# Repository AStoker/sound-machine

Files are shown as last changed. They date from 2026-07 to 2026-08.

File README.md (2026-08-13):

# Sound Machine

ESPHome firmware for a bedside smart sound machine built on a ReSpeaker Flex
(XVF3800 + XIAO ESP32-S3): white/pink/brown noise, voice assistant, an LED-matrix
clock, an SK6812 sunrise crescent, and battery/UPS monitoring.

## Prototype 1, finished

The machine as built and in service: a printed two-tone shell behind a single
acoustic-cloth face, with the knob capping the top.

| | |
|---|---|
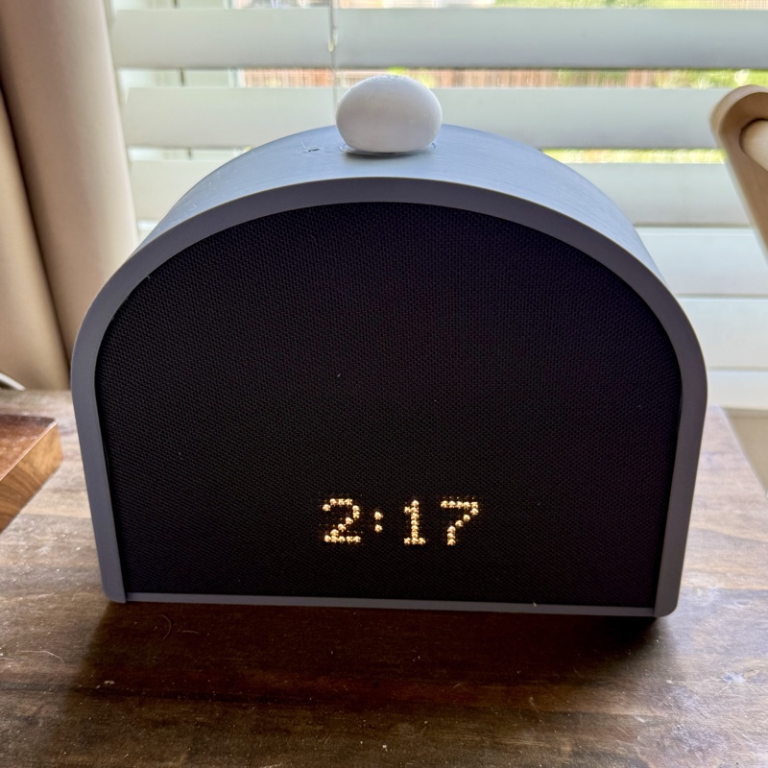
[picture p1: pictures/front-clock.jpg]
Front of the finished sound machine, showing the time on the LED matrix through the cloth face
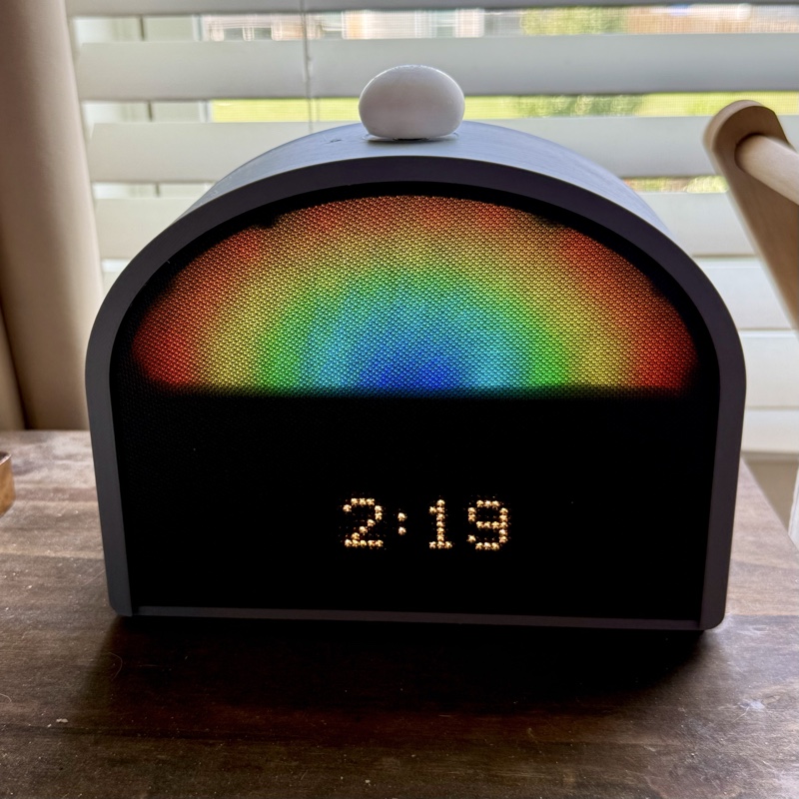
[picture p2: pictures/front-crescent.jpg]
Front view with the SK6812 crescent lit in a rainbow above the clock
|  |  |
| **Resting.** The IS31FL3731 matrix reads through the cloth and nothing else does — the crescent above it is dark and invisible. Brightness tracks room light via the BH1750, so this is the daytime level. | **Crescent lit.** The 48-px SK6812 arc diffused by the same cloth, here cycling hue. It sits in the upper dome; the clock keeps its own space below. Capped at `led_max_pct: 25 %` — see the brownout note in `CLAUDE.md`. |

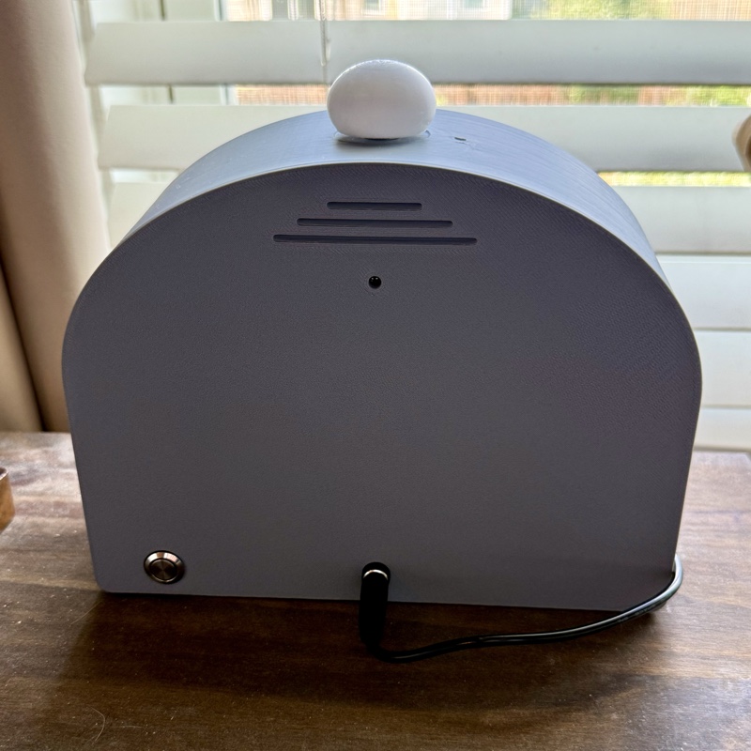
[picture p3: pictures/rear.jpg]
Rear of the enclosure showing the vent stack, the BH1750 light pipe, the power switch and the DC barrel jack


**Rear.** The body is a plain extrusion, so the back is one flat face: the single
wide vent stack up top, the BH1750's light pipe centred below it (the small hole
— that sensor is what auto-dims everything you see in the other two photos), the
power switch, and the centred barrel jack feeding the 3S UPS. The pebble on the
crown is the knob — turn for volume, tap/hold for sound; the ToF's pinhole is the
speck just to its right in the first photo.

## Layout

| Path | What |
|---|---|
| `soundmachine.yaml` | Device core + the package manifest (the build entry point) |
| [`packages/README.md`](packages/README.md) | **The architecture map** — start here to change firmware behavior |
| `packages/settings.yaml` | Every tunable in the build, in one documented file |
| `packages/hw/` | One file per physical part (matrix, crescent, knob, UPS, sensors…) |
| `packages/api/` | The abstraction layer — `display`, `sound`, `light`, `indicator` |
| `packages/behavior/` | Operational logic: presets, gestures, announcements, voice |
| `components/` | Custom ESPHome components, named for their job rather than their chips: `clock_display`, `noise_generator`, `ambience_player`, `background_sound`, `speaker_amp`, `rotary_knob`, `shared_helpers` |
| `sounds/` | On-device audio baked into flash |
| `soundmachine.min.yaml` | Reference minimal device YAML for Home Assistant |
| `secrets.example.yaml` | The secret keys you must provide locally |
| `3d-print/` | The enclosure: parametric geometry, generators, validation, printable solids |
| `pictures/` | Photos of the assembled v1 machine (shown above) |
| [`FUTURE-DEVELOPMENT.md`](FUTURE-DEVELOPMENT.md) | Every open item, one numbered entry each |
| [`RETROSPECTIVE.md`](RETROSPECTIVE.md) | What building v1 taught |

## Running it from Home Assistant (pull latest from GitHub)

The full config lives here on GitHub. Home Assistant keeps only a tiny device
YAML that pulls this repo as an ESPHome **remote package**, so every build
compiles the latest `main`.

1. Copy [`soundmachine.min.yaml`](soundmachine.min.yaml) into your HA ESPHome
   config folder (rename it if you like — the filename becomes the device).
2. Add the keys from [`secrets.example.yaml`](secrets.example.yaml) to that
   folder's `secrets.yaml` with real values.
3. Compile/install from the ESPHome dashboard.

That's it — the device config, the custom `components/`, and the packaged
sub-configs are all fetched from this repo at build time.

### How it works

- Credentials are **substitutions**, not `!secret` — remote packages can't
  contain secret lookups. The minimal device YAML injects them from the local
  `secrets.yaml`, overriding the placeholders in `soundmachine.yaml`.
- The custom components are pulled via a **git** `external_components` source
  (`github://astoker/sound-machine`) so they resolve identically locally and on
  HA. For local component development, push first then build (or temporarily
  switch that source back to `type: local, path: components`).

## Building locally

```sh
# create a secrets.yaml next to soundmachine.yaml with the 5 keys, then:
esphome config soundmachine.yaml     # validate
esphome run soundmachine.yaml        # build + upload
```

## On-device media (the `la_la_sad_source` substitution)

ESPHome resolves a local `file:` path against the config directory of whichever
machine runs the build. When HA pulls this repo as a remote package, that
directory is HA's — not this repo — so a bare `sounds/…` path wouldn't be found
there even though the file lives in the repo. So the media source is a
substitution, `la_la_sad_source`, defaulting to a raw GitHub **URL** that
ESPHome downloads at build time (works everywhere; verified). For local/offline
dev with the repo checked out, override it with the repo-relative path:

```yaml
# in a local dev entry YAML (or temporarily in soundmachine.yaml substitutions)
substitutions:
  la_la_sad_source: sounds/La-la-sad.mp3
```

Any additional flashed audio should follow the same pattern: add a
`<name>_source` substitution (URL default) rather than a bare path. Note the
ordering that implies: the URL only resolves once the file is on `main`, so a
new track is **pushed first, built second** — or built locally with the path
override above.

**Size.** Flashed media is compiled into the app image and shares the 3.75 MB
app partition with the firmware. With both current tracks (`La-la-sad`,
`Crickets`) that image is 3.0 MB, leaving ~760 KB. `esphome compile` prints the
remaining space; check it after adding one.

## Status

**Prototype 1 is built and in service** — printed, wired, assembled, running
(photos at the top). Ongoing work is firmware. See
[`SOUNDMACHINE.md`](SOUNDMACHINE.md) for what the machine does,
[`FUTURE-DEVELOPMENT.md`](FUTURE-DEVELOPMENT.md) for what is still open, and
[`RETROSPECTIVE.md`](RETROSPECTIVE.md) for how it got here.

The full v1 development history is preserved on the **v1 release branch**; `main`
carries the conclusions.

## Notes

- The UPS monitor is **confirmed** as an INA219 at `0x41`. Its shunt value
  (`ups_shunt_ohms`, `0.01 Ω`) is still taken from documentation rather than
  measured — voltage and state-of-charge don't depend on it, absolute current and
  power do.

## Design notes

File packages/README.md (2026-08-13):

# The package layout

The firmware is split into three layers. The split exists so that a change has
exactly one plausible home: a new sensor is a `hw/` file, a new way to reach an
existing subsystem is a verb in `api/`, and a new *rule* about when things happen
is a `behavior/` file.

```
soundmachine.yaml        device core: platform, WiFi/API/OTA, the I2C bus, the manifest
packages/settings.yaml   every tunable in the build, grouped and documented

packages/hw/             THE PARTS.      One file per physical device.
packages/api/            THE ABSTRACTION. One file per subsystem.
packages/behavior/       THE LOGIC.      What the device actually does.
```

## The three layers

### `hw/` — one file per part

Owns a device's component config and the only register/pin-level talk to it.
Also owns *hardware interpretation*: lux to a brightness level, metres to "a hand
is near", volts to a state of charge. Interpretation belongs here because it is
about the physics, not about this device's choices.

A `hw/` file contains no policy. It never decides that a low battery deserves a
warning or that a knob turn means volume.

### `api/` — one file per subsystem

The abstraction layer. Everything else reaches a subsystem **through these
scripts**, never through its hardware. Each api file is the single writer of the
hardware behind it, which is what makes the invariants enforceable:

| api file | is the only writer of | key verbs |
|---|---|---|
| `api/display.yaml` | the display driver | `display_show_code`, `display_show_status`, `display_set_alert`, `display_show_message` |
| `api/sound.yaml` | the audio chain | `noise_play`, `noise_stop`, `ambience_play(name)`, `ambience_stop`, `media_stop`, `volume_apply`, `sound_duck`/`sound_unduck` |
| `api/light.yaml` | the crescent strip | `crescent_off`, `crescent_static`, `crescent_effect` |
| `api/indicator.yaml` | the knob NeoPixel | `indicator_set_hue`, `indicator_flash`, `indicator_glow_set` |

An api file may also own the *mechanism* that its hardware needs and callers
should not have to think about: the display's channel priority and heartbeat, the
indicator's fade and I2C write-throttling, the audio stack's boot gate.

### `behavior/` — the operational logic

Presets, gestures, announcements, boot restores, and the Home Assistant control
surface (selects, switches, numbers, buttons, text). Behavior decides; api does.

## The two rules

**1. Writes go through the api. Reads do not.**

A behavior package must not start the noise generator, build a `LightCall`, or
write an I2C register — it calls a verb. But reading state is free and expected:
`external_media_player->volume`, `id(battery_low).state`, `id(hand_near)`,
`media_player.is_announcing`. Routing reads through scripts would buy nothing —
ESPHome scripts cannot return a value — and would cost a lot of clarity.

**2. Hardware raises events; behavior implements them.**

A `hw/` file with an input on it calls one script per event, named after the
event. The handler is defined in the matching `behavior/` file. That way hardware
declares a contract without knowing who fulfils it, and remapping a control never
touches anything that talks to a bus.

| event script | raised by | implemented in |
|---|---|---|
| `on_knob_turn(clicks)` / `on_knob_tap` / `on_knob_hold` | `hw/knob.yaml` | `behavior/sound.yaml` |
| `on_touch_tap` / `on_touch_hold` | `hw/touch.yaml` | `behavior/light.yaml` |
| `on_hand_near_changed` | `hw/proximity.yaml` | `behavior/sound.yaml` |
| `on_external_power_changed` / `on_battery_low_changed` | `hw/power.yaml` | `behavior/power.yaml` |
| `on_audio_ready` | `api/sound.yaml` | `behavior/sound.yaml` |

These are hard dependencies: ESPHome resolves script ids at validate time, so
dropping a `behavior/` file whose events are still raised fails the build. That
is deliberate — it is the compiler telling you a contract is unmet.

**One event per fact, not one event per subsystem.** `hw/power.yaml` raises a
separate event for each of its two sensors. It used to share one, and the handler
then had to reconstruct *what* had changed from sensor state — which cost a
`has_state()` guard, an extra global, and a paragraph of explanation. A
binary_sensor's `on_state` is already edge-triggered, so one event per sensor
makes "this changed" the event itself.

## Things worth knowing before you edit

**All ids are global after the merge.** ESPHome merges every package into one
config, so a cross-package `id()` reference works — but each id must be defined
exactly *once*. Every file's header lists what it DEFINES and what it CONSUMES;
read those two lines before adding anything.

**Top-level list keys concatenate.** `sensor:`, `script:`, `globals:`,
`interval:`, `esphome.on_boot:` and friends accumulate across packages. That is
how several files can each add their own boot step or their own tick.

**Substitutions are global too, and local wins.** `settings.yaml` is a package
like any other, so the tiny device YAML on Home Assistant can override any value
in it. ESPHome merges packages *before* it expands `${...}`, which is why a
setting defined in one file is usable in all of them.

**The display is split into policy and driver, and not for pluggability.**
`api/display.yaml` decides *what* to show — priority between competing overlays,
expiry, which default view sits underneath them, clock formatting — and
`components/clock_display` draws it. There is one display and no plan for another;
the split earns its keep because those are two unrelated problems. The contract
between them is a struct, `clock_display::Frame`, so it is checked rather than
described: `api/display.yaml` builds one as a local and calls
`id(matrix)->paint(frame)`.

**The driver must self-throttle.** `api/display.yaml` ticks several times a
second and calls `paint()` every time. The driver compares the frame with what it
last drew and returns before touching I2C when nothing changed. ~300 bytes on this
100 kHz bus is ~30 ms of bus time, on a bus that had to be slowed down for the
XVF3800 in the first place.

**Register-level code is a component, not a lambda.** Anything that talks to a
chip in raw registers lives in `components/` as C++ (`clock_display`, `speaker_amp`,
`rotary_knob`, `noise_generator`, `ambience_player`), and the matching `hw/` file is just its
configuration. A YAML lambda is fine for interpreting a reading; it is the wrong
home for fonts, framebuffers and decoders.

**Chips with no NVM repair themselves.** The matrix, the knob's NeoPixel and the
amp all lose their configuration to a glitch on the shared 5V rail, and in every
case the symptom is silent (a dark display, a dead pixel, an amp with its AGC
back on). Each one re-asserts: `clock_display` probes an enable register on a
tick, `api/indicator.yaml` re-sends the pin config whenever the pixel settles at
black, `hw/audio_chain.yaml` re-writes the amp's four registers on a tick. If you
add an I2C part that has to be configured, give it one of these.

**State lives in `globals:`, not in lambda `static`s.** Every file's header lists
what it DEFINES, and that list is how anyone finds the device's state. A `static`
inside a lambda works but appears in no such list, so it is state a reader cannot
know exists. Where the state belongs to a driver rather than to a package, it is a
member variable in the component instead.

**So does derived state that is cached on an edge.** The low-battery alert is a
global maintained by two `on_state` handlers, and an edge that never arrives (or
a state that is already true at boot and then never changes) would leave it
disagreeing with its sensors indefinitely. `behavior/power.yaml` re-derives it on
a slow tick as well, so the events buy latency and the tick buys correctness. Any
future default view computed from a sensor wants the same treatment.

**The crescent's pixel count is not a setting.** It is derived from the enclosure
geometry and lives in `hw/crescent.yaml`. `3d-print/check_docs.py` fails the
build if it drifts from `3d-print/enclosure_geom.py`. See the note in
`../CLAUDE.md`.

## Where to add a thing

| I want to… | Do this |
|---|---|
| tune a number | `settings.yaml`, in the matching section |
| add a sensor or chip | a new `hw/` file; raise events, don't handle them |
| let something new drive the display | call an `api/display.yaml` verb — never `paint()` |
| add a display overlay (transient) | a row in `api/display.yaml`'s overlay table + a setter |
| add a display default view (what replaces the clock at rest) | a row in `api/display.yaml`'s defaults table + a setter |
| add a light preset | an option at the end of `behavior/light.yaml`'s select + a row in **both** its tables (colour *or* effect name) |
| add a noise colour | an option in `behavior/sound.yaml`'s Sound select, after the last colour |
| add a flashed sound | an `audio_file:` entry and a `name:`/`file:` pair under `ambience_player:` in `hw/audio_chain.yaml`, then that **same name** as an option in the Sound select. No new api verb, no second list. The file must be **mono 48 kHz MP3** — see `sounds/README.md` |
| change what a button does | the event handler in `behavior/` — the `hw/` file stays put |
| share a helper between two lambdas | a free function in `components/shared_helpers` — not an `esphome: includes:`, which breaks remote packages |

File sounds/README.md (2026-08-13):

# The flashed audio

Every sound in this folder is an **ambience**: something that runs until the
machine is told to stop, not a clip that ends. `components/ambience_player` decodes
these files straight into a mixer source and rewinds at end-of-file, so a loop
costs a read pointer going back to zero.

That decode path has **no resampler in it**, which is what makes the loop free
and also why the format below is a hard requirement rather than a preference.

- **Firmware side:** `packages/hw/audio_chain.yaml` declares the files;
  `packages/behavior/sound.yaml` offers them in the Sound select.
- **Why it is not a `media_player`:** `components/ambience_player/ambience_player.h`,
  and `FUTURE-DEVELOPMENT.md` T3–T5.
- **The URLs** these are fetched from at build time are in
  `packages/settings.yaml` §11 — the file is downloaded, not read from this
  folder, when the config is pulled onto Home Assistant as a remote package.

## The format

A file that does not match is refused at its first frame and logged. That is
deliberate: the alternative is what a mismatch used to do, which was play at the
wrong speed and the wrong pitch for a whole pass before anyone noticed.

| Requirement | Why |
| --- | --- |
| **MP3** | The only decoder linked in. Not WAV, not FLAC, not Opus. |
| **Mono** | The mixer source is one channel. Stereo is refused, and on a dual-mono file it was only ever doubling the size for nothing. |
| **48 000 Hz** | The mixer's rate. 44.1 kHz is refused. |
| **Xing/Info header** | Keep the VBR header ffmpeg writes by default. `ambience_player` reads its delay/padding fields to trim the codec's priming samples, and that is what makes the wrap sample-exact. Without it every loop grows ~25 ms of silence. |
| **Peak ≤ −2.4 dBFS** | Headroom for the mixer to add a TTS reply on top without clipping. Watch this across a **resample** especially: 44.1 → 48 kHz turns intersample peaks into real ones, which is how La La spent a while clipping 1064 samples at +1.65 dBFS. |
| **Level within a few dB of the others** | So swapping sounds does not need the volume knob touched. The ambiences sit at roughly −17 to −18 dBFS RMS today. |

The recipe, for a file that is **already a good loop**:

```sh
ffmpeg -i in.mp3 -ac 1 -ar 48000 -af "volume=-XdB" -b:a 128k out.mp3
```

Check the decoded peak before trusting `-X`. If the file is *not* a good loop —
if it opens or closes with a fade — see Crickets below.

## How big can a file be?

Flashed audio is compiled **into the app image**, so it competes with the
firmware for one app partition: `0x3C0000` = 3.75 MB, of which the firmware
itself is ~2.4 MB. Both files below plus everything else currently leaves
~780 KB free. `esphome compile` prints the real number ("Smallest app partition
is … N bytes free") — check it after adding one.

## The files

### La La — 48 s, mono 48 kHz 128 kbps (~770 KB)

A composed piece rather than a true ambience: it opens from silence and closes on
a deliberate ~1 s fade, so its loop point is a fade-out into a fade-in rather
than a seam. **That is the music, and it is left alone** — crossfading it would
overlap two different bars (measured 7.1 onsets/second; this is plucked guitar,
not a pad).

It was 44.1 kHz dual-mono, which cost double the bytes for an identical second
channel (L/R correlation 1.0000) and clipped 1064 samples at +1.65 dBFS once
resampled to 48 kHz. Now mono at the same bitrate — so roughly twice the bits per
channel for the same size — and attenuated 4.25 dB to peak −3.06 dBFS.

### Crickets — 59 s, mono 48 kHz 96 kbps (~710 KB)

**This file is a crossfade loop, and that is not recoverable by re-encoding.**

The source recording opened with a 65 ms fade-in and closed with an 85 ms
fade-out, and those two fades met at the loop point — a ~150 ms hole in the
ambience once a minute, which is the loudest thing a sound meant to be
unnoticeable can do. Its last 2 s are now equal-power crossfaded under its first
2 s (sin/cos, which holds RMS flat for uncorrelated noise where a linear fade
would dip 3 dB). That fills the hole and blends out the ~2 dB low-frequency step
that was also across the seam; measured, the wrap is now a shallower dip than an
ordinary moment in the recording. The 2 s that used to be the fades are gone —
hence 59 s, not 61 s.

It is +13 dB from source, which puts it within a few dB of the noise generator at
the same volume setting, while keeping peaks 2.4 dB below full scale.

> **Do not rebuild it by re-encoding an earlier `Crickets.mp3`, and do not trim
> it** — both silently restore the hole. Rebuild it with
> `./scripts/make-crickets-loop.py`, which goes back to
> `sounds/originals/Crickets-original.wav` and owns the whole chain: crossfade,
> then downmix, resample, +13 dB, encode, in that order. `--verify` reports the
> loop point without writing anything.

## Adding one

1. Put the encoded file here and commit it.
2. Add a `*_source` substitution in `packages/settings.yaml` §11, defaulting to
   its raw GitHub URL (a local `file:` path would not resolve on Home Assistant).
3. Add an `audio_file:` entry and a `name:`/`file:` pair under `ambience_player:` in
   `packages/hw/audio_chain.yaml`.
4. Add that **same name** as an option in the Sound select in
   `packages/behavior/sound.yaml`.

There is no new api verb: `ambience_play` takes the name.

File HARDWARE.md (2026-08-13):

# HARDWARE.md

Physical hardware for the Sound Machine (the "Faux Hatch"): a bedside smart
sound machine inspired by the Hatch Restore form factor — noise, voice
assistant, sunrise light, LED-matrix clock, and environmental sensing.

This file is the single reference for *what the parts are and how they connect*.
For **why the firmware is shaped the way it is**, see [`CLAUDE.md`](CLAUDE.md).
For the **project story and goals**, see [`SOUNDMACHINE.md`](SOUNDMACHINE.md).

> **Ground truth:** the tested configuration in the repo YAML is authoritative,
> not this prose. Where a value below is marked *UNCONFIRMED* it has not been
> verified on the hardware — confirm before trusting it.
>
> **Prototype 1 is assembled**, so most of this is now as-built rather than as-
> designed. Anything still marked UNCONFIRMED is a value nobody has actually
> measured, not merely one nobody has got round to — several survived assembly
> because nothing depends on them yet.

---

## Compute + audio core

| Block | Part | Notes |
|---|---|---|
| MCU | **Seeed XIAO ESP32-S3** (seats into the ReSpeaker Flex) | ESP-IDF framework, octal PSRAM @ 80MHz. `board: esp32-s3-devkitc-1`, `flash_size: 8MB` (16MB only if using the "Plus" variant). A **standard (non-Plus) XIAO ESP32-S3 is a functional drop-in** — only D0, D4/D5, D6–D9 are used, so no rear castellated pads are required. |
| Voice / DSP front end | **ReSpeaker Flex, Linear 4-mic (XVF3800)** | 4-mic beamformer + acoustic echo canceller (AEC). Split architecture: a core board plus a separate **linear-4 array board, 110 mm long with 33 mm mic spacing** (2× M3 mounting holes), joined by a 200 mm 24-pin FPC ribbon. The XIAO seats into the core board via **female headers (removable, not soldered)**. **Core board dimensions are not published** — measure them; the enclosure reserves a bay rather than assuming a size. |
| Codec | **AIC3104** (on the Flex) | I2C `0x18`. ESPHome `audio_dac` platform `aic3104`. |
| Amplifier | **TPA2016D2** stereo Class-D | I2C `0x58`. One 4Ω speaker per channel. See "Amplifier notes" below. |
| Speakers | 2× **Seeed Mono Enclosed Speaker 4Ω 5W** (SS114993346) | **50 × 45 × 22 mm sealed box** — a square-bodied enclosure, not a bare round driver. Bridge-tied outputs (see wiring cautions). The 5W rating is pure headroom — the amp tops out ~2.5W/channel into 4Ω, so the drivers loaf and can't be overdriven. **The 50 mm body width is what sets the enclosure width** — see the drawing set. |

The XVF3800 was **DFU-flashed with the 48 kHz Home Assistant I2S firmware**; the
whole audio pipeline runs at 48 kHz to match.

**Flashing caveat:** the ReSpeaker Flex's internal USB (JST) only exposes the
XVF3800, *not* the ESP32. Flashing the ESP32 therefore requires disassembly to
reach the XIAO's own USB-C. This is an accepted tradeoff.

---

## Light

| Block | Part | Notes |
|---|---|---|
| Crescent strip | **SK6812 GRBW**, 60 LED/m | **48 pixels** in **6 cut segments**. MEASURED strip: ribbon **10.0 mm** wide, cut-line pitch **16.5 mm**, **2.13 mm** thick. Data on **GPIO1 / D0**. ESPHome `esp32_rmt_led_strip` (SK6812, `rgb_order: GRB`, `is_rgbw: true`). |
| LED carrier | printed plate, **part 6** | Holds the six segments at the 12 mm standoff; screws to the back of the front module. See [`3d-print/README.md`](3d-print/README.md). |
| Diffuser | Glowforge-cut opal acrylic, **part 7** | 3 mm, generated as [`3d-print/diffuser.svg`](3d-print/diffuser.svg). **Notched** — see below. |

The crescent is a **flattened half-ELLIPSE, 89 × 62.7 semi-axes** — not a half
circle. The crown was flattened (`CROWN_K = 0.74`) to get the dome printable in
one piece on a 220 bed, so the arch is 0.74 × as tall as a true semicircle.

Row layout, bottom row first, flat side down — used by the Circadian Sunrise
effect:

| row | chord | px | ribbon (n × 16.5) | y above baseline |
|-----|---|----|---|---|
| 0 | 177.8 | 10 | 165.0 | 2.60 |
| 1 | 174.1 | 10 | 165.0 | 13.00 |
| 2 | 165.2 | 9 | 148.5 | 23.40 |
| 3 | 150.0 | 8 | 132.0 | 33.80 |
| 4 | 126.3 | 7 | 115.5 | 44.20 |
| 5 | 87.7 | 4 | 66.0 | 54.60 |

**Row pitch is 10.4, not 16.5.** It is derived, not chosen: the flattened crown
leaves only 62.7 mm of height, so the pitch is whatever gets the most pixels on,
floored at the **ribbon width** — the rows BUTT, edge to edge. That floor used to
carry a 1 mm gap and it cost three pixels: at an 11.0 pitch the crescent holds
45, at 10.4 it holds the whole 48-px reel on the same shell height. Closing the
gap was free. The grid is deliberately not square — rows are much closer together
than the pixels within a row.

**There is no fade band.** The LED field *is* the diffuser ellipse; the old
R96-inside-R117 arrangement with a 21 mm unlit band is gone. Tightest
LED-body-to-diffuser-edge gap is **2.95 mm**.

> ### ⚠️ What sets the pixel count: the ribbon, not the LED
> Every earlier layout measured the **LED body**. The thing that has to fit the
> cavity is the **ribbon**: a cut segment of *n* pixels is `n × 16.5 mm` long,
> not `(n−1) ×`, because the cut lines sit half a pitch outboard of the end LEDs
> and you cannot trim past them without losing the solder pads. On the bottom row
> that is 6.9 mm more than the LED span — an 11-pixel row is a 181.5 mm strip
> going into a 181.0 mm cavity. It never fit.
>
> The ribbon is also 10.0 mm tall against the LED's 5.2, so what must fit is a
> **rectangle**, and its binding corner is the top one.
>
> With the rows butting, `CROWN_K = 0.74` holds exactly **48** — the whole reel.
> It held only 45 while the pitch carried a 1 mm gap, and recovering 48 that way
> would have needed `CROWN_K = 0.80` and a taller shell.
>
> The cap lives in `enclosure_geom.ribbon_cap()` and is folded into
> `_crescent_row_cap()`, so it cannot be silently missed again.

> ### ⚠️ The grid is strongly non-square
> Rows are **10.4 mm** apart — butted, ribbon edge to ribbon edge — against
> **16.5 mm** between pixels along a row. A sweep up the crescent therefore
> covers ground far faster than the same sweep across it. **Any effect with
> vertical structure needs re-checking against this**, the Circadian Sunrise
> especially. Row 5 is 4 px, so there is no single-pixel apex.

`packages/hw/crescent.yaml` carries `num_leds: 48` and, as a single substitution
at the top of the file, `crescent_rows: "10, 10, 9, 8, 7, 4"`.
`enclosure_geom.crescent_rows()` is the source of truth; `gen_drawing.py` prints
the table on every run, and `check_docs.py` fails the build on a mismatch.

> **History / drift:** earlier design notes referenced a **144 LED/m** strip, an
> **XL6009 boost converter** and an **R80 / R96 / R117 circular** crescent. The
> current build is **60 LED/m on a flattened ellipse, powered directly from the
> UPS 5V rail** (~0.73 A at the 25% cap — see the power budget below). The full
> table of what changed from the original design is in
> [`RETROSPECTIVE.md`](RETROSPECTIVE.md) §4.

---

## Display

| Block | Part | Notes |
|---|---|---|
| Clock | **2× IS31FL3731 charlieplex 16×9 matrix** ([#2946](https://www.adafruit.com/product/2946), STEMMA QT / I2C) | `0x74` (left) + `0x75` (right), tiled into one 32×9 display. No native ESPHome component, so `packages/hw/matrix.yaml` drives it with **raw I2C register writes**. Auto-dims from the BH1750 via `ambient_level`. The second board needs its **ADDR jumper** moved off `0x74` (`0x75`/`0x76`/`0x77`) — set `matrix_address_2` to match. |

**Chip model.** Pixel `(x,y)` → LED `x + y*16`; PWM byte at `0x24 + LED`
(144 LEDs); LED-enable regs `0x00–0x11`; bank select via command reg `0xFD`
(`0x00` = frame 0, `0x0B` = function/config).

**Single vs dual.** The panel count is the length of `addresses:` in
`packages/hw/matrix.yaml` — one entry brings up the left panel alone with a
compact 3×5 font; two give the full 32×9 display with a 5×7 font for a real
clock. Horizontal tiling: panel *p* owns logical columns `[16p … 16p+15]`. In
single mode the second address is never touched, so an unwired 2nd board causes
no I2C errors — bring one panel up first.

**Inter-panel gap.** Two panels butted together leave a physical ~1-pixel dead
column between them (`matrix_panel_gap`, default 1). The renderer lays content out
in *physical* columns (gap included) and maps back to logical columns per draw, so
the clock stays centred across the seam and 2-character codes fall one per panel.
Adjust `matrix_panel_gap` if your panels sit farther apart or flush.

**No NVM.** A glitch on the shared 5V rail returns the panels to their power-on
state — shut down, all LEDs disabled — and nothing would report it. The driver
reads an enable register back every `matrix_probe_interval` and re-initialises any
panel that has forgotten its configuration.

What it shows, and in what order, is not this file's business: `api/display.yaml`
owns that (overlays **message → status → code**, over a default view of
**alert → clock**) and hands the driver a resolved frame.

---

## Sensors (STEMMA QT I2C daisy-chain)

| Sensor | Part | Address | Status |
|---|---|---|---|
| Ambient light | **BH1750** | `0x23` | **Implemented** — publishes the shared `ambient_level` that auto-dims the display and the knob pixel (`packages/hw/ambient_light.yaml`). Mounted rear, behind a light pipe **centred in the back wall** (see the enclosure drawing). |
| Rotary encoder | **Adafruit seesaw rotary encoder** | `0x36` | **Implemented** — volume knob + push (tap/hold) via the vendored `seesaw` component. Its built-in **NeoPixel** (seesaw GPIO **6**, `knob_led_pin`) is also live: colour = volume, blue → green → red (`packages/hw/knob.yaml` for the inputs, `packages/api/indicator.yaml` for the pixel). |
| Real-time clock | **DS3231** (driven as `ds1307`) | `0x68` | **Implemented** — battery-backed time source; HA syncs it when connected. |
| Time-of-flight | **VL53L0X** | `0x29` | **Implemented, in a limited role** (`packages/hw/proximity.yaml`) — a nearby hand pre-lights the knob NeoPixel, and that is *all* it does. The historical **touchless wake** gesture is still not built. **It does not measure distance in this enclosure:** the 3.5 mm bore is shared by emitter and receiver with no septum, so crosstalk pins every reading at ~0.024 m and the firmware detects *deviation* from that baseline instead (root cause + fix: **H4** in `FUTURE-DEVELOPMENT.md`). Mounts on the **crown, just right of the volume knob**, board turned longwise front-to-back to clear the encoder breakout — see the enclosure drawing. |

> The BH1750, seesaw, DS3231 and VL53L0X are all live in the config. The ToF is
> deliberately **non-essential**: if it is unwired or fails its probe, the knob
> pixel still works off volume changes alone.

### Board outlines and mounting holes — READ FROM THE VENDOR PCB FILES

Every one of these breakouts is mounted on a printed boss, so the enclosure needs
their **outline and hole pattern**, not just their address. Adafruit publishes the
Eagle board for each; the numbers below are read out of the `<element
MOUNTINGHOLE_*>` entries and the layer-20 outline wires, so they are **confirmed,
not measured off a photo or a fab print**. Keep these links — they are the source
of truth, and `3d-print/check_docs.py` asserts the geometry against them.

| Board | Adafruit PCB repo | Outline | Mounting holes |
|---|---|---|---|
| I2C QT Rotary Encoder (#4991) | [Adafruit-I2C-QT-Rotary-Encoder-PCB](https://github.com/adafruit/Adafruit-I2C-QT-Rotary-Encoder-PCB) | 25.4 × 25.4 | **4** × Ø2.5 plated, pitch **20.32 × 20.32** |
| VL53L0X ToF (#3317) | [Adafruit-VL53L0X-ToF-Distance-Sensor-PCB](https://github.com/adafruit/Adafruit-VL53L0X-ToF-Distance-Sensor-PCB) | 25.4 × 17.78 | **4** × Ø2.5 plated, pitch **20.32 × 12.70** |
| BH1750 (#4681) | [Adafruit-BH1750-PCB](https://github.com/adafruit/Adafruit-BH1750-PCB) | 25.4 × 17.78 | **4** × Ø2.5 plated, pitch **20.32 × 12.70** |
| DS3231 RTC (#5188) | [Adafruit-DS3231-Precision-RTC-Breakout-PCB](https://github.com/adafruit/Adafruit-DS3231-Precision-RTC-Breakout-PCB) | 25.4 × 17.78 | **2** × Ø3.0 plated, pitch **20.32**, TOP pair only |

**One footprint family, one exception.** All four sit on the same grid: holes
**2.54 mm (0.100″) in from every edge** of a 25.4 mm-wide board. The DS3231 is the
only one that does not populate all four — Adafruit fits just the **top** pair
(and drills those Ø3.0 rather than Ø2.5). The Ø3.0 does not change the fastener:
these are clearance holes and the enclosure drives **M2.5** self-tappers into its
bosses throughout.

> **Note the ToF and BH1750 share an outline and a hole pattern** — they are the
> same STEMMA QT blank. Do not infer from that that they mount the same way: the
> ToF goes on the crown turned **longwise front-to-back**, so its 20.32 pitch runs
> along the machine's depth and its 12.70 pitch across the width. The BH1750 sits
> on the rear wall the natural way up, so its 20.32 runs across the width.

**These were guesses until 2026-07-30, and all three were wrong.** The encoder,
ToF and BH1750 were each modelled with an invented **two**-hole pitch (20.0, 20.0
and 15.0, every one marked `(?) MEASURE`) when all three carry four holes. The
enclosure now takes the real patterns from `qt_hole_offsets()` in
`3d-print/enclosure_geom.py`; see [`3d-print/README.md`](3d-print/README.md) for
what that changed about the dome.

---

## Power

| Block | Part | Notes |
|---|---|---|
| Pack / UPS | **Waveshare UPS Module 3S** (3× 18650 in series) | **60 × 93 mm board**, M3 mounting holes, cells in holders on the board. Provides the **5V / 5A** rail; runs charge + discharge simultaneously (true UPS). **93 mm will not lie down in a 59 mm interior, so the board STANDS VERTICALLY against the rear wall** (~24 mm deep — confirm with cells fitted). That also puts its barrel jack on the wall that has the cutout. |
| Charge input | **DC barrel jack** on the UPS board, **12.6 V 2 A** | **Not USB-C.** The only USB-C on the build is the XIAO's own flashing port, which is internal (see the flashing caveat above). The enclosure therefore needs a barrel-jack cutout in the rear wall, not a USB opening. Jack body clearance and its height on the board are **UNCONFIRMED** — measure the as-built. |
| Monitor | **INA219** | **CONFIRMED.** Found at **`0x41`** on the boot I2C scan and reading consistently on `platform: ina219` — 12.46 V pack, 4.153 V/cell across 3S, 98 % SOC, all mutually agreeing. Not an INA226. Sign convention also confirmed: **discharging reads negative**, and `External Power` / `Battery Charging` track the real plug state. |
| Shunt | series shunt on the UPS board | **UNCONFIRMED** (`ups_shunt_ohms`, currently `0.01 Ω`) — taken from the module's documentation, never measured. Bus voltage and SOC do **not** depend on it; absolute **current and power do**. Idle reads ~0.15 A, which is plausible against the estimated draw but is not verification. If current is ever ~10× off, this is why. |

**Pack thresholds (3S, pack volts = per-cell × 3):**
full `12.6V` (4.20 V/cell) · low-warn `10.2V` (3.40 V/cell) · empty `9.0V`
(3.00 V/cell) · low-SOC flag at `15%`.

State-of-charge is **estimated from pack voltage** against a Li-ion OCV curve
(no coulomb counter on the board), so it reads low under heavy load (bright
sunrise + loud audio sag the pack) and recovers when the load drops. Treat
`<20%` as "plug it in," not a fuel gauge.

**Sign convention is unverified:** current is filtered `×-1` so discharge reads
negative. Confirm on the bench; if discharge reads positive, flip the comparison
in the `battery_charging` sensor and drop the multiply filter.

> **History / drift:** battery retention was previously an *open decision*
> (candidate: LiPo + USB-C, Qi2 wireless charging already ruled out). It is now
> **resolved in favor of the Waveshare 3S UPS module**, which also fixed the
> earlier undecided 5V-rail source for the LEDs and amp.

### Power budget (5V rail, 5A ceiling)

| Load | Worst-case draw |
|---|---|
| 48× SK6812 RGBW, full all-channel white | ~2.9 A |
| TPA2016 into 2× 4Ω at clipping | ~1.3 A (set by the 4Ω load, not the 5W driver rating) |
| Flex + XVF3800 + ESP32-S3 + sensors | ~0.5 A |

The crescent is **hard-capped at 25% of full white** in firmware
(`led_max_pct`, applied via `color_correct`) → ~0.73 A for the strip, ~2.5 A
total of the 5 A budget. This is a physical PWM ceiling, not just a UI limit, and
it also keeps the sealed dome from overheating.

> **⚠ That 25% is a STOPGAP standing in for a hardware fix that has not been
> done.** The cap was **65%** (~1.9 A, ~3.7 A total — comfortably inside the 5 A
> budget on paper) and it **still browned out the ESP32 in practice.** Headroom
> on paper is not the constraint; the *transient* is. Worse, the failure does not
> self-clear: **the strip latches its last frame independently of the MCU**, so
> once the rail sags far enough to reset the ESP32, the LEDs keep drawing the same
> current straight through the reboot loop.
>
> The real fix is **bulk capacitance at the strip and ESP32 5V inputs** plus
> verifying the feed topology — tracked as **H1** in
> [`FUTURE-DEVELOPMENT.md`](FUTURE-DEVELOPMENT.md). **Do not raise `led_max_pct` before
> that is installed**, and when you do, raise it in small steps while watching for
> the same failure. The brightness you are looking at is a symptom of an unfixed
> power problem, not a design choice.

---

## Pin map

The ReSpeaker Flex fixes the I2S pins; everything else is on **one shared I2C
bus**, so no extra GPIO is consumed per peripheral.

| GPIO | XIAO pin | Function | Owner |
|---|---|---|---|
| GPIO7 | D8 | I2S WS / LRCLK | Flex (fixed) |
| GPIO8 | D9 | I2S BCLK | Flex (fixed) |
| GPIO43 | D6 | I2S mic DIN | Flex (fixed) |
| GPIO44 | D7 | I2S spk DOUT | Flex (fixed) |
| GPIO5 | D4 | **I2C SDA** | shared bus (all sensors, display, codec, amp, XVF3800) |
| GPIO6 | D5 | **I2C SCL** | shared bus |
| GPIO1 | D0 | SK6812 crescent data | LED strip |
| GPIO4 | D3 | Capacitive preset touch — **both** shoulder pads, one net (TOUCH4) | ESP32-S3 native touch (`esp32_touch`) |
| GPIO2 | D1 | *reserved* — TOUCH2, free if the pads ever need splitting | — |

Notes:
- **D4/D5 for the audio/sensor I2C is the tested, source-of-truth mapping** — do
  not "correct" it from schematic-derived assumptions.
- **Verify D0/GPIO1 is exposed and unused** on the Flex breakout pads (the LED
  data line moved here because GPIO43 now belongs to the I2S mic).
- **Two touch pads on ONE pin.** Copper strips (~40 × 22 mm) bonded to the
  *inside* of each upper shoulder, both wired to GPIO4/D3. Self-capacitance
  sensing measures the whole electrode net, so two pads on one net behave as a
  single electrode that happens to be split in two — touching either half gives
  the same delta. One binary sensor, one threshold, no OR logic.
- **Join the two leads at the MCU, not across the crown.** Each pad's lead drops
  down the inside of its own flank to the floor and they meet at the XIAO. The
  wire count is identical either way, and it keeps a ~200 mm antenna out of the
  crown — which is exactly where the SK6812 data line, the I2S lines and the
  STEMMA chain all run. This is the one routing decision that makes or breaks it.
- Sharing costs: the baseline capacitance roughly doubles while the finger delta
  does not, so relative sensitivity drops (still comfortably usable), and a
  side-to-side sensitivity mismatch cannot be trimmed out with per-pad
  thresholds. **GPIO2/D1 (TOUCH2) is kept free as the escape hatch** — splitting
  to two channels later is one wire at the MCU plus a few lines of YAML.
- **`measurement_duration` is not optional on the S3.** ESPHome's default derives
  `charge_times = 65535` — the hardware maximum — which saturates the 22-bit touch
  counter: `value` pins at 4194303, the benchmark follows it there, and the delta
  is permanently 0, so the pad can never fire whatever the threshold is. A pad
  reading exactly 4194303 is this, not a wiring fault. Set in
  `packages/hw/touch.yaml`; measured baseline with it is ~47,500.
- The touch threshold (`touch_threshold`) must be **calibrated** via
  `esp32_touch: setup_mode: true` before it works reliably. Thin the wall
  locally to ~1.6 mm behind each pad.
- **AS-BUILT, UNCONFIRMED — which electrode is actually installed.** The design
  above is two 40 × 22 mm shoulder strips behind wall thinned to 1.6 mm. The
  calibration in `packages/settings.yaml` (`touch_threshold: 2500`) was taken
  against a **single 76 × 76 mm copper-tape pad behind the unthinned 2.5 mm
  wall** — a different electrode at a different dielectric distance. Both numbers
  are recorded because it is not documented which one went into the assembled
  machine. **Re-calibrate if the pads are ever changed to the designed pair**;
  a smaller electrode at a shorter distance moves the baseline and the delta.
- **Measured separation is large**, so the exact threshold is not delicate:
  untouched noise sd 34 counts with a worst excursion of +50, presses 6363–12731.
  2500 is deliberately biased high within that gap — the realistic false triggers
  are a hovering hand and gripping the dome, neither of which the bench data
  sampled.
- **Watch for false triggers:** the shoulders are also where you grip the device
  to move it. If that bites, require a short hold rather than a tap — note the
  gesture window has a dead band (`gesture_tap_max` 0.8 s → `gesture_hold_min`
  1 s), so a 0.9 s press currently fires nothing.
- No SPI is used (the old MAX7219 display was replaced by the I2C matrix).

---

## I2C address map (single bus, GPIO5/6 @ 100 kHz)

| Addr | Device | | Addr | Device |
|---|---|-|---|---|
| `0x18` | AIC3104 codec | | `0x58` | TPA2016 amp |
| `0x23` | BH1750 ambient light | | `0x68` | DS3231 RTC |
| `0x29` | VL53L0X ToF | | `0x41` | UPS INA219 |
| `0x2C` | XVF3800 | | `0x74` | IS31FL3731 matrix (left) |
| `0x36` | seesaw encoder | | `0x75` | IS31FL3731 matrix (right) |

**Bus tuning:** the bus runs at **100 kHz** with a **1 ms timeout**. The slower
edges tolerate the extra cable capacitance and pull-ups from the STEMMA sensor
chain, which was starving the timing-sensitive XVF3800; the timeout gives the
XVF3800 room to clock-stretch while its firmware boots. If it's still flaky with
everything reconnected, drop toward 10 kHz.

---

## Amplifier (TPA2016) notes — read before touching audio

- **Stereo, bridge-tied outputs.** Every output terminal swings; there is **no
  output ground**. Do **not** common the two speakers' negative leads and do
  **not** tie any output to GND — either shorts half a bridge and can kill the
  amp.
- **Its AGC is deliberately OFF (compression 1:1).** The XVF3800's AEC can only
  cancel a *linear* echo path; an active compressor downstream of the DAC makes
  the gain time-varying and breaks wake-word-over-noise. All volume control
  stays in software (in the AIC3104 upstream).
- The chip has **no NVM** — a 5V-rail glitch reverts it to factory defaults
  (AGC back on). The custom `speaker_amp` component rewrites its config at boot, and
  register write **order matters** (compression before gain).

---

## Optional / experimental

*(The IS31FL3731 matrix used to live here as an experiment. It is the shipped
clock display now — see the Display section.)*

---

## Enclosure (context)

Main body **202 × 79 × 155.7 mm**. Form: a letter **"D" lying on its long flat
side, extruded along the depth** — flat bottom, straight sides, and a **flattened
half-ellipse** top (semi-axes `W/2` × `CROWN_K·W/2`), **concentric with the LED
crescent**. The crown is a *cylinder*, not a sphere: it curves in front view and
is flat in side view. Front facade is acoustic grille cloth over white opal
cast-acrylic (Glowforge-cut). Access is via a bottom slide-in plate. Fusion 360.

> ### ⚠️ The speakers are ROTATED 90°, and that is what made it printable
> The Seeed body is 50 × 45 with a nub centred on each **45 mm** face. Standing it
> on its side puts those nubs **top and bottom** instead of left and right, which
> takes the mounting post out of the WIDTH chain and puts it in the height — where
> there was slack — and narrows the body from 50 to 45. With the mic array also
> moved **above** the speakers, the middle of the facade only carries the 86 mm
> matrix pair rather than the 110 mm array.
>
> Together that took the body from **258 → 202 wide**, which is what lets the dome
> and the front module each print as **one piece** on a 220 bed. At 258 it was
> proven impossible: the best of ~40,000 orientations was still 9.2 mm over.
> Acoustically it is free — a sealed box with a round driver does not care which
> way up it is.
>
> **The flanks now carry nothing.** Two screws on one vertical centreline fix x, y
> and rotation between them, so there are no seat rings and no side ribs. The
> width chain budgets `SPK_FLANK = 1.0 mm` per flank as pure clearance and it
> butts straight onto the dome's rib keep-out — anything appearing there jams the
> module on assembly.

> **W and H are both derived, not chosen.** Width is set by what sits side by side
> on the facade: `W = 2 × (3.6 edge + 4 boss keep-out + 1 flank + 45 body + 1
> flank + 3 gap + 43.18 half-matrix) = 202`.
>
> The arch's horizontal semi-axis *is* `W/2`, so **every 2 mm of width adds
> `CROWN_K` mm of height**. `CROWN_K = 0.74` — flattening the crown is the only
> lever on height once the width is fixed, and it is not purely cosmetic: it also
> sets how much crescent there is to lay LEDs on. See the 45-pixel note above.
>
> ### ⚠️ The edge budget is the dome's RIB, not the outline
> The module **slides up a groove**, and the dome's retaining rib grips the outer
> `RIB_W` of its **back face** along both flanks and the arc. Anything standing
> proud of that back face inside the band — a speaker post, a stiffening rib, the
> diffusion cavity wall — **jams the module on assembly**. A 2D view cannot show
> this: on the flat it just looks like clearance to the outline, and the outline
> is not the constraint. So the width chain spends `BOSS_EDGE = RIB_W + 1`, not a
> driver clearance. Three consequences:
> - **`RIB_W` is 3 mm, not 5.** The rib only has to stop the module tipping
>   forward (the bottom plate already traps it), and the keep-out is multiplied
>   four times across the width. 5 → 3 gave back 4 mm of body width.
> - **`RIM_MIN` is derived, not chosen.** Walking out from the crescent —
>   `DIFF_MARGIN` + `CAV_WALL` + `BOSS_EDGE` + `REVEAL` — gives the smallest rim
>   the shell can physically carry. Only if that comes out under the aesthetic
>   minimum does 12 mm win.
> - **The bottom edge is exempt.** It is the open end the module slides in
>   through, and the bottom plate captures it there instead.
>
> `gen_front_plate.py` intersects every boss with this band and reports the
> volume, so it cannot regress silently.
>
> **The diffuser sits at the concentric maximum, and the LED field IS the
> diffuser.** The diffuser ellipse is `(W/2 − RIM_MIN) × (CROWN_K·W/2 − RIM_MIN)`
> = **89 × 62.7**, so the crescent is as big as the shell allows and the rim stays
> at 12 mm. There is no separate, smaller LED arc any more and no fade band — the
> field fills the ellipse and the glow reaches the edge.
>
> ### ⚠️ Clearance is a TRUE distance to the ellipse, not a chord
> Every earlier check measured how far a pixel sat from the crescent
> *horizontally* (the chord) and, at the apex, *vertically*. On a circle those
> agree with the real distance; **on an ellipse they do not**, and the binding
> case is the diagonal one — an outer pixel two rows down from the apex, where
> the boundary is falling away steeply. That is how a crown shipped with its top
> LED body standing **0.58 mm outside the diffuser** while every check read clear.
> `enclosure_geom.ell_dist()` now returns the true point-to-ellipse distance and
> everything downstream measures with it.

Parts, all generated as STLs in [`3d-print/models/`](3d-print/models/):
**dome** (open front + open bottom, integral rear wall) · **front module** ·
**bottom plate** · **LED carrier** · a printed **pebble knob** on the crown for the encoder. The
front module carries the clock matrices itself, so `matrix-tray.stl` is no longer
in the assembly — it survives as a standalone part.

The **front module is one printed part**: facade + diffuser pocket + diffusion
cavity + matrix posts and clips + speaker seats + mic channel. The diffuser
itself stays a
separate Glowforge-cut opal acrylic that drops into a pocket from behind. It
**slides up** into grooves in the dome and is trapped by the bottom plate — no
fastener touches the facade. The module is **wrapped in acoustically transparent
cloth**, so the groove is sized for cloth + module + cloth (5.6 mm for a 4 mm
module) and the module's own outline is shrunk by one cloth thickness so the
wrapped assembly still slides.

The **bottom plate is the chassis**. Fixing is **6× wall lugs**: pads that
project inward off the dome wall with a blind heat-set hole, so the screw comes
up through the plate and grabs the lug. Lugs sit at the perimeter where the plate
needs support anyway and cost no floor area — which matters, because the floor is
fully spoken for. There is **no lug on the front edge** (the speaker boxes own
both front corners, the tray owns the middle); the plate's front edge is captured
between the seating ledge and the front module's bottom edge instead.

Mounting inside:

| Part | Where | How |
|---|---|---|
| UPS 3S | rear wall, centred | Board **stands vertically**; M3 through its own mounting holes into posts/brackets rising from the bottom plate. Its barrel jack lines up with the rear cutout. |
| ReSpeaker Flex core | **rear wall, above the UPS** | Mounted **vertically**, flat against the wall on 3 mm standoffs, 4× M3. Bare board **52 × 70 × 20 deep** at the XIAO; the 3.5 mm jack and the mic ribbon overhang the two short (52 mm) edges, so reserve a **110 mm envelope** in that direction. Hole pitch **45 × 63** (measured 42 × 60 inside-edge to inside-edge, 2 mm edge to hole outside → Ø3). The rear wall is reachable the moment the front module is out, and this keeps the floor clear. |
| Linear-4 mic array | front module | 2× M3 into the mic channel behind the ports, with a gasket land per port. |
| TPA2016 | **rear wall, flush, beside the UPS** | Not a side wall: the sides are only vertical *below* the springing line and the speaker boxes own all of that; above it the sides are the curved crown, no good for a flat board. |
| Speakers | front module | **Hang on nubs, TOP AND BOTTOM, not a baffle bolt pattern.** The bodies are **rotated 90°**, so the two nubs — one centred on each 45 mm face — point up and down. Their landing face is **7 mm behind the speaker's front face**, so the module carries a **post above and below each body, on its vertical centreline**, 10 × 6 mm, standing 7 mm proud of the back face, with an M3 running front-to-back into it (inserted **from behind**, through the nub). **The flanks carry nothing** — no seat rings, no side ribs; two screws on one line fix x, y and rotation between them. |
| LED carrier | front module, behind the cavity | 2.5 mm plate, **6× M2.5** into ramped pads on the **inside** of the diffusion cavity wall. Screws, not clips — see the note below. |
| Diffuser pane | front module, in its pocket | Drops in **from behind** and is glued round its edge. It must pass the carrier pads on the way, so it carries six **round notches** at the pad angles — round because the pad is a cylinder, which makes the bite 26% smaller than a square one and so leaks 26% less undiffused light. Generated, not hand-drawn. |
| Clock matrices | front module, **directly** | ⚠️ **The two boards are only loosely soldered to each other**, so the frame cannot treat them as one part. Each board is located by its **own two posts** (Ø1.85 through its Ø2.0 diagonal holes) and seats on two pads in the clear margin above and below its LED field; the pair is then clamped by **six cantilever clips — two on each long edge, one at each end**. A pocket would locate the *pair*, and the pair is exactly the thing that is not rigid. No tray, no pocket. |

See sheet 2 of the drawing set for the joint, the fixings and the clearances,
and [`gen_front_plate.py`](3d-print/gen_front_plate.py) for the printable part.

> **The front module prints WHOLE.** At **194.8 × 148.1 mm** it fits a 220 mm bed
> (Flashforge Adventurer 5M Pro) with 25.2 / 71.9 mm to spare. It used to be
> 250.8 wide and had to split at x = 73.8 with a 5 mm Z-lap; rotating the
> speakers and lifting the mic array removed the need. The seam logic is retained
> in `gen_front_plate.py` behind `NEEDS_SPLIT` — currently **off**, and it
> re-enables automatically if anything pushes the part back over the bed.

> ### ⚠️ Why the LED carrier is screwed, not clipped
> A cantilever/snap arrangement is used elsewhere on this part (the clock
> matrices) and would be consistent — but it does not work here, for two
> independent reasons:
>
> **The clips would have nowhere to deflect.** A clip gripping the plate's edge
> has to flex *outward*, and outboard of the cavity wall there is **0.9 mm**
> before the dome's retaining-rib keep-out. That is the same budget that rules
> out outward mounting ears. Clips that deflect *inward* need the plate to sit
> inside the cavity, and then it cannot seat on the wall's back face — which is
> the datum the whole air gap is referenced to.
>
> **Clips hold a plate wherever the worst clip decides.** The carrier's one job
> is a uniform 12 mm standoff across a 185 mm span. Six screws pull it onto a
> hard seat and take up print variation; six clips leave it sitting on whichever
> hook came out proudest. On FDM, over that span, that is the difference between
> an even glow and a visibly brighter band.
>
> Screws also make the strips serviceable, which matters — five soldered
> segment-to-segment joints are the most likely thing on the build to need rework.

**The clock aperture is one open rectangle** — 84 × 23, no per-pixel holes.
Through a 4 mm facade a per-pixel tunnel would be a light pipe and would gut the
viewing angle; one open window avoids that and avoids a registration problem.

**Rear wall** (a true flat face, same "D" profile as the front — the body is an
extrusion). The BH1750 light pipe and the DC barrel jack are **centred on the
width**. The jack is a **panel-mount part on a flying lead**, not the UPS board's
own connector poking through, because the UPS is no longer centred.

> **The UPS and the Flex no longer stack.** The flattened crown took the interior
> height to 157.5 and 93 (UPS) + 70 (Flex) is 163. They sit **side by side** on
> the rear wall instead — UPS right (x 120–180, on the floor), Flex left
> (x 5–115, lifted to y=16 so it clears the fixing lugs). That is the one axis
> that got roomier when the array came off the flanks. The TPA2016 moved to the
> **floor**, in the 12 mm slot under the lifted Flex; the rear wall has no room
> left.

<!-- Canonical current state. check_docs.py asserts these against the geometry;
     do not reword them. Prose elsewhere explains WHY, these say WHAT. -->
**Vent stacks: 1** · **RTC mounts on: rear wall**

> **The rear wall is the most crowded face in the build** — UPS, Flex, amp, lux
> pipe, jack and vents all land on it, so `rear_wall_clearances()` checks every
> pair rather than trusting the eye. Two consequences:
> - **The vents are ONE wide stack above the light pipe.** This was two stacks
>   flanking the UPS, on the reasoning that a centred stack would sit behind the
>   Flex and bake it — true only of a stack placed *level with* the Flex. Lifted
>   clear above it (y 132–144, over the pinhole) a single stack has the same
>   objection answered, and the two flanking stacks were fencing off both upper
>   quadrants of the wall — the largest clear areas on it — for 432 mm² of
>   opening. One stack of 3 × 72 × 2 gives the identical free area and hands both
>   quadrants back. That is what let the RTC come off the bottom plate.
>   Slot height is capped by the louvre, not by space: the anti-peek geometry
>   only works while the slot is no taller than `VENT_RISE`, so the area is
>   bought with **width**, which is free.
> - **Both rear fixing lugs are left of centre** (x 55 and 105). The UPS owns the
>   rear-right corner of the floor. The plate is still carried at six points
>   round the perimeter, just not symmetrically.

Front-face layout, bottom-up: **speakers flank the matrix pair**, the **mic array
sits ABOVE both**, then the crescent, then the crown.

> ### ⚠️ The mic array clears the speaker BODY, not the post
> The array used to sit above `SPK_SEAT_Y1` — the top of the nub post — which
> lifted it 6.35 mm for no reason. The post is only **10 mm wide** and stands on
> the speaker's **centreline** (x = 31.1 and 170.9); the 110 mm mic PCB spans
> x = 46–156. They overlap in y by 3.35 mm and **never in x**, with 9.9 mm to
> spare. So the array only has to clear the body, and that 6.35 mm went into a
> shorter shell and a taller crescent.
>
> This is why post width is sized by the **nub** (`SPK_NUB_H + 2 × wall`) and not
> scaled off the body — a post at 0.60 × body width reaches x = 44.6 and hands
> the whole saving straight back.

> **Drawing set** — three generated sheets in [`3d-print/`](3d-print/), plus the
> README beside them for the constraints they turned up:
> [`enclosure-drawing.svg`](3d-print/enclosure-drawing.svg) (shell),
> [`enclosure-internals.svg`](3d-print/enclosure-internals.svg) (front module,
> joint, fixings, chassis), and
> [`enclosure-wiring.svg`](3d-print/enclosure-wiring.svg) (the I2C chain and
> where each board sits — generated from *this* file).

> **History / drift:** earlier notes described a **five-part** frame (main body,
> front facade, bottom plate, LED bracket, **charging base**) with a **T-shaped**
> diffuser. The charging base is gone — the UPS charges through a rear barrel
> jack — and the diffuser follows the crescent + clock aperture directly.

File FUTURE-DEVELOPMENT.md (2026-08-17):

# FUTURE DEVELOPMENT

Everything still to do on the sound machine, one entry each. Prototype 1 is built
and in service, so nothing here blocks *use* — these are improvements, unverified
assumptions, and one hardware fix that is currently costing real capability.

Entries are stably numbered so they can be referenced from code comments and
commit messages (`H1`, `C2`, …). **Do not renumber a completed entry** — strike it
and leave the number dead.

| | | |
|---|---|---|
| **[H — Hardware](#h--hardware)** | H1 bulk capacitance · H2 shunt value · H3 touch electrode · H4 ToF pinhole | needs a soldering iron |
| **[C — Calibration](#c--calibration)** | C1 ToF deviation thresholds · C2 gesture timing · C3 noise gain · C4 dim curve | needs the assembled machine |
| **[V — Validation](#v--validation)** | V1 AEC over noise · V2 sunrise on the final crescent · V3 `(?)` constants · V4 crescent green glitch | needs measuring, not changing |
| **[F — Features](#f--features)** | F1 touchless wake | not built |
| **[T — Tech debt](#t--tech-debt)** | T1 blanket `except ImportError` · T2 stability foot span · ~~T3–T5 flashed-audio looping~~ *(resolved by removal — read before re-adding audio)* · T6 speaker hiss | optional |

---

## H — Hardware

### H1. Install the brownout-fix bulk capacitance ⭐ highest value

**The one hardware task left, and it is currently costing three quarters of the
crescent's brightness.**

The ESP32 resets on transient rail sag. The diagnosis is settled; the fix has not
been fitted. What is standing in for it is `led_max_pct: 25%`
([`packages/settings.yaml`](packages/settings.yaml)), which caps the strip at
~0.73 A so the transient stays under the trigger point.

**What to fit**
- 470–1000 µF low-ESR electrolytic **+** 1–10 µF X7R ceramic at the Flex board's
  power input terminals, **physically close to the terminals**.
- An input-side cap on the LED supply.
- Then verify the wiring/feed topology to the strip — a long thin feed is its own
  problem and capacitance will not rescue it.

**Two things that make this counter-intuitive, and are why 25% looks excessive**
1. **The paper budget was never the constraint.** The cap used to be 65% — ~1.9 A
   for the strip, ~3.7 A of a 5 A rail, comfortable — and it still browned out.
   The failure is the *transient*, not the average.
2. **It cannot self-recover.** The SK6812s latch their last frame independently of
   the MCU, so once the rail sags enough to reset the ESP32, the strip keeps
   drawing the same current straight through the reboot loop.

**Acceptance test.** Raise `led_max_pct` in small steps, watching for a reset
during a **sunrise ramp** (worst case — a rising current step across all 48 px)
and during loud audio. Full white at 100% is ~2.9 A for the strip; simply getting
back to 65% is a **2.6× improvement in output**.

**Related tell.** The IS31FL3731 matrices have no NVM and revert to their
power-on state after a rail glitch, so unexplained display corruption is
independent evidence the rail dipped even if the ESP32 survived.

> **Until this is done, `led_max_pct` is a safety limit, not a brightness
> preference.** It is flagged as such in `CLAUDE.md`, `HARDWARE.md` and inline in
> `settings.yaml`, because a dim light invites exactly the wrong fix.

### H2. Verify the UPS shunt value

`ups_shunt_ohms` (`0.01 Ω`) comes from the module's documentation and has never
been measured. The monitor itself is **confirmed** — INA219 at `0x41`, sign
convention correct — so this is the last unverified term in the power chain.

- **What depends on it:** absolute **current** and **power** readings.
- **What does not:** bus voltage, per-cell voltage, and state-of-charge. This is
  why it has survived unmeasured — nothing user-visible is obviously wrong.
- **Current evidence:** ~0.15 A idle, plausible against the estimated draw. That
  estimate is not a measurement, so this is consistency, not verification.
- **How:** meter in series with the pack, compare against `Battery Current`. If
  the reading is ~10× off, this is why.

### H3. Settle which touch electrode is installed, then re-calibrate

**The as-built state is not recorded and should be.** Two different electrodes
are documented and only one is in the machine:

| | Designed | What was calibrated |
|---|---|---|
| Pads | 2 × 40 × 22 mm shoulder strips, one net | 1 × 76 × 76 mm copper tape |
| Wall | thinned locally to 1.6 mm | full 2.5 mm, unthinned |

`touch_threshold: 2500` was measured against the second. If the machine now has
the designed pads, **that number is calibrated for the wrong electrode** — a
smaller pad at a shorter dielectric distance moves both the baseline and the
finger delta.

**How to re-calibrate:** set `touch_setup_mode: "true"`, watch `difference=` in
the logs untouched versus held, set the threshold between the noise ceiling and
the weakest press. Bias **high** within that gap: the realistic false triggers are
a hovering hand and gripping the dome to move it, neither of which shows up in a
quiet bench sample.

> **Check `value` before `difference`.** If it reads exactly **4194303** the
> counter is saturated and no threshold can work — that is the
> `measurement_duration` bug, documented in `packages/hw/touch.yaml`, not a
> wiring fault.

### H4. Open up the ToF pinhole — it is blinding the sensor

**Diagnosed from a DEBUG log on the assembled machine; the fix is a print
change.** The VL53L0X reports a fixed **0.024 m, forever** — every sample between
0.020 and 0.030 over two minutes, sd ~0.0015. There is nothing 24 mm above the
crown. That reading is **optical crosstalk**: the emitter and the receiver share
one **3.5 mm** bore through the crown (`TOF_HOLE_D` in
[`3d-print/enclosure_geom.py`](3d-print/enclosure_geom.py)) with no barrier
between them, so emitted light reaches the receiver off the bore itself and the
chip ranges its own aperture. ST's guidance for a shared window is a larger
opening **and** a light-tight septum between the two optical paths.

**What to change** — one or both, cheapest first:

1. **Widen the bore** to ≥ 6 mm, chamfered on the inside so the wall leaves the
   25° cone immediately.
2. **Split it into two apertures** with a septum between emitter and receiver —
   the proper fix, and the one that survives a wider cone.
3. **Drop `TOF_STAND` (2.0 mm)** so the board sits against the skin. Every
   millimetre of standoff is another millimetre of tube in front of the cone;
   the file already says so.

**Until then, C1's baseline-deviation detector is what makes the feature work** —
it reads the *change* in the crosstalk return, which a hand does perturb by 10–20
mm against 1.5 mm of noise. That workaround should be **deleted** when this is
fixed, and plain distance thresholds put back; it is 40 lines of cleverness
standing in for a 3 mm drill.

**Acceptance test:** with the space above the knob empty, DEBUG shows
`Distance is out of range` (not a number). That is the sensor seeing the room.

---

## C — Calibration

### C1. ~~Calibrate the ToF proximity thresholds~~ → tune the deviation thresholds

**Superseded by measurement. There are no distance thresholds any more, because
the sensor does not measure distance in this enclosure** — see **H4**. It ranges
its own pinhole at a fixed ~0.024 m, so `tof_near_m` / `tof_far_m` are gone and
`packages/hw/proximity.yaml` now detects *deviation from a learned baseline*.

**Measured, from a 2-minute DEBUG log on the assembled machine:**

| | Reading | Deviation |
|---|---|---|
| idle (129 samples) | 0.020–0.030, mean 0.0245, sd ~0.0015 | ≤ 0.0055 |
| hand arriving | 0.036, 0.046 | +0.012, +0.022 |
| hand held over the knob | 0.011–0.019 | −0.013 to −0.006 |
| hand leaving | 0.028–0.038 | +0.003 to +0.013 |

`tof_deviation_near_m` **0.010** sits nearly 2× above the worst idle excursion
and below the weakest hand signal. Replayed against that log it produces **zero**
false fires across the idle stretch, asserts on the *second* sample of the hand
arriving, and releases 2.5 s after it leaves.

**Confirmed on hardware, and one thing it turned up.** A second log
(`soundmachine-logs-10`) shows the detector firing on every gesture — and
*chattering* through the middle of them: ON at 20:59:31.6, OFF at 36.6, ON again
at 37.0. The cause is that **the swing is not monotonic**. A hand hovering high
reads 0.030–0.049 and genuinely tracks height; a hand on the knob reads
0.010–0.020. So a descending hand's reading rises, then falls back *through* the
0.024 baseline — three or four samples of near-zero deviation in the middle of a
real gesture, which to a `|deviation|` test is an empty room.

`tof_release_samples` is therefore **8 (2 s)**, not 3 (0.75 s). Replaying that log
sample-by-sample: at 0.75 s the four gestures produce five lit spans (one split);
at 2 s they produce four, one per gesture, with ~2 s of tail. Longer merges
gestures that were a second apart.

**What to tune, and which way:** pixel lights on its own → raise
`tof_deviation_near_m`. Slow hand missed → lower it, or lower
`tof_confirm_samples`. Pixel drops out *mid-reach* → raise
`tof_release_samples`, that is the baseline crossing above. Pixel drops while the
hand rests there → the baseline is being dragged; lower `tof_baseline_alpha`.

**Also landed here, and worth keeping whatever happens to the optics:**

- The floor (`tof_min_valid_m`) rejects failed measurements — the component
  publishes the range register without the range-status byte beside it, so a
  failure arrives dressed as a distance. It is **0.005**, deliberately far below
  what a hand produces; it was briefly 0.05 on room-sensor reasoning and rejected
  every single sample.
- Unusable readings are *ignored*, not counted as "far", so one dropped sample
  mid-hover no longer resets the run of consecutive near samples that asserting
  depends on. `tof_invalid_hold_samples` (12 ≈ 3 s) leashes that.
- A **`heartbeat: 60s`** filter on the entity. Without it a live sensor seeing
  nothing and a sensor that died at setup were the identical entity — one number,
  never updating.
- **The entity can now show a hand at all.** It published on a `delta` of 0.02 m
  at 2 decimals — a gate *larger than the whole signal*, and a resolution at which
  the idle baseline and a hand on the knob both render as `0.02`. Ten minutes of
  log produced a handful of `0.02`s and looked broken. Now `delta` **0.002** and
  **3** decimals. Display-only either way — the debounce always ran off the raw
  value and was detecting hands the whole time — but a dead-looking entity is the
  first thing anyone checks, so it cost more than it saved.

> `tof_log_level` is on **DEBUG** while this is being watched. Put it back to
> `WARN` once you trust it; it is four log lines a second.

### C2. Widen the gesture timing dead band

`gesture_tap_max` is **0.8 s** and `gesture_hold_min` is **1 s**, so a press
between them matches neither `on_multi_click` timing and **fires nothing**.

A measured quick tap landed at exactly 0.80 s — right on the edge. If taps feel
unreliable, this is the mechanism, not the touch threshold. Deliberately not
changed yet: taps may get shorter once there is feedback to tap against.

Applies to **both** the touch pad and the knob switch — they share these settings
on purpose so the two controls feel identical.

### C3. Tune the brown-noise high-pass makeup gain

Currently set by ear (160 Hz, 12 dB/oct, ×4.00 makeup). Worth a second pass now
that the speakers are in sealed boxes on a braced facade rather than loose on a
bench — the acoustic load has changed.

### C4. Tune the display auto-dim curve

The BH1750 → brightness mapping is a log curve deliberately biased dark, with the
3 a.m. near-black target being the case that matters. Verify in an actually dark
bedroom rather than a dim room.

---

## V — Validation

### V1. Validate AEC / wake word over playing noise, in the enclosure

Wake-word-over-noise is the central audio constraint of the whole design and has
**never been tested in the assembled machine** — which is the only place the
acoustic path is real. The speakers now sit in sealed boxes bolted to a braced
facade with the mic array directly above them; none of that was true on the
bench.

**Re-test whenever anything in the audio chain changes.** In particular the
TPA2016's AGC is off (compression 1:1) *deliberately* — the XVF3800's echo
canceller can only cancel a linear path, and an active compressor downstream of
the DAC makes it time-varying. Do not enable compression without re-running this.

### V2. Re-check the Circadian Sunrise against the final crescent

The effect fills whole rows bottom-up and was written for a fuller apex. The
final layout is 6 rows of `{10, 10, 9, 8, 7, 4}` at 10.4 mm pitch, so vertical
gradients have less travel than the effect assumes and the apex is sparse.

Watch a full sunrise at speed and check the top rows do not band or arrive early.

### V3. Measure the remaining `(?)` constants

`3d-print/MEASURE-ME.md` lists every constant still marked `(?)` in
`enclosure_geom.py`, and `check_docs.py` enforces that list in both directions.

**Prototype 1 was printed with all of them still guesses and it went together** —
which is not the same as the guesses being right. It means nothing that failed
depended on them, and the tolerance they consumed is unknown. They are now easier
to measure on the assembled machine than on the loose parts the list was written
for, and they matter for a reprint or a v2.

### V4. Confirm whether the RMT change fixed the crescent's green glitch

**A fix is applied and unverified.** Under Rainbow Arch, the top of the crescent
occasionally flashes green for well under a second. The diagnosis is settled; which
of two causes it is, is not.

**Why it is a transmission fault, not a rendering one.** Three facts, and they only
fit one way:
1. The effect *cannot* paint green there. Hue is `270° × (1 − radius)` and the top
   rows sit at `radius ≈ 1`, so they are hue 0 — **pure red**. Green needs
   `radius ≈ 0.55`, the mid-band.
2. Red is `00 7F 00 00` on a GRB + W strip. Slip the byte stream by **one byte**
   and `0x7F` lands in the green slot. The right bytes are arriving in the wrong
   slots.
3. Rows are in *data order, bottom row first*, so the top row is pixels 44–47 —
   the **tail of the chain**, which is where corruption in a WS28xx chain lands.

**What was changed** (`packages/hw/crescent.yaml`) — `use_dma: true`,
`use_psram: false`, `rmt_symbols: 1024`. The default non-DMA RMT ping-pongs on half
of 192 symbols, giving the encoder ISR ~115 µs of runway per refill with the buffer
in PSRAM; SK6812 latches on any gap over ~80 µs, so one late refill makes every
pixel downstream re-latch mid-stream, byte-shifted. That ISR competes with WiFi, the
I2S path and a busy 100 kHz I2C bus. 1024 symbols is sized so a *surviving* glitch
rules the RMT out rather than leaving it half-tested.

**Acceptance test.** Run Rainbow Arch for a long stretch, and specifically *with
noise playing and during voice-assistant activity* — ISR starvation correlates with
audio, so an idle-only test proves little.

**If it survives, stop tuning RMT numbers — it is the other cause.** GPIO1 drives
the strip at **3.3 V** into a part that wants VIH = 0.7 × VDD = **3.5 V**, with no
level shifter anywhere in `HARDWARE.md`, and the data line runs the crown beside the
I2S clocks and the STEMMA chain. Each pixel regenerates imperfectly, so edge jitter
accumulates over 48 hops and the tail misreads first — which matches the symptom
just as well. Fixes, cheapest first: 330–470 Ω series resistor at GPIO1 plus 0.1 µF
at the first pixel; one series diode on the strip's 5 V to bring VDD to ~4.4 V so
3.3 V clears the threshold; or a 74AHCT125 as the proper answer.

**Related:** [H1](#h1-install-the-brownout-fix-bulk-capacitance--highest-value) is a
plausible contributor either way — VIH is referenced to VDD, so rail sag moves the
threshold under a fixed 3.3 V drive.

---

## F — Features

### F1. Touchless wake gesture

Designed but never implemented. The VL53L0X was originally specified for a
touchless wake — wave a hand to bring the machine up — and today nothing but the
knob NeoPixel reads the sensor (see C1).

The hardware is present and live, so this is purely firmware: a distance
threshold, a debounce, and a decision about what "wake" should do that does not
collide with the existing tap/hold gestures.

### F2. A second default view — a night face, or something time-driven

`api/display.yaml` now resolves the display in two tiers: transient **overlays**
over a **default view**, the thing shown when nothing has just happened. Today
the defaults table has exactly one row — the low-battery alert — with the clock
underneath it by omission.

The table exists so that "what does the display rest on right now?" can depend on
more than one condition. The obvious candidate is time of day: a stripped-down or
dimmer face after bedtime, seconds or a date at other times. Adding one is a
global, a setter beside `display_set_alert`, and a row in the defaults table —
where it sits in that table is the whole priority decision.

Worth doing only when there is a second view actually wanted; the abstraction is
already paid for.

---

## T — Tech debt

### T1. Remove the blanket `except ImportError` from the remaining generators

Five generators in `3d-print/` still wrap large blocks in a bare
`except ImportError`. This pattern once silently skipped the dome's **entire**
mesh validation — watertightness, body count, board envelopes — for an unknown
number of runs, because the message named the wrong missing package.

They all pass today because the dependencies are present, which is exactly what
makes it easy to leave. See the retrospective, §1.

### T2. Optional — widen the foot span for stability

~55 gf topples the machine from the top. That is not the battery's fault (mass low
down helps); it is 156 mm of height on a 39 mm foot span. `FOOT_IN` is 16 mm
today; **8 mm gives ~1.5× the shove resistance** and still leaves the foot 2 mm
inside the wall line.

A v2 geometry change, not a repair — the machine is stable in normal use, with
14.6 mm of static tipping margin and 10.6° of backward tilt tolerance.

### T3–T5. ~~The flashed-audio looping failures~~ — resolved by removal

**All three are closed, and none of them was fixed.** They were properties of
looping a flashed file through `speaker.media_player`, and no flashed file goes
through it any more: every one is an AMBIENCE, decoded by `components/ambience_player`
straight into a mixer source that starts once and never stops. Looping is a read
pointer returning to zero.

| | was | outcome |
|---|---|---|
| **T3** | fallback if the mixer drain-wait stopped holding track looping together | the drain-wait is deleted; nothing depends on it |
| **T4** | ~300 ms dropout at a track's loop point, from the pipeline restart | no pipeline restart exists to cause it |
| **T5** | `repeat_one` bypassed the drain-wait, so looping died after a pass or two | nothing calls `repeat_one` |

**The knowledge is kept, because the trap is easy to walk back into.** The
mechanism — why a mixer source handed `playback_delay_frames_` it cannot drain
leaves the pipeline reporting PLAYING forever, and why `repeat_one` could never
be made safe from config — is written up where someone would hit it: the "WHAT
USED TO BE HERE" block in `packages/api/sound.yaml`, and the two-mechanisms note
at the top of `packages/hw/audio_chain.yaml`. Upstream has not changed
([esphome/esphome#14641](https://github.com/esphome/esphome/issues/14641) is
closed as not planned), so **anything put back on the media player and looped
will fail exactly the same way.**

**Two things that are still true and still matter:**

1. **The media player's idle/state reporting is still unreliable** under the
   mixer. Nothing loops through it now, so it has nothing left to break — but
   voice-turn un-ducking still keys off announcement state rather than `on_idle`
   because of it (`behavior/voice.yaml`).
2. **The track → track switch defect was never fixed, only starved of cases.**
   Handing the player a new file while the old one is still filling the pipeline
   makes the drain-wait time out and play into a live pipeline — measured once as
   a 59 s file consumed in 29.65 s at the wrong pitch, because the resampler was
   still configured for the previous file. There are no flashed tracks left to
   trigger it, but a URL sound plus anything else through the player could.

### T6. Constant speaker hiss — the AIC3104's converter noise floor

A steady quiet hiss from both speakers whenever the machine is powered, with
nothing playing. **Diagnosed, not fixed.**

**It is the codec's own converter noise, not the amp.** Measured on hardware:
the hiss is *identical* at volume 1 and volume 100, and vanishes completely at
volume 0. That pair of facts identifies the source exactly, because registers
0x2B/0x2C do two different jobs:

- **bits 6:0** — digital volume, applied to the PCM data going *into* the
  converter. Scales the signal only.
- **bit 7** — a dedicated mute that gates the converter's *output*.

Noise generated by the converter itself is therefore untouched by volume and
killed outright by mute. Constant 1→100, silent at 0, is that signature and
nothing else's. The media player mutes automatically at exactly zero —
`if (volume < 0.001f) set_mute_state_(true)` in `set_volume_` — which is why 0
behaves differently from 1 rather than just being quieter.

> **Do not chase this with `amp_gain_db`.** It is the intuitive fix and it does
> nothing. The TPA2016 sits downstream of the codec, so no codec register could
> silence *its* self-noise — the fact that mute works proves the amp is not the
> source. A fixed gain downstream of the noise attenuates hiss and signal
> equally: you get a quieter machine with exactly the same hiss-to-signal ratio.

**Why nothing in this repo controls it.** `AIC3104::setup()` in the forked
component is literally `// do nothing`. The component implements volume and mute
and nothing else — the codec's whole analog output path (routing, output level,
driver config) is set by the XVF3800/board firmware at boot, outside this repo.

**What it actually costs: the 3am case.** The hiss is fixed while the music
scales with the knob, so SNR is *worst* at low volume — exactly how a bedside
machine gets used. `volume_floor_pct: 30%` puts knob-1 at about −44.8 dB of
signal, with the hiss not down at all. During noise playback it is masked; in
the quiet gaps of a flashed track, and all day while idle, it is not.

> **The floor moved, and it moved *towards* this.** It was 55% (knob-1 at
> −28.5 dB) until the quiet end was widened for a whisper-level Crickets. That
> is 16 dB more signal attenuation against an unchanged noise floor, so this
> entry's cost is 16 dB worse than when it was written — the extra range is only
> as usable as the hiss allows. That is the argument for fix 2 below, not an
> argument for putting the floor back.

**Fixes worth pricing, in increasing order of cost:**

1. *Idle mute:* mute the codec whenever nothing is playing, via
   `aic3104_dac->set_mute_on()/off()` behind an api verb. Cheap, and the volume-0
   observation is already proof it works on this hardware. Kills the hiss in the
   idle hours; does nothing for quiet playback. One real risk: an HA-initiated
   announcement arriving while muted needs the unmute to land before audio
   starts, or it clips the head — so unmute from the media player's
   `on_announcement`, not just from the sound verbs.
2. *Move volume from digital to analog:* hold the DAC digital volume at 0 dB so
   the converter always runs full-scale, and set loudness with the codec's analog
   output level registers (82/86 and neighbours) instead. This is the actual fix
   for low-volume SNR. Needs the aic3104 component patched or vendored, **and**
   certainty about which codec outputs the Flex wires to the TPA2016 — get the
   routing wrong and there is no audio at all.

> **Neither is an AEC hazard**, despite touching gain downstream of the DAC. The
> codec's volume/mute already sits *after* the point where the XVF3800 taps its
> echo reference, so the reference cannot see it either way — this is not the
> same category as the amp's AGC, which is continuous and signal-dependent. The
> volume knob is already a downstream gain step and has always been one.

**Acceptance test:** with nothing playing, the speakers are silent at every
volume setting, not just at 0 — and a volume change does not bring the hiss back.

---

## Done

Kept briefly so a settled question is not re-opened. Detail in
[`RETROSPECTIVE.md`](RETROSPECTIVE.md) and `SOUNDMACHINE.md` §3.

- ~~**Confirm the UPS monitor address and part.**~~ INA219 at `0x41`, confirmed on
  the boot scan and reading consistently; sign convention confirmed (discharge
  negative). Shunt value still open — see H2.
- ~~**Calibrate the capacitive touch threshold.**~~ `touch_threshold: 2500`, from
  64 untouched samples and 5 presses. Re-opens as H3 if the electrode changes.
- ~~**Fix the touch pad never registering.**~~ ESPHome derives
  `charge_times = 65535` from its default `measurement_duration`, saturating the
  S3's 22-bit counter so the delta is permanently 0. `measurement_duration` is now
  set explicitly in `packages/hw/touch.yaml`.
- ~~**Finalise the bottom plate geometry.**~~ Was blocked on the battery-retention
  decision; resolved by the Waveshare 3S UPS, and printed.

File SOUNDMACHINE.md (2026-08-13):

# SOUNDMACHINE.md

The project story in one file. If you are an agent (or a person) loading this
repo cold, read this first: it explains **what we built, why the pieces are
arranged the way they are, what has already been solved, and what is still
open.** Then use the companions for detail:

- **[`HARDWARE.md`](HARDWARE.md)** — the parts, addresses, pins, power budget.
- **[`CLAUDE.md`](CLAUDE.md)** — how the firmware/repo is structured and the
  rules for editing it safely.
- **[`README.md`](README.md)** — how to build and deploy it.
- **[`FUTURE-DEVELOPMENT.md`](FUTURE-DEVELOPMENT.md)** — everything still to do,
  one numbered entry each.
- **[`RETROSPECTIVE.md`](RETROSPECTIVE.md)** — what building v1 taught.

> ## Where the project is
>
> **Prototype 1 is built.** Designed, printed, wired, assembled, and running on
> the bedside table. The enclosure is done and the electronics are in their final
> arrangement — **the work from here is firmware.**
>
> That changes what "open" means below. The remaining items are tuning, polish,
> unverified assumptions and **one hardware fix** — not construction. They are
> tracked in [`FUTURE-DEVELOPMENT.md`](FUTURE-DEVELOPMENT.md).
>
> The v1 development history is distilled in
> [`RETROSPECTIVE.md`](RETROSPECTIVE.md); the raw journals live on the **v1
> release branch**. The enclosure *design system* (`3d-print/`) stays live on
> `main`, because it is still the source of truth for the LED crescent and the
> starting point for any v2.

---

## 1. What we are building

A DIY, polished, bedside **smart sound machine** — nicknamed the **"Faux
Hatch"** because it takes design cues from the Hatch Restore form factor while
being fully custom and locally controlled. It is one integrated device that
combines:

- **Ambient noise** — continuous white / pink / brown noise, generated on-device,
  plus flashed loop ambiences (crickets) for when a colour of noise isn't the mood.
- **A far-field voice assistant** — "Okay Nabu" wake word into Home Assistant,
  robust enough to be heard *over* playing noise.
- **A sunrise light** — an SK6812 crescent that simulates dawn to wake you, plus
  static nightlight / reading presets.
- **A clock** — a tiled LED matrix that auto-dims to near-black at 3 a.m.
- **Environmental sensing** — ambient light (live), with a time-of-flight
  touchless wake planned.
- **A physical control surface** — a rotary encoder (volume + sound) and a
  capacitive touch pad (light presets).

The whole thing runs on **ESPHome**, integrates with a **local Home Assistant**
instance (Nabu Casa subscription for voice), and is designed so the config is
**hosted on GitHub and pulled by HA as a remote package** — every build compiles
the latest `main`.

**Design values driving the project:** offline-capable (noise, clock, one
flashed track, and a web UI all work with no network), quiet and eye-friendly at
night, acoustically clean enough not to fight the echo canceller, and physically
polished (Fusion 360 enclosure, Glowforge-cut acrylic diffuser).

---

## 2. How the pieces fit together

### The audio chain (the hard part)

```
                                   ┌─────────── noise_generator (custom C++) ── white/pink/brown
ESP32-S3 ──I2S──► XVF3800 mics     │
   │              (beamform+AEC)   ├──► mixer ──► AIC3104 DAC ──► TPA2016 amp ──► 2× 4Ω speakers
   │                               │      ▲
   ├──► micro_wake_word "Okay Nabu"│      ├── media pipeline (flashed MP3 / HA URL)
   └──► voice_assistant ───────────┘      └── announcement pipeline (TTS replies)
```

Everything is 48 kHz end to end. Three audio sources (noise, media, TTS
announcements) are summed by an ESPHome **mixer**; the mixer output goes to the
DAC, then the amp. The **XVF3800 provides the mic beamforming and the acoustic
echo cancellation (AEC)** that lets the wake word be heard while the machine is
playing sound — and that single fact constrains everything downstream (see §4).

When the wake word fires, both background channels (noise + media) **duck** for
the turn; the spoken reply rides the announcement channel at full volume; a
watchdog un-ducks when the reply finishes. See `packages/behavior/voice.yaml`.

### The light

`packages/hw/crescent.yaml` owns the SK6812 crescent: an Off/On entity plus a
preset dispatcher (a `select`) with **Sunrise** (a timed, animated dawn),
**Nightlight**, **Morning Light**, **Colour Cycle** and **Rainbow Arch**. The
**Circadian Sunrise** is a keyframe-interpolated effect that fills the crescent
from the bottom row upward, evolving deep-red → amber → blue-enriched cool white
over an adjustable duration, then holding and auto-off. An **Alarm** datetime
fires the sunrise at a set time.

Two of the presets are colour rather than function. **Colour Cycle** drifts the
whole crescent round the hue wheel over three minutes; **Rainbow Arch** paints
concentric hue bands — red on the outside, violet at the centre of the flat edge
— by each pixel's *normalised elliptical radius*, which is what makes it read as
an arch rather than as horizontal stripes. Both bake their own brightness in,
because an addressable light stops applying its brightness to pixels a running
effect owns.

The crescent is **48 px** in six cut segments laid out `{10, 10, 9, 8, 7, 4}`
bottom-to-top on a half-ellipse. That layout is **not a firmware choice** —
`3d-print/enclosure_geom.py` computes it from the physical cavity and
`crescent.yaml` carries a copy. Change one without the other and the firmware
addresses pixels that are not there; `3d-print/check_docs.py` is what stops that.

### The display

The display is **policy plus a driver**: `packages/api/display.yaml` owns the
whole policy layer (the transient overlays and their priority, expiring them,
which default view sits underneath, formatting the clock, the tick) and resolves
all of it into an `clock_display::Frame`. `components/clock_display` renders that frame
and decides nothing. The split is not there so the display can be swapped — it is
there because choosing what to show and drawing it are unrelated problems, and
merging them would bury the policy in the middle of 300 lines of fonts and
register bursts. The frame being a struct is what turns the contract between the
two halves into something the compiler checks rather than something two file
headers have to keep agreeing on.

**The api layer is the single writer**, and it resolves one thing out of two
tiers. First the **overlays**, all transient and all timed, in priority order: a
message typed from Home Assistant → a **device status message** → a transient
code (e.g. "S3", "L1"). If none is live, it falls through to the **default
view** — what the display rests on when nothing has just happened. Normally that
is the clock; while the pack is low it is the sticky **alert** instead.

That tiering is deliberate. An alert used to sit *above* the codes, which meant a
flat battery pinned "LOW" to the display and swallowed every volume readout and
preset code — the machine looked broken rather than low. A sticky condition is
not an event competing for the same instant; it is a statement about what the
display should say when it has nothing better to do, so it displaces the clock
and only the clock. The same slot is where a time-of-day face or any other
resting view would go.

The BH1750 ambient-light sensor auto-dims all of it on a log curve tuned
deliberately dark.

Status messages are the channel for things the *device* wants to say rather than a
code echoing a knob turn — today, "CHG" / "BATT" when the power source changes.
They are drawn in the compact 3x5 font inside the **right-hand panel only**, which
keeps them clear of the physical gap between the two panels; a word centred across
both would lose a column of whichever glyph landed on the seam, and on a 3x5 glyph
that can be fatal (a 'T' reduced to its top bar). The cost is a four-character
budget — anything longer falls back to scrolling the full width, which takes far
longer than anyone wants to watch for a status glance.

### Power & monitoring

`packages/hw/power.yaml` reads the Waveshare 3S UPS via an INA219 and derives
voltage, current, per-cell voltage, an estimated state-of-charge, a "charging"
flag, and a latching "low battery" flag (with hysteresis so it can't chatter).
The display and other logic key off those flags.

"Charging" and "on mains" are **not** the same thing here: a full pack on the
charger tapers to near-zero current, so the mains detector (`external_power`) is
defined as *not discharging* rather than as charging.

Getting *"not discharging"* right took a second pass. The first version compared
the instantaneous current against a deliberately large 200 mA deadband, sized to
ignore the brief excursions a full pack makes on the charger. But this device's
whole idle draw from an 11–12 V pack is only ~100–180 mA — under that deadband —
so unplugging it changed nothing and `external_power` reported **"Plugged In"
while running on battery**. Shrinking the deadband alone just brings the flapping
back. What actually separates the two cases is **duration**: a charger excursion
lasts a sample or two, a real mains loss lasts forever. So the detector now
thresholds a **60 s moving average** of the current (`battery_current_avg`)
against a small 50 mA deadband — a one-sample blip averages down to nothing,
while a sustained draw crosses within two or three samples.

That flag drives the "CHG" / "BATT" announcement, and the averaging window sits
in front of `ups_confirm_time` (30s), so the message can land up to ~90s after
the plug actually moves — the price of never crying "mains lost" at a healthy
full battery.

### The control surface

A **seesaw rotary encoder**: twist = volume (variable step — coarse when quiet,
fine when loud), tap = next sound, hold = sound off. A **capacitive touch pad**:
tap = next light preset, hold = light off. Both drive the same `select` entities
the UI uses, so physical, HA, and web controls stay in sync.

"Next sound" walks **one** list — the noise colours and the flashed tracks are
options in the same `select`, so a tap goes White → Pink → Brown → La La →
Crickets. They were briefly two selects that kept each other switched off by
publishing `Off` into one another; merging them makes the mutual exclusion a
property of the data structure instead of a protocol both sides have to observe.

### The two front ends

1. **Home Assistant** — full control + voice, when the network is up.
2. **Embedded web server** (`web_server:` in `soundmachine.yaml`) — served from
   flash at `http://soundmachine.local/`, works with no internet.

### How the repo is organized

`soundmachine.yaml` is the entry point and holds **only** the device core — the
I2C bus, connectivity, the external components, and the `packages:` manifest.
Everything else is split three ways, and the split is the point: `packages/hw/`
is one file per physical part, `packages/api/` is the abstraction layer that is
the only writer of that hardware, and `packages/behavior/` is the operational
logic that decides what should happen. Every tunable in the build lives in
`packages/settings.yaml`. After ESPHome merges the packages **all ids are
global**, so the wiring is by id — but each layer only reaches *down* through an
api verb (`display_show_code`, `noise_play`, `crescent_static`), never straight
into a device. Custom C++ lives in `components/`.

[`packages/README.md`](packages/README.md) is the architecture map — the layer
rules, the hardware→behavior event contracts, and where to add a new thing. See
`CLAUDE.md` for the editing rules and the invariants.

---

## 3. Roadblocks we have already overcome

These were real problems, diagnosed and solved. Don't re-litigate them without a
reason — and if you change the relevant area, re-test the thing that broke.

**Gapless noise.** A file-loop approach caused audible restarts at the loop
seam. Solved by writing a custom `noise_generator` C++ component that continuously
injects PCM — white, pink (Paul Kellet filter), and brown (leaky integrator with
`std::tanh()` soft saturation). Color switches mid-stream with no restart.

**Starting noise crashed the ESP at boot.** Starting the generator during setup
dereferenced an uninitialized event group. Fixed by deferring the resume to
`on_boot` **priority -100 + a 2 s delay** (a `booted` global gates the Sound
select from touching the audio engine before then).

**Wake word over playing noise (the central audio constraint).** The XVF3800's
AEC can only cancel a **linear** echo path. So the **TPA2016 amp's AGC is turned
OFF** (compression 1:1) rather than tuned — an active compressor downstream of
the DAC makes the echo path time-varying and un-cancellable. All volume lives in
software (AIC3104). The amp is written once at boot by the custom `speaker_amp`
component, with register **write order enforced** (compression before gain, or
the gain gets clamped to a silent amp).

**HA's "Wake word" selects showed up `unavailable`.** Detection worked fine, but
Home Assistant's two wake-word select entities were permanently unavailable. Cause:
`voice_assistant:` never linked the mww instance. `VoiceAssistant::get_configuration()`
answers HA's config request from its `micro_wake_word_` pointer — null means it
advertises zero available wake words and `max_active_wake_words = 0`, and HA's
selects (which it creates **two** of, always, regardless of model count) are
available only when they hold more than the "no wake word" option. Local detection
never needed the link, since `on_wake_word_detected` → `voice_assistant.start:`
never leaves the device. Fix: **`micro_wake_word: mww` under `voice_assistant:`**.
Consequence to remember: HA now **owns** which models are enabled — on connect it
disables every model and re-enables only what the selects name, and that bit is
**persisted in flash**. After a fresh flash, set the select to "Okay Nabu", or the
wake word stays off across reboots.

**Transient brownouts crashed the ESP invisibly — WORKED AROUND, NOT FIXED.**
They don't show on a multimeter but are enough to reset the ESP32. The diagnosis
holds: the proper fix is bulk capacitance at the load — **470–1000 µF low-ESR
electrolytic + 1–10 µF X7R ceramic** at the Flex board's power input terminals,
close to the terminals, plus an input-side cap on the LED supply.

**That capacitance has not been installed.** What is actually in service is a
firmware workaround: the crescent's current ceiling (`led_max_pct`) is held at
**25%**, which keeps the transient small enough not to trigger it. This is why
the light is dimmer than the hardware can drive. Two things make it more than a
cosmetic compromise:

- **The paper budget was never the constraint.** At 65% the strip draws ~1.9 A
  and the whole machine ~3.7 A of a 5 A rail — comfortable — and it browned out
  anyway. The failure is transient, not average.
- **It cannot self-recover.** The SK6812s latch their last frame independently of
  the MCU, so once the rail sags enough to reset the ESP32 the strip keeps
  drawing the same current through the entire reboot loop.

See §4 for the TODO. Until it is done, `led_max_pct` is load-bearing — treat it
as a safety limit, not a preference.

**I2C bus was starving the XVF3800.** The STEMMA sensor chain added enough cable
capacitance / pull-up load to break the timing-sensitive XVF3800. Fix: run the
shared bus at **100 kHz with a 1 ms timeout** (room to clock-stretch during its
firmware boot). Drop toward 10 kHz if it's still flaky fully assembled.

**Broken idle reporting on the media pipeline.** The mixer suppresses the media
pipeline's PLAYING → STOPPED transition, so looping/un-ducking can't rely on the
player's idle state. Un-ducking is solved by a **`duck_watchdog`** keyed off
`is_announcing` (not idle).

Looping was *thought* to be solved by **`media_player.repeat_one`**, on the
belief that it keys off the decoder's own EOF. **It does not** — it is
implemented in `SpeakerMediaPlayer::loop()` and restarts the file on exactly the
transition the mixer suppresses, so it was built on the thing that had already
been ruled out. Symptom: a track plays once, the media player entity sits at
"playing" forever, and every later track is silent until reboot — while noise,
on its own mixer source, is unaffected.

The cause is frame accounting. A mixer source only leaves `STATE_RUNNING` once
`pending_playback_frames_` hits zero; that counter is drained by the i2s output
callback, which fires only for buffers holding real audio, and a source that
starts contributing while the pipeline already holds frames is handicapped by
that backlog first. When a track ends with nothing else making sound, the
callbacks stop before the handicap is paid, the counter freezes, and the source
is stuck in `STATE_STOPPING`. Noise escapes it by first contributing at boot,
when the pipeline is empty.

The first fix was to make **every track wait for
`mixing_speaker->get_frames_in_pipeline()` to reach zero before starting**, which
buys it the same zero handicap noise gets. It half-worked, and could not do
better: `repeat_one` calls `start_file()` straight from
`SpeakerMediaPlayer::loop()`, so the wait protected the *first* start and no
later one. On hardware that meant a gap at every loop and a dead channel after a
pass or two.

**The actual fix was to stop using the media player for this at all.** Every
flashed sound is now a **ambience**: `components/ambience_player` decodes it straight into
its own mixer source, which starts once and never stops, and looping is a read
pointer returning to zero — no end-of-file, no pipeline, nothing to restart. That
deleted the drain-wait, the per-file verbs, the repeat flag and the arbitration
global along with the bug. The media player keeps what it is good at: the TTS
reply and whatever Home Assistant streams, neither of which loops.

This is upstream behaviour, not a local bug — [esphome/esphome#14641](https://github.com/esphome/esphome/issues/14641)
is closed as not planned — so **anything put back on the media player and looped
will fail the same way**. FUTURE-DEVELOPMENT T3–T5 records the whole thing.

**ESPHome 2026.7.x churn.** `select` lost `.state` (use `current_option()` wrapped
in `std::string()`); persisted selections are tracked in `restore_value` globals
instead. `on_tts_stream_end` is unavailable in `media_player:` mode. The seesaw
component was vendored locally with a patched `dump_summary()` (upstream PR #100
on the ssieb repo).

**SD card ruled out.** ESPHome's speaker/mixer pipeline has no SD media source,
so on-device audio is either flashed into the ESP or streamed from HA; runtime
track swapping goes through the HA media library.

**Remote-package hosting.** Because HA pulls this repo as a remote ESPHome
package, `!secret` is forbidden in the config (credentials are substitutions the
local device YAML overrides), custom components must load via a **git**
`external_components` source, and flashed media must default to a **URL** rather
than a bare repo path. See `CLAUDE.md` → "Remote-hosting constraints."

---
## 4. What is still open

**Every open item lives in [`FUTURE-DEVELOPMENT.md`](FUTURE-DEVELOPMENT.md)**,
one numbered entry each, so it can be referenced from code and commits. Summary:

| | |
|---|---|
| **H1** | Install the brownout-fix bulk capacitance — **the highest-value item.** It is currently costing three quarters of the crescent's brightness, because `led_max_pct: 25%` is standing in for it. |
| **H2 / H3** | Verify the UPS shunt value; settle which touch electrode is actually installed and re-calibrate if needed. |
| **C1–C4** | Calibrate the ToF thresholds and the gesture dead band; tune the brown-noise makeup gain and the auto-dim curve. |
| **V1–V3** | Validate wake-word-over-noise in the enclosure; re-check the sunrise against the final crescent; measure the remaining `(?)` geometry constants. |
| **F1** | Touchless wake — designed, never built. |
| **T1 / T2** | Tech debt: blanket `except ImportError` in the generators; the optional foot-span stability lever. |

### Settled since assembly

**UPS monitoring is live and reading correctly.** The boot I2C scan finds the
monitor at **`0x41`** and the INA219 platform talks to it — pack 12.46 V,
4.153 V/cell across 3S, 98 % SOC, all mutually consistent. The **sign convention
is confirmed**: discharging reads negative, and `External Power` / `Battery
Charging` agree with the actual plug state. The shunt value is still assumed —
that is H2.

**The capacitive touch pad works and is calibrated.** `touch_threshold` is
**2500**, from 64 untouched samples and 5 presses on the assembled machine:
untouched noise sd 34 with a worst excursion of +50, presses 6363–12731. Getting
there also turned up an ESPHome bug worth knowing — `measurement_duration` must
be set explicitly or the S3's touch counter saturates and no threshold can ever
fire. Both are documented in `packages/settings.yaml` §7 and
`packages/hw/touch.yaml`.

**The enclosure is built.** The bottom-plate geometry that was historically
blocked on the battery-retention decision was resolved by the Waveshare 3S UPS,
printed, and assembled.

---
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

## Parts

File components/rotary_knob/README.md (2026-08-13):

# `rotary_knob` — the I2C rotary encoder board

Drives an Adafruit I2C QT Rotary Encoder (product #4991): a quadrature encoder, a
push switch, and a single NeoPixel, all reached over I2C through one hub.

## Provenance and the name

This is a **vendored, renamed copy of [ssieb](https://github.com/ssieb/esphome_components)'s
`seesaw` component.** "Seesaw" is Adafruit's name for the firmware their I2C
bridge chips run — accurate, but it tells a reader nothing about what this device
uses it for, so the component is named for its job here instead. The chip's own
vocabulary (the `SEESAW_*` register constants, `ChipModule`) is kept *inside* the
component, where it is the right vocabulary.

Local changes on top of upstream:

- `dump_summary()` patched for ESPHome 2026.7.x.
- `digital_write()` fixed to pass a bitmask rather than a pin number — upstream
  computed the mask and then discarded it, so writing pin 24 set pins 3 and 4.
- Renamed throughout (`Seesaw` → `KnobHub`, and so on).

To diff against upstream, fetch `ssieb/esphome_components` and compare
`seesaw/` with this directory; the commented-out git source in
`soundmachine.yaml` records where it came from.

## What this build actually uses

Only the **encoder** sensor and the **push switch** binary_sensor are configured
(see `packages/hw/knob.yaml`). The NeoPixel is driven by `packages/api/indicator.yaml`
calling `color_neopixel()` directly rather than through the `light:` platform
below — that file's header explains why, and it is a deliberate choice about I2C
traffic, not an oversight.

The analog-input, temperature and touch sensors and the light platform are carried
from upstream but unused here.

## Usage

```yaml
rotary_knob:
  id: knob_hub
  address: 0x36

sensor:
  - platform: rotary_knob
    id: encoder
    type: encoder
    name: "Volume knob"
    number: 0            # optional, defaults to 0
  - platform: rotary_knob
    type: temperature
  - platform: rotary_knob
    type: touch
    channel: 5
  - platform: rotary_knob
    type: adc
    pin: 2

binary_sensor:
  - platform: rotary_knob
    id: button
    name: "Knob press"
    pin: 24

light:
  - platform: rotary_knob
    id: pixel
    name: "Knob LED"
    pin: 6
```

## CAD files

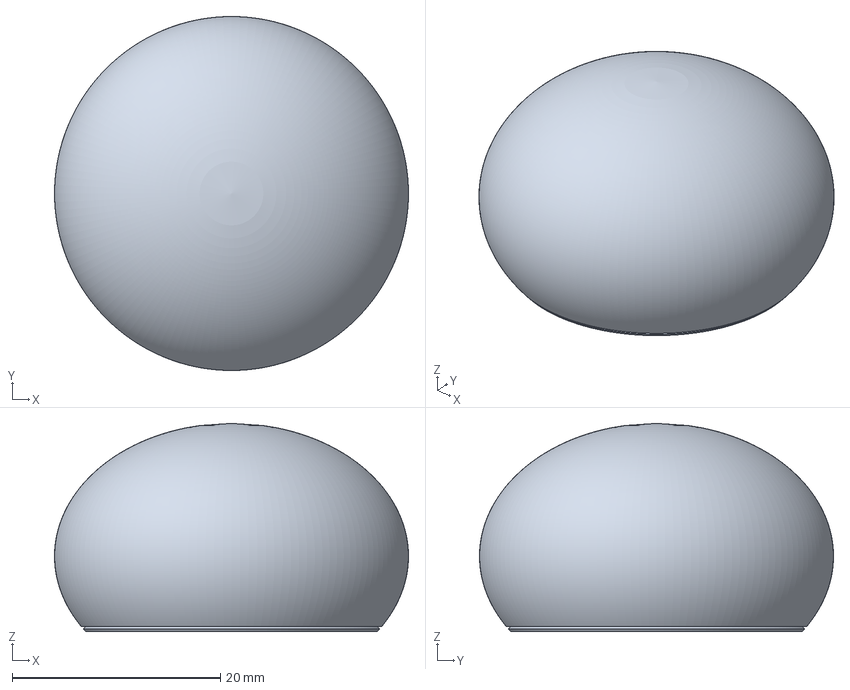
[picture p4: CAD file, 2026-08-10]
3d-print/Knob.3mf
34.0 x 34.0 x 20.0 mm

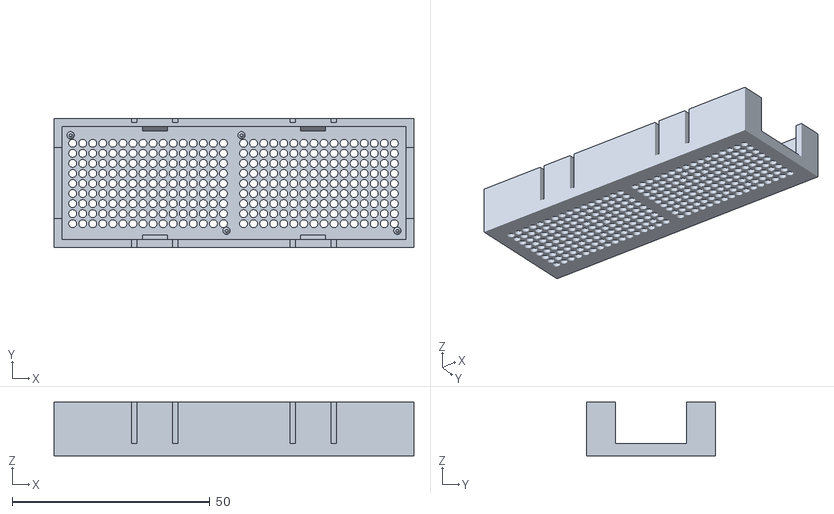
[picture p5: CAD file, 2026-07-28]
3d-print/models/matrix-tray.stl
91.0 x 32.5 x 13.6

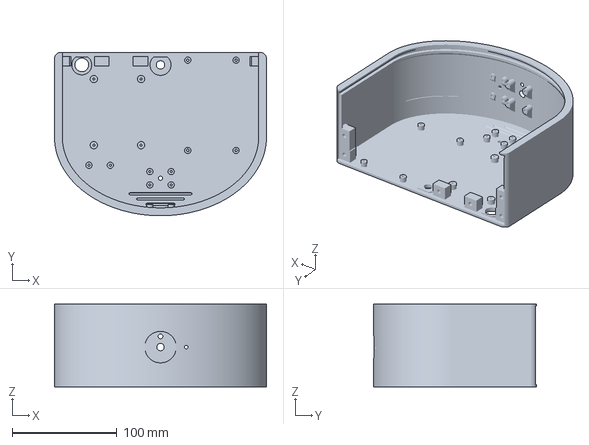
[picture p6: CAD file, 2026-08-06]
3d-print/Dome.3mf
202.0 x 155.7 x 79.0 mm

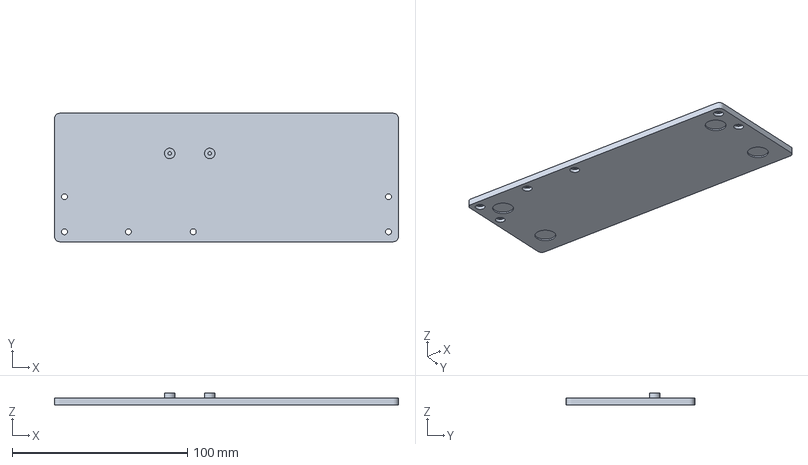
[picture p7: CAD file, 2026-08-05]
3d-print/Bottom Plate.3mf
196.4 x 73.4 x 6.60 mm

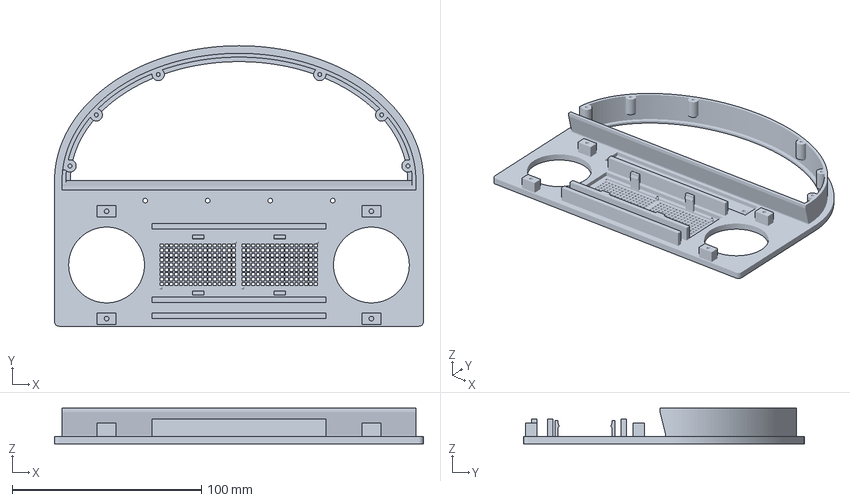
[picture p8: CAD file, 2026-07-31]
3d-print/Front Module.3mf
194.8 x 148.1 x 18.8 mm

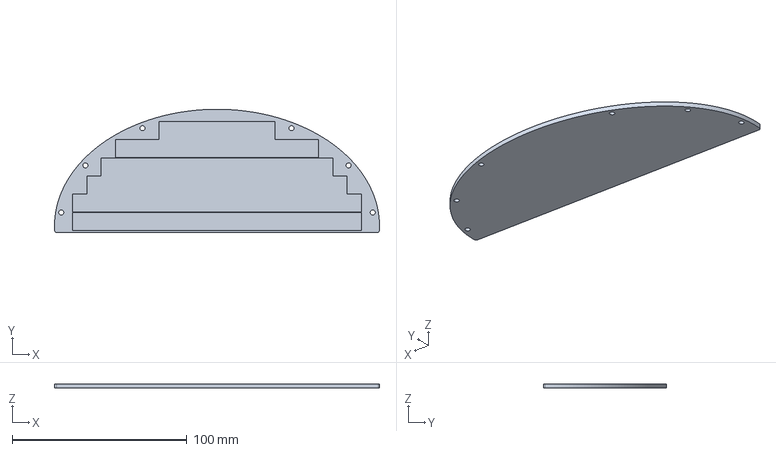
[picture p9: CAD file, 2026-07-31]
3d-print/LED Carrier.3mf
186.1 x 70.7 x 2.50 mm

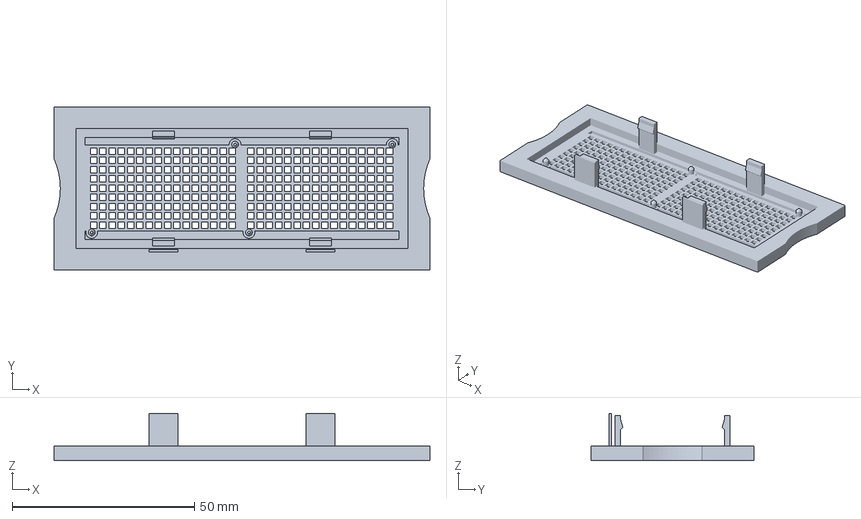
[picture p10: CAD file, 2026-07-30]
3d-print/Matrix Testfit.3mf
103.3 x 44.8 x 13.0 mm

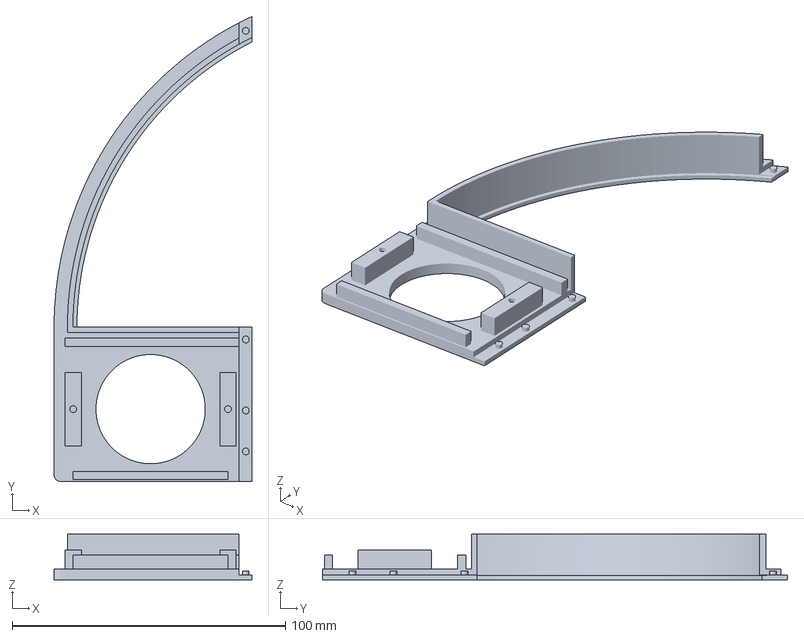
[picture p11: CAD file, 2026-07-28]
3d-print/Matrix Front Plate Left.3mf
72.4 x 170.3 x 16.7 mm

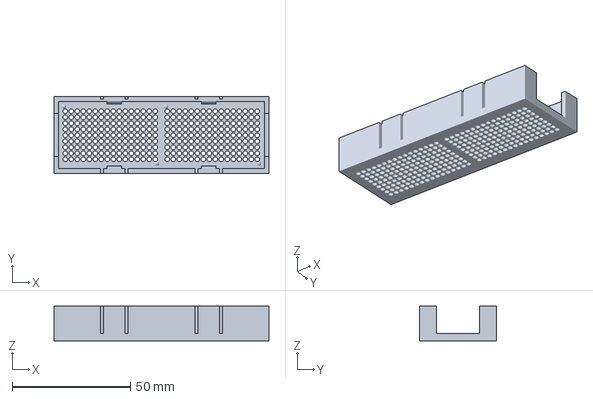
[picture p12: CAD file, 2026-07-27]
3d-print/Matrix Front Plate.3mf
91.0 x 32.5 x 14.8 mm

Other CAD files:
3d-print/SoundMachine.blend
3d-print/models/bottom-plate.stl
3d-print/models/dome.stl
3d-print/models/front-module.stl
3d-print/models/knob.stl
3d-print/models/led-carrier.stl
3d-print/models/matrix-testfit.stl

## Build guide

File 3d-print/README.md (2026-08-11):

# 3D-printed parts

Three reference sheets and the printable parts, all generated, all sharing one
source of truth.

> **Prototype 1 has been printed and assembled.** These parts are as-built, not
> proposals — treat a change here as a change to a machine that exists.
>
> **This folder is still live.** `enclosure_geom.py` remains the source of truth
> for the LED crescent (`packages/hw/crescent.yaml` carries a *copy* of its
> output), and `check_docs.py` still enforces that the firmware and all four prose
> documents agree with it. Run it after any geometry change.
>
> The session-by-session build journal that used to live here as `WIP-NOTES.md`
> is no longer on `main` — it is preserved on the **v1 release branch**, and its
> conclusions are distilled in [`../RETROSPECTIVE.md`](../RETROSPECTIVE.md). Read
> that before re-opening a decision: a surprising number of the parts below are
> shaped by a failure that is not obvious from the geometry.

| Sheet | File | What it answers |
|---|---|---|
| 1 | [`enclosure-drawing.svg`](enclosure-drawing.svg) | the shell — top / front / side / rear, assembled and exploded |
| 2 | [`enclosure-internals.svg`](enclosure-internals.svg) | the front module, the slide-up joint, the fixings, the chassis |
| 3 | [`enclosure-wiring.svg`](enclosure-wiring.svg) | the I2C chain, direct GPIO, power, and where each board sits |

| Part | File | Status |
|---|---|---|
| **Front module** | [`front-module.stl`](models/front-module.stl) | printable **whole** — 194.8 × 148.1 × 18.8, 68.2 cm³ |
| **LED carrier** | [`led-carrier.stl`](models/led-carrier.stl) | printable — 186.1 × 70.7 × 2.5, 23.2 cm³ |
| **Diffuser** | [`diffuser.svg`](diffuser.svg) | Glowforge cut file, 1:1 mm — 3 mm opal acrylic, round-notched for the carrier pads |
| **Dome** | [`dome.stl`](models/dome.stl) | printable — 202 × 155.7 × 64, 153.2 cm³ |
| **Bottom plate** | [`bottom-plate.stl`](models/bottom-plate.stl) | printable — 196.4 × 58.4 × 6.6, 45.0 cm³ |
| **Knob** | [`knob.stl`](models/knob.stl) | printable — Ø34 × 20, 13.2 cm³ |
| **Matrix test coupon** | [`matrix-testfit.stl`](models/matrix-testfit.stl) | print **this first** — 103 × 45 × 13, 14 cm³. The clock mount cut straight out of the front module: lip, pocket, posts and all six clips. Validates the fit for ~20 min of filament instead of several hours. |
| Matrix tray | [`matrix-tray.stl`](models/matrix-tray.stl) | printable — **no longer in the assembly**, the front module carries the matrices itself |

Every solid is watertight, one connected body, and fits a 220 bed.

## Print orientations, and what each one costs

| Part | Orientation | Why, and what it costs |
|---|---|---|
| Dome | **rear wall down** | The rear wall is the first layer — the flattest face and the one with the most features — and every boss on it then grows straight up off the bed. Cost: anything projecting inward off a SIDE wall or the CROWN is horizontal to the build, so the **retaining rib** and the **crown standoffs** each need a 45° ramp, and the front lip's rear face is an unavoidable 5 mm shelf. See "Printing rear-wall down means +z is down". |
| Front module | **face down** | The facade is the bottom layer, and it is the one surface anyone sees. Everything else grows upward off the bed. |
| Bottom plate | **underside down** | Counterbores and foot pockets open downward and print as plain holes from layer one; the bosses grow upward. The underside is also what you see picking the machine up. |
| LED carrier | **strip side down** | A warped carrier is a varying air gap, and that shows through the diffuser. |
| Knob | **base down** | The base cut is the bed. The steepest overhang is the very first layer, at 42.5° from vertical — inside the support-free limit, which the run checks. |

> ### Printing rear-wall down means +z is *down*
> This is the single fact that decides which features on the dome need support,
> and it is easy to get backwards: the bed is at **z = D (64)** and the build runs
> towards **z = 0**, so a face whose normal points at **+z** is a face pointing at
> the bed. Two features were built without noticing:
>
> - **The retaining rib's rear face** — a 3 mm shelf projecting into open cavity
>   right round both flanks and the arch. It now **grows in gradually** from 3 mm
>   further back, a 45° underside that prints unsupported.
> - **The crown standoffs** — a boss hanging off the ceiling is printed *lying on
>   its side*, so its whole rear half overhangs. Support there is a tower rising
>   the full depth of a closed dome, which you then cannot reach in to remove.
>   Each now has a 45° **buttress** on its rear side only; the front face is
>   printed last and is self-supporting.
>
> **The front lip's rear face cannot be ramped and stays square.** It looks like
> the same problem as the rib and is not: the rib is *behind* the module, the lip
> is *in front* of it, and a ramp there would reach inside `REVEAL` and foul the
> module's rim as it slides up — the same mistake the seating ledge made. It is
> the last 2 mm of the print, it is a closed ring so the droop is even, and the
> face it droops onto is the hidden back of the bezel.
>
> **Ramps are modelled as true angled faces, never as staircases.** Stepping is
> the slicer's job — Orca resolves a real 45° surface to the actual nozzle and
> layer height far better than a 0.25 mm staircase frozen into an STL can. The
> rib ramp, the crown buttresses and the louvres were all originally built as
> stacks of ~12 thin slabs; all three are now single lofted solids (the convex
> hull of two sections, whose lateral surface *is* the straight rule between
> them). That removed **12 000 triangles** from the dome and eliminated the whole
> class of mesh failure below — every one of which came from stacked slabs
> sharing faces. `check_docs.py` fails if either ever goes back to being stepped.
>
> `gen_dome.py` now **measures** this off the exported solid rather than trusting
> the argument above. Four things that check had to learn:
> - **A tolerance of one degree.** The limit is 45° and the ramps are *built* at
>   45°, so a strict `> 45` flagged 1757 mm² of the very geometry that fixes the
>   problem. The rib ramp measures 44.6–45.0° across the arch, because the D
>   outline insets its semi-axes rather than truly offsetting them.
> - **Width, not area.** A 3 mm shelf broken into twelve 0.25 mm steps has exactly
>   the same downward-facing area. Area cannot tell a staircase from a shelf; what
>   decides support is how far a ledge reaches from whatever holds it up.
> - **Connected regions, not coplanar facets.** Grouping by coplanarity is blind
>   to *curved* overhangs — deleting the crown buttresses left every boss hanging
>   by its rear half and the audit still said ALL CLEAR, because a cylinder has no
>   flat facet to group.
> - **A bore's roof is a bridge, not a cantilever.** The six Ø4 insert bores and
>   the Ø30 knob pocket all have unsupported roofs, and by area they look like the
>   rib's shelf. They are anchored on *both* sides and span only a chord —
>   4.9 mm for the Ø30 pocket, not 30. They are excluded by name, with their
>   bridge spans asserted, rather than by raising the threshold until they stop
>   complaining.
>
> Both ramps are verified by deletion: remove either and the audit fails.

Envelope: **202 × 79 × 155.7**. Both printed parts fit a **220 bed whole** — the
front module used to be 250.8 wide and had to split; rotating the speakers and
lifting the mic array removed the need. See "Printing it on a 220 bed".

```sh
# sheets (stdlib only)
python3 gen_drawing.py && python3 gen_internals.py && python3 gen_wiring.py
# PNGs are NOT generated by the scripts -- render them from the SVGs
python3 -c "import cairosvg
for f in ('enclosure-drawing','enclosure-internals','enclosure-wiring'):
    cairosvg.svg2png(url=f+'.svg', write_to=f+'.png', scale=3)"
# solids (need manifold3d; the mesh validation needs ALL of
# trimesh + scipy + rtree + networkx -- see the note below, a missing one
# used to make the validation skip itself silently)
../.venv/bin/pip install manifold3d trimesh scipy rtree networkx matplotlib
../.venv/bin/python gen_front_plate.py && ../.venv/bin/python gen_led_carrier.py
../.venv/bin/python gen_dome.py && ../.venv/bin/python gen_bottom_plate.py
../.venv/bin/python gen_knob.py
python3 gen_diffuser.py && python3 gen_tray.py
python3 check_docs.py            # prose vs geometry  -> ALL SYNCED
python3 verify_exports.py        # STLs on disk vs the models -> ALL EXPORTS MATCH
```

Code layout — **no sheet and no solid invents a dimension**:

```
enclosure_geom.py   every parameter, every derived value, the part outlines
drawlib.py          SVG primitives, dimensions, leaders, sheet chrome
gen_drawing.py      sheet 1        gen_internals.py    sheet 2
gen_wiring.py       sheet 3        gen_tray.py         models/matrix-tray.stl
gen_front_plate.py  models/front-module.stl
gen_led_carrier.py  models/led-carrier.stl
gen_diffuser.py     diffuser.svg   check_docs.py     prose vs geometry
                                   verify_exports.py file vs model
gen_dome.py         models/dome.stl
gen_bottom_plate.py models/bottom-plate.stl
gen_knob.py         models/knob.stl

models/             ALL printable solids live here. Drawings, cut files and
                    previews stay beside the code.
```

> ### ⚠️ One file, one definition — this has bitten twice
> **`gen_front_plate.py` once contained the entire build twice.** Python ran both
> copies and the second reassigned `body`, silently discarding the first. The two
> differed in exactly one block: the *dead* copy had the speaker mount correctly
> rotated, the *live* one still had the pre-rotation version. A fix applied to the
> wrong copy looked applied and changed nothing, and cost a session of probing.
>
> **The z stack was derived in two places.** `DIFF_LIP` and `CAV_Z` lived in
> `gen_front_plate.py` while the LED carrier needed the same stack. Both now live
> in `enclosure_geom.py`, and `gen_front_plate.py` *asserts* its local cavity
> ellipse against the shared one at import.

`enclosure_geom.py` also carries the clearance model. Every generator ends in
`ALL CLEAR` or a problem count: `gen_drawing.py` checks the facade stack and the
rear wall, `gen_internals.py` the fixing lugs, `gen_front_plate.py` the solid
(see below). Change a component and re-run — the envelope re-derives and every
check re-runs.

## How the solids are checked

A render proves nothing. `gen_front_plate.py` and `gen_led_carrier.py` validate
three ways, and only print `ALL CLEAR` if all three pass:

- **Mesh sanity** — watertight, consistent winding, and **exactly one connected
  body** (more means a feature is floating in space).
- **Envelope interference, negative.** Every component that the part carries gets
  its swept volume intersected with the printed solid; the result must be *zero*
  mm³. The matrix pair (with its mounting holes punched out, since the posts are
  *supposed* to be in them), the backpacks behind it, **all 288 LEDs**, the
  acrylic, the air gap (carrier pads excepted, by subtracting the exact pad
  solids), both speaker bodies, all four nubs, the mic board, and the dome's
  groove band.
- **Feature presence, positive.** Interference tests can't notice a retention
  feature that quietly vanished into a boolean, so a 1 mm probe checks that
  plastic actually *exists* at every locating post, seating pad, spine, carrier
  pad, clip beam and clip hook — that each hook overhangs the board *above* its
  back face but not below — that each pilot is open to depth but doesn't break
  through — and that the clock aperture is genuinely open.

Two checks earned their keep immediately. The **288-LED** test caught the seating
pads sitting on the corner LEDs, which a bounding box around the LED field had
waved through. The **outboard-flank** probe replaced two "locating rib" probes
that were passing by accidentally hitting a stiffening rib — for features that no
longer existed.

> ### ⚠️ A check is only as good as its measuring stick
> Three separate bugs shipped past a green `ALL CLEAR` because the *check* was
> wrong, not the part:
> - clearance measured as a **chord** instead of a true distance to the ellipse —
>   an LED body sat 0.58 mm outside the diffuser while everything read clear;
> - a pad **presence probe** sampled once near the feature's tip, and passed on a
>   1.13 mm stub floating over a hole;
> - the pad **clearance test** checked pixels but not the ribbon they are cut
>   from, and put a fixing on top of a strip.
>
> When a check passes, ask what it would have to see to fail.

Plus a containment guard: the whole solid is intersected with the module outline
before export, so a boss can never hang off the edge. It reports how much it
trimmed, and that has to be zero too.

---

# Front module

**194.8 × 148.1 × 21.3**, one part carrying the whole facade, printed **whole**.
Print **face down**: the facade is then the bottom layer (the one surface anyone
sees) and every boss, wall, clip and pad grows upward off the bed, so there is
nothing to support.

| Zone | What the part does |
|---|---|
| **Crescent** | 89 × 62.7 elliptical through aperture, a 1.5 mm ledge, then a 90.5 × 64.2 pocket the opal acrylic drops into **from behind**, then a 12 mm air gap inside a 2 mm cavity wall. The wall runs to z=18.83 and is the part's main stiffener. Six **tapered pads** on its inner face take the LED carrier. |
| **Clock** | ONE open 84 × 23 aperture — no per-pixel holes. The two matrices are **recessed into the facade**: the aperture is cut only through the front **2 mm**, and a pocket behind it takes the boards, which seat on the back of that lip. **2 locating posts per board** (no pads — the lip is the datum), then **six clips**, two on each long edge and one at each end, hooking the back of the whole stack. |
| **Speakers** | Ø40 grille through, and a **post above and below each body on its vertical centreline** (10 × 6, standing 7 mm proud, Ø2.5 pilot). The M3 goes in **from behind**, through the speaker's nub, into the post. **No ribs on any face** — the bodies are rotated 90° so the nubs are top and bottom, and two screws on one line fix x, y and rotation between them. |
| **Mic array** | 4 × Ø2.5 ports on Ø4.5 raised gasket lands, in a 110.8 × 12.8 × 2 channel, with two M3 pilot bosses. |
| **Stiffening** | **Two spines**, one above the matrix and one below, spanning the middle between the speaker seats. |

> ### ⚠️ The stiffening ribs used to run through the matrix
> Short ribs reaching inboard from each speaker at `y = SPK_Y` were safe when the
> clock sat on the floor. The clock is now **centred on the speakers**, so
> `SPK_Y` *is* the matrix mid-height — each rib ran straight through the boards,
> 49.8 mm³ into the matrix envelope, into 288 LEDs, and through the end clips'
> hook zone. Four separate check failures, one rib.
>
> There is nowhere left to put them (speaker seat to end-clip outer face is
> **0.77 mm**), so they were replaced by the second spine below the matrix. A
> symmetric pair braces the plate better than one spine plus two stubs did.

## Why there is no tray and no pocket

**The two matrices are only loosely soldered to each other.** A pocket locates
the *pair* — and the pair is exactly the thing that isn't rigid, so the solder
joint would end up carrying the alignment and would work loose. Instead each
board is located by its **own** two posts through its own Ø2.0 diagonal holes,
and the six clips clamp both boards flat against the facade.

**The boards are recessed, and that was worth more than it looks.** They used to
seat on the plate's *back* face, which put the LEDs 4.6 mm behind the cloth at
the bottom of an open 84 × 23 well. That well is only 1.34 mm wider than the LED
field vertically, so the top and bottom rows disappeared at **16°** off-axis —
and a bedside clock is a thing you look *down* at. Cutting the aperture through
only the front 2 mm and pocketing the boards behind it holds those rows to
**34°** (and 63° across). Nothing flagged the original because it was not a
clearance problem: everything fitted perfectly.

The board seats on the **back of the facade lip**, which overlaps it by 1.18 mm
at the sides and 2.47 top and bottom — clear of the LED field, which starts
2.5 mm and 3.8 mm in from the board edges. All four locating posts land on that
same lip (all four holes are 1.905 mm from a horizontal board edge). The old
seating pads are retired: the lip *is* the datum, and pads on top of it would
only lift the board back off it.

**The clips root in the pocket floor, not on the back face.** Recessing the board
moves the hook forward, and a clip still rooted at the back face would lose that
length from its beam — which matters more than anything else, because strain goes
as 1/L². Rooting root and hook together makes the strain independent of how deep
the boards are recessed, which is what makes the recess a free choice.

Room for the clips came free. The matrix/mic cluster used to be squeezed to
1 mm and 2 mm gaps back when it set the enclosure height — it doesn't any more
(the speaker seats do, at y=56), so ~9 mm of slack was sitting unused. Spending
4 mm above and 4 mm below buys clips on all four sides and costs no height.

## ⚠️ Measure these before printing (top of `gen_front_plate.py`)

| Param | Default | What to check |
|---|---|---|
| `SPK_NUB_H` | 6.0 mm | **The important one now.** It sets `SPK_POST_W`, and post width is what keeps the post clear of the mic array (9.9 mm) — which is what lets the array sit above the speaker *body* instead of above the post. |
| `SPK_NUB_PROJ` | 4.0 mm | Now a *height* driver, not a width one: 6 mm at each end of the body. |
| `MTX_STACK_H` | **7.0 mm, measured** | Matrix front → backpack back. Derives the header gap (3.8). It is the **lever arm of every clip**, not a clearance: it was assumed at 8.2 and the 1.2 mm error moved the clip strain from 1.20 % to 1.83 %. |
| `MIC_HOLE_EDGE` | **22.0 mm, measured** | Array end → *near edge* of its M3 hole. The boss centre (31.4 from centre) is derived from it. |
| `DIFF_GAP` | 12.0 mm | Diffusion air gap — ~0.7 × the LED pitch is the starting point. Test-print a crescent corner. **It moves `CARRIER_Z0` with it.** |
| `CLOTH_T` | 0.6 mm | Grille cloth per layer; it goes through the dome groove with the module. |

Already measured, no longer guesses: `LED_PITCH` **16.5** (was 16.7 nominal),
`STRIP_W` **10.0**, `LED_STRIP_T` **2.13** (was a 3.0 guess).

Snap features can't be simulated for fit. Test-print one corner of the clock
zone and tune `CLIP_REACH`, `CLIP_RAMP`, `CLIP_T` and `CLIP_W`.

## Printing it on a 220 bed

Both parts fit **whole**. The front module is 194.8 × 148.1 against a
Flashforge Adventurer 5M Pro's 220 × 220 × 220 — 25.2 / 71.9 mm to spare.

It was not always so. At **250.8 mm** wide it fit at no orientation:

- **Rotating on the bed doesn't help.** This is a D — near-rectangular — so
  rotating only *grows* the axis-aligned footprint. 0° is already the best case.
  The best of ~40,000 orientations was still 9.2 mm over.
- **Tilting does fit, and is still wrong.** At 45° it came to 185.7 × 182 ×
  185.7, inside the box. But that stands the facade up on supports, and the
  facade is the one surface anyone looks at.

Three changes got it under 220, and none of them were "make it smaller":

1. **Speakers rotated 90°** — nubs to top and bottom, which takes the mounting
   post out of the width chain, and narrows the body 50 → 45.
2. **Mic array moved above the speakers** — the middle of the facade then only
   has to hold the 86 mm matrix pair, not the 110 mm array.
3. **Crown flattened** to `CROWN_K = 0.74` — necessary, because
   `H = CRES_Y + k·W/2` and the narrower body would otherwise have made the front
   nearly square.

The **seam logic is retained** in `gen_front_plate.py` behind `NEEDS_SPLIT`,
currently **off**. It re-enables automatically if anything pushes the part back
over the bed — the seam's location was hard-won (it had to keep the whole clock
on one piece and put its lap in the one 6.95 mm corridor containing no boss
standing on thinned mic-channel floor).

---

# LED carrier

**185.0 × 69.2 × 4.7**, a 2.5 mm plate carrying the six cut strip segments at a
controlled standoff. Print **face down** — "face" being the side the strips stick
to. A warped carrier is a varying air gap, and that is visible through the
diffuser.

Z stack, from the front face of the facade:

```
facade front        0
acrylic front       1.50   DIFF_LIP
acrylic back        4.70   + DIFF_REBATE
LED emitting face  16.70   + DIFF_GAP      = CAV_Z, cavity wall back
strip back         18.83   + LED_STRIP_T   = CARRIER_Z0, the carrier's seat
carrier back       21.33   + CARRIER_T     == FM_DEPTH
```

The cavity wall runs to `CARRIER_Z0`, **not** `CAV_Z` — one strip thickness past
the LED plane — so it shrouds the ribbon and its back face is the seat.

## Why screws and not a snap fit

A cantilever/snap arrangement is used elsewhere on this part (the clock matrices)
and would be consistent. It does not work here:

- **The clips would have nowhere to deflect.** A clip gripping the plate's edge
  has to flex *outward*, and outboard of the cavity wall there is **0.9 mm**
  before the dome's retaining-rib keep-out. Clips that deflect *inward* need the
  plate to sit inside the cavity, and then it cannot seat on the wall's back
  face — which is the datum the air gap is referenced to.
- **Clips hold a plate wherever the worst clip decides.** The job here is a
  uniform 12 mm standoff across a 185 mm span. Six screws pull it onto a hard
  seat and take up print variation; six clips leave it on whichever hook came out
  proudest. Over that span on FDM, that is an even glow versus a bright band.

Screws also make the strips serviceable — five soldered segment-to-segment joints
are the most likely thing on the build to need rework.

## The pads

Six local thickenings on the **inside** of the cavity wall. Three alternatives
were considered and cost more:

- *ears reaching outward onto the rim* — only **0.9 mm** of rim is free. Making
  room means `RIM_MIN` 12 → ~16, which shrinks the crescent to 85 × 58.7 and
  drops it to five rows.
- *pillars up from the facade floor* — 12 mm columns inside a lit cavity.
- *captured by the dome, no screws* — locates the plate, never clamps it.

They double as buttresses for what is otherwise a 2 × 19 mm unsupported fin.

> ### ⚠️ Three things the pads got wrong before they came out right
> **They were built before the cuts**, so the acrylic-pocket / air-gap bore
> promptly sliced them away — the bore is a half-disc of `DIFF_R` and the pads
> live inside `DIFF_R` by definition, that being the point of them. All that
> survived was 1.13 mm of stub at the top with an 8 mm pilot drilling into air.
> The presence probe passed because it sampled inside that stub. **A single probe
> near a feature's tip cannot tell a boss from a lid** — they are now sampled at
> three heights plus a pilot depth check.
>
> **They ran down to the facade**, straight through the opal acrylic's pocket —
> 607 mm³ of interference, the disc simply could not drop in. They now start at
> the pocket floor.
>
> **The air-gap clash subtracted a plain cylinder** as a stand-in for the pad.
> The moment the pad grew a taper, the stand-in stopped matching and the check
> reported interference that was really its own bad approximation. It now
> subtracts the exact same solid the part is built from.

**FDM shape.** The module prints face down, so anything that widens as it rises
overhangs. The pad starts at the acrylic pocket floor and grows **out of the
wall** on a ramp, reaching full section one pad-radius later. Self-supporting, so
no support is needed inside the optical cavity where scarring would show through
the acrylic. The ramp is also the gusset, at the root where a boss standing 19 mm
off a 2 mm wall wants to snap.

> ### ⚠️ The ramp is a SKEWED cone, apex buried in the wall
> A straight cone tapering to a point on the pad's own centreline puts that point
> `PAD_OFFSET_IN` (1.55 mm) clear of the wall, **hanging in mid-air** — the bore
> has removed everything below `PAD_Z0`. On FDM the first layers print into
> nothing. It reads as a tidy taper in section and is unbuildable.
>
> The apex is therefore pushed outward past the cavity's inner face and *into*
> the wall material (`APEX_BURY`), and the solid is the convex hull of that apex
> and the shaft's base circle. Every layer touches the wall.
>
> **`connected bodies == 1` does not catch this** — a floating tip is still
> joined to the shaft above it, so the part stays one body while its base prints
> into air. There is now a dedicated probe: at three heights up the ramp, there
> must be material *at the wall's inner face*.

> ### ⚠️ It had a base flare, and the flare had to go
> `PAD_DRAFT` used to widen the base by 1.5 mm per side. A round flare grows
> **both** ways: outward through the cavity wall — 1.2 mm into the dome's
> retaining-rib band, which is the one place a boss jams the whole assembly — and
> inward, 1.5 mm deeper into the acrylic pane's path, which is 1.5 mm more notch
> showing past the ledge. The outward half is now clipped by construction (the
> pad is intersected with the cavity envelope, so it *cannot* break the outer
> plane whatever draft it is given) and the inward half was simply deleted.
>
> `pad_wall_margins()` missed the whole thing because it measured the **shaft**
> radius and the flare was bigger — a margin check against the wrong radius,
> actively vouching for the failure. There is now a geometric clash test
> alongside it.

**M2.5, not M3** — everything else on the build is M3, but an M3 pad is 8 mm
across and at 8 mm the lowest usable angle is 20°, which leaves the plate's
bottom corners (and the widest, most visible LED row) on a fixing 19 mm away.
M2.5 shrinks the pad to 6.5 and opens a band at 7.5°, right beside those corners.

## The diffuser notches are ROUND

The pane sits in front of the pads, so at its own plane there is no pad in the
notch — **every notch is a straight-through hole in the diffuser**, and light
reaching it escapes undiffused. The notch exists only so the pane can travel the
depth of the cavity to reach its pocket; once seated it does nothing.

So it is made as small as the travel allows. What it has to clear is a
**cylinder**, and the pane's travel is straight along z, so the swept profile in
the pane's plane is exactly that circle. A circular bite of `PAD_W/2 + clearance`
is not an approximation — it is the minimum.

| | square bite | round bite |
|---|---|---|
| per notch | 42.0 mm² | **31.3 mm²** |
| over six | 252 mm² | **186 mm²** — 26% less |

It also hugs the pad, so a clear-glue fillet is a constant gap rather than four
corners of varying width, and it removes the inside corners that make cast
acrylic craze when handled.

**It cannot be a closed hole.** Threading the pane over the pads like a plate
over posts would leak nothing at all, but the hole would need a pane radius of
93.6 plus a web, and the pocket is 91.4. It has to break the edge.

## The stops

**Stops, not channels.** The rows BUTT — pitch 10.4 against a 10.0 ribbon — so
there is 0.4 mm between adjacent tapes and no room for a dividing wall at all.
(Even at the old 11.0 pitch it was 0.5 mm a side, under one nozzle width.)

**And only 3.0 mm across, not the ribbon's full 10.** The stops sit at the row
*ends*, which is exactly the perimeter the fixing pads need; at full ribbon width
they blocked every usable pad angle below 20°. A 3 mm nub at the row's centre
height stops the segment just as well — nothing pushes it sideways, and the
adhesive backing holds it down.

`pad_angle_bands()` prints the viable angles on every run. **Re-read that table
rather than nudging `CARRIER_FIX_DEG` by eye.**

> ### ⚠️ There is no pad at the apex
> 90° has more room from the pixels than anywhere else on the wall — and the top
> row's **ribbon** runs straight through it. The row is only 2 px, so the LEDs are
> nowhere near, which is exactly why a check that looked at pixels alone waved it
> through. The preview render caught it. `pad_clearances()` now tests pixels, end
> stops **and** ribbons.

---

# Dual CharliePlex matrix snap-in tray

> **⚠️ Superseded in the assembly.** The front module now carries the two
> matrices directly — posts through each board's own holes, six clips all round
> — so there is no tray in the build any more. This part still works and is
> still generated; keep it if you want the matrices as a self-contained module,
> and note that its front face has **per-pixel light tunnels**, which the front
> module deliberately does not.

`models/matrix-tray.stl` — a mount that holds **two butted Adafruit IS31FL3731 16×9
CharliePlex matrices *and* their two driver backpacks** as one solid unit, with
a **flat front face** (for mounting flush against cloth) and all retention on
the back. No screws, no heat-set inserts — it snaps together.

Generated with `manifold3d`; validated **watertight, 2-manifold, genus-288**
(the 288 light windows) — imports into OrcaSlicer with no repair.

Board geometry is from Adafruit's EAGLE files (LED matrix + STEMMA backpack), so
outlines, LED positions, and hole positions are exact, not estimated.

## How it holds together

Stack, front → back: `cloth │ front face │ matrices │ gap │ backpacks │`

- **Flat front:** 1.5 mm face (`FACE_T`) with one Ø2.0 light window per LED
  (288 total). The matrices sit right behind it, LEDs pointing into the windows.
  Kept thin on purpose — a deep face turns each window into a light pipe and
  kills off-axis visibility (Ø2.0 × 1.5 mm ≈ ±34° half-angle). Raise toward
  ~2 mm for more per-LED isolation / a stiffer face.
- **Matrices:** *located* (not retained) by **4 plain alignment posts** through
  each matrix's two diagonal Ø2.0 holes — the only holes that line up. The posts
  have a small chamfered lead-in tip and **no barb** (barbs are hard to print
  cleanly on FDM). The matrices are held forward by the clamped stack, not by
  the posts.
- **The gap** between matrix and backpack is set by *your own* inter-board
  header pins — the tray just spans it (parameter `STACK_GAP`).
- **Backpacks:** retained by **4 cantilever snap fingers** on the long walls.
  Each finger tip is a **triangular hook**: a shallow lead-in ramp the board
  rides over, then a 45° retaining facet that clicks behind the backpack's back
  face and pulls the whole stack forward against the front. 45° keeps the
  overhang FDM-printable; the angled facet gives more hold-down than a round bump.
- **Wires:** notches in both end walls, **18 mm wide to clear both STEMMA QT
  ports** on each backpack.

Everything is captured between the flat front and the rear snaps, so the stack
can't fall apart and the wires aren't stressed.

## Print & assemble

1. Import `models/matrix-tray.stl` into OrcaSlicer. Print **front-face-down** on the
   bed — gives the smoothest flat face against the cloth, and the posts/fingers
   print upward with no supports.
2. Push each **matrix** in from the back until its two holes snap onto the
   posts and it seats against the front face.
3. Push each **backpack** in until the snap fingers click behind it.

## ⚠️ Measure these before printing (top of `gen_tray.py`)

The design is exact for the boards, but three things depend on *your* build:

| Param | Default | What to check |
|---|---|---|
| `STACK_GAP` | 5.0 mm | **The important one.** Clear gap between matrix back and backpack front (your header-pin height). If this is wrong the snaps won't clamp. |
| `PCB_T` / `BP_T` | 1.6 mm | PCB thicknesses (calipers). |
| `LED_D` | 2.0 mm | Window Ø. Must clear the LED package so the matrix seats flat — measure an LED; enlarge if they don't nest into the tunnels. |

Also confirm: **two backpacks** (one per matrix)? And which wall the connectors
exit — I notched both ends; tell me if a side wall needs a slot instead.

Snap features can't be simulated for fit — **test-print one corner** (or the
whole thing) and tune if needed: `LIP_REACH` (how far the hook grabs),
`RAMP_RUN` (insertion ease), `FINGER_W`/`SLOT_W` (finger stiffness). The matrix
posts are `POST_D` (loosen if they bind in the Ø2.0 holes).

## Regenerating

```sh
python3 -m venv venv
venv/bin/pip install manifold3d trimesh matplotlib scipy
venv/bin/python gen_tray.py       # writes models/matrix-tray.stl (+ section preview)
```

All dimensions are parameters at the top of `gen_tray.py`.

---

# Enclosure reference drawing

`enclosure-drawing.svg` — a 1:1, third-angle drawing of the **shell**, for
modelling in Fusion 360. Not a released drawing; it is a dimensioned reference
that also does the packaging arithmetic. Regenerate with:

```sh
python3 gen_drawing.py                     # no dependencies
rsvg-convert -b white -z 2 enclosure-drawing.svg -o enclosure-drawing.png
```

## The form

A letter **"D" lying on its long flat side, extruded along the depth**: flat
bottom, straight sides, and a semicircular top of radius `W/2`. The crown is
therefore a **cylinder**, not a sphere — it curves in FRONT and is flat in SIDE.

The one rule that drives everything: **the shell arc and the LED crescent are
concentric**, both centred on `(W/2, CRES_Y)`. So the arc radius *is* `W/2`, and
the rim between shell and crescent is `W/2 − CRES_R`.

## Nothing is hand-set — W and H are derived

Only **D** is chosen. The facade is assembled bottom-up and the envelope falls
out of it, which is what makes collisions impossible by construction:

```
W = 2 × (plate edge + boss keep-out + flank + speaker body + flank
         + gap + half the matrix pair)                          = 202
H = CRES_Y + CROWN_K × W/2                       flattened half-ellipse
CRES_Y = floor + max(mic array top, speaker seat) + gap + LED radius
```

**⚠️ Widening also heightens.** The arch's horizontal semi-axis *is* `W/2`, so
every 2 mm of extra width adds `CROWN_K` mm of height. The **45 mm speaker body**
(as rotated) is what sets W:

| If the speaker body were | W | H |
|---|---|---|
| 40 wide | 192 | 152.0 |
| **45 wide (actual, rotated)** | **202** | **155.7** |
| 50 wide | 212 | 159.4 |

**The nub is no longer a width driver.** Rotating the bodies moved the posts out
of the width chain and into the height, where there was slack. Before the
rotation, nubs on the sides with a 50 mm body needed **W = 234** and did not fit
a 220 bed at any orientation.

`SPK_NUB_H` is now the parameter to measure: it sets the post *width*, and post
width is what keeps the post clear of the mic array — which is what lets the
array sit above the speaker body rather than above the post.

### The LED field IS the diffuser

| | value | what it is |
|---|---|---|
| `CRES_R × CRES_RY` | **89 × 62.7** | the visible aperture / lit crescent |
| `DIFF_R × DIFF_RY` | **91.4 × 65.1** | the acrylic pocket. The 2.4 mm ledge over the pane is set as large as the rim allows *for free*, to hide the notches |
| `LED_R × LED_RY` | **89 × 62.7** | the same. No separate, smaller LED arc. |
| `CRES_FADE` | **0** | there is no fade band any more |

The old arrangement kept the diffuser at R117 and the LED field at R96, with the
21 mm between them unlit on purpose. It went away with the flattened crown: the
crescent is now short enough that the pixels fill it, so the glow reaches the edge
and there is nothing left to fade across. Tightest LED-body-to-edge gap is **2.26 mm**.

**Row pitch is 10.4, derived not chosen** — floored at the ribbon width, because
the rows BUTT edge to edge. The floor used to carry a 1 mm gap and it cost three
pixels: 45 at an 11.0 pitch, 48 at 10.4, same shell. Row counts are solved for a constant **true
distance** to the ellipse (see below), and forced non-increasing bottom-first;
without that the solver returns things like 10/10/9/10 — every pixel legal,
silhouette obviously wrong. `gen_drawing.py` prints the table every run.

> ### ⚠️ Measure the ribbon, not the pixel
> A cut segment of *n* pixels is `n × LED_PITCH` of physical tape, not `(n−1) ×`:
> the cut lines sit half a pitch outboard of the end LEDs and trimming past them
> loses the solder pads. On the bottom row that is 6.9 mm more than the LED span.
> An 11-pixel row was a 181.5 mm strip going into a 181.0 mm cavity, and every
> sheet showed it as fine because the sheets drew **dots**.
>
> Two fixes: `ribbon_cap()` folds the constraint into the row solver, and
> `crescent_leds()` now draws each row's **tape outline with its cut lines** —
> one per pixel, LED centred in its own segment — so the sheets show the thing
> that actually has to fit.

> ### ⚠️ On an ellipse, the chord is not the clearance
> Every earlier check measured horizontally (chord) and, at the apex, vertically.
> On a circle those agree with the true distance. On an ellipse they do not, and
> the binding case is the **diagonal** one — an outer pixel two rows below the
> apex, where the boundary is falling away steeply. That is how a crown shipped
> with its top LED body 0.58 mm **outside** the diffuser while every check read
> clear. `ell_dist()` bisects the stationary condition of the squared distance
> and everything downstream uses it.

Width is set by what sits side by side on the facade:
`edge | boss keep-out | flank | 45 body | flank | gap | half the 86 matrix pair`.
The **110 mm array sits above both speakers**, not between them — that is the
other half of the width saving.

The module is **wrapped in cloth**, so the groove takes cloth + module + cloth
(5.6 for a 4 mm module) and the module outline shrinks by one cloth thickness.

## Clearance check

Every run prints the facade stack and a pass/fail clearance table, ending in
`ALL CLEAR` or `*** n COLLISION(S) ***`. Change any component and re-run: the
envelope re-derives and the table re-checks.

## Sheet layout

Two blocks, everything grouped for Inkscape/Illustrator or as a
Fusion canvas underlay:

```
ASSEMBLED   ASM-TOP, -FRONT, -SIDE, -REAR
EXPLODED    EXP-TOP, -FRONT, -SIDE
  each: dome | knob | front-plate | crescent-leds | bottom-plate
        matrix-tray | internals | trajectory | balloons | dims
```

The **REAR** view is a true flat face — the body is an extrusion, so the back is
the same "D" as the front. Everything on it is **centred on the width**: the Ø4
light pipe for the BH1750 lux sensor, the Ø11 DC barrel jack (which lines up with
the centred UPS pack), and the single 3-slot louvre stack above them. It sits
bottom-centre on
the sheet, out of projection, because there is no room for it beside the side
view; it is labelled as such.

Parts: **1** dome · **2** front module · **3** bottom plate · **4** matrix tray
(the sub-assembly above) · **5** knob.

## The front module is one part — but the diffuser is not

**Yes, make it one piece.** Everything that has to stay in register with
everything else — matrix aperture, speaker grilles, mic ports, diffuser opening —
now lives on a single part, so there are no tolerances stacking across a frame,
a bracket and a baffle. It also becomes a proper speaker baffle.

Two things that fall out of that decision:

- **The facade went 3 → 4 mm.** Two Ø40 drivers bolted to an unsupported 3 mm
  plate will flex and buzz. There are also ribs from each baffle ring out to the
  perimeter. It is a baffle now, not a cover.
- **The diffuser stays separate.** You cannot print an even diffuser. The printed
  part is the *frame and the diffusion cavity*; the Glowforge-cut white opal
  acrylic drops into a pocket from behind, then the LED strip seats on the back
  of the cavity on its own carrier plate. Stack is facade 4 │ acrylic 3 │
  **air gap 12** │ strip 2.13 │ carrier 2.5.

**The air gap is the number most likely to be wrong.** 12 mm is ~0.7× the 16.5 mm
LED pitch, the usual starting point for not seeing individual dots through opal.
Test-print one corner of the crescent before committing — and note it moves
`CARRIER_Z0`, and with it the whole depth of the front module.

## How it goes together

1. Front module **slides UP** into the dome's side grooves from below. Nothing
   retains it yet.
2. It seats against the lip — 4.5 mm of its edge captured all round, 0.5 mm
   sliding clearance.
3. **Bottom plate goes on.** Its top face is the module's datum: the module's
   bottom edge lands on it and can no longer drop.
4. **Six M3 screws** pull the bottom plate up into heat-set inserts in the dome
   bosses. No fastener touches the facade.

⚠️ **The fixings cannot be symmetric.** The floor is fully occupied, so every
boss is threaded into a gap between the drivers, the matrix tray, the UPS and the
Flex. `gen_internals.py` prints each boss's tightest clearance. The rear-right
pocket is 74 mm wide between the UPS and the wall — a 66 mm Flex leaves no room
for a boss beside it, so the right rear is unclamped. If the measured Flex is
≤60 mm, a seventh boss fits there.

The **TPA2016 is on the floor**, in the 12 mm slot under the lifted Flex — which
is also the shortest run to both speakers. It used to be on the rear wall, but
the UPS and the Flex now sit side by side and fill that wall below y=97.

## Two touch pads, one per shoulder

Copper strips ~40 × 22 mm bonded to the *inside* of each upper shoulder at
y = 112, just behind the ToF, so you can tap either side of the device.

**Both pads share one pin** (`GPIO4/D3`, TOUCH4). Self-capacitance sensing
measures the whole electrode net, so two pads on one net behave as a single
electrode that happens to be split in two — touching either half gives the same
delta. One binary sensor, one threshold, no OR logic.

⚠️ **Join the two leads at the MCU, not across the crown.** Each lead drops down
the inside of its own flank to the floor and they meet at the XIAO. The wire
count is identical either way, and it keeps a ~200 mm antenna out of the crown —
which is exactly where the SK6812 data line, the I2S lines and the STEMMA chain
all run. A wire taken straight across the crown would couple all of that
directly into the sensor. This is the decision that makes or breaks it.

What sharing costs: baseline capacitance roughly doubles while the finger delta
does not, so relative sensitivity drops (still comfortably usable), and a
side-to-side mismatch can't be trimmed out with per-pad thresholds.
**`GPIO2/D1` (TOUCH2) is kept free as the escape hatch** — if one side ends up
noticeably duller, splitting to two channels is one wire at the MCU plus a few
lines of YAML.

The crown is a **cylinder**, so a flat strip wraps onto it with no distortion as
long as its long axis runs front-to-back — which is why the pads are 40 mm along
the depth and only 22 mm across the arc.

Practical notes: thin the wall locally to ~1.6 mm behind each pad; calibrate with
`esp32_touch: setup_mode: true`. And watch for false triggers — the shoulders are
also where you grip the device to move it. If that bites, require a short hold
rather than a tap.

The **knob** is a full pebble — an ellipse of revolution truncated by a shallow
cut, Ø34 at its widest, meeting the crown on a Ø28 flat, 20 mm tall, blind Ø6 ×
15 bore with a D-flat. `KNOB_BASE_D` controls how much of the pebble is cut away;
raise it toward `KNOB_D` for more of a hemisphere.

The **ToF** sits on the crown just right of the knob, board turned **longwise
front-to-back** so its 17.78 mm edge clears the 25.4 mm encoder breakout.

Both crown boards carry **four** Ø2.5 mounting holes 2.54 mm in from every edge —
read out of Adafruit's own Eagle files, see [`../HARDWARE.md`](../HARDWARE.md). How
far apart the two boards sit is **not** a chosen board-edge gap: it is whatever
leaves `BOSS_GAP_MIN` (2 mm) of plastic between their nearest **bosses**
(`_resolve_tof_x()`), which works out at a 2.92 mm board gap.

> ### ⚠️ Their bosses are dead in line, so x separation is all there is
> Both patterns are 20.32 mm along the depth and both boards are centred on the
> same depth, so the encoder's right-hand bosses and the ToF's left-hand bosses sit
> at **identical** depths — there is no diagonal to gain clearance from. Against
> the old 1.5 mm board-edge gap that left **0.59 mm** between two Ø6 posts, which
> is not an intersection (so a non-intersection check passed it) and prints as one
> blob. This is the same lesson the RTC's wall search recorded: *the bosses are the
> binding constraint, not the board.*

## ⚠️ What the drawing found

| | Constraint |
|---|---|
| **Width ↔ height are coupled** | The arc radius *is* `W/2`, so you cannot trade height for width — see above. |
| **The speaker body sizes the box** | 50 × 45 × 22 sealed boxes, not bare cones. **Rotated 90°**, the 45 mm face sets W, which sets H. |
| **The mic array sits above the speakers** | At 110 mm it cannot fit between two driver boxes. Moving it up left the middle carrying only the 86 mm matrix pair — half of the 258 → 202 saving. |
| **The UPS board must stand up** | It is 60 × 93; 93 mm will not lie down in a 59 mm interior. Standing also aligns its barrel jack with the rear cutout. |
| **The UPS and Flex cannot stack** | 93 + 70 = 163 into a 157.5 interior. They sit side by side on the rear wall instead, which pushed the amp onto the floor and made the barrel jack a panel-mount part on a flying lead. |
| **Bottom-row pixels were burying themselves** | The crescent baseline is a row *centre*, so it has to clear the speaker seats by the LED radius as well as the gap. |
| **Speakers hang on nubs, top and bottom** | Not a baffle bolt pattern. One nub per 45 mm face, landing 7 mm behind the front face. Rotated, the posts cost **height**, not width — which is what got the part onto the bed. |
| **The ribbon fits before the pixel does** | A segment of n pixels is n × 16.5 mm of tape, a full pitch longer than the span between its end LEDs. The bottom row's tape was 0.5 mm too long for the cavity while the dots looked fine. This is why the crescent holds 45 px, not 48. |
| **A centred vent stack sits behind the Flex — only if it is level with it** | That objection sent the vents to two flanking stacks, which then fenced off both upper quadrants of the rear wall. Lifted *above* the Flex, over the light pipe, one wide stack answers it and gives both quadrants back at identical free area. |
| **The lux pipe has a ~5 mm slot to live in** | UPS to y=97, Flex from y=102. A centred pipe gets exactly that gap — Ø3, 1 mm clear each side. Any tighter and it has to move to the crown. |
| **Fixings are wall lugs, and asymmetric** | The floor is fully spoken for. No lug fits on the front edge at all — the plate's front edge is captured by the ledge and the module instead. |
| **Charge is a barrel jack** | 12.6 V 2 A, not USB-C. The only USB-C is the XIAO's internal flashing port. |
| **The sensor breakouts have four holes, not two** | Encoder, ToF and BH1750 were each modelled on an invented two-hole pitch. All three carry four Ø2.5 holes 2.54 mm in from every edge (the DS3231 is the one exception — top pair only, Ø3.0). Read from the vendors' Eagle files; see [`../HARDWARE.md`](../HARDWARE.md). |
| **The crown bosses collide before the boards do** | With the real patterns, the encoder's and ToF's bosses sit at identical depths and 1.5 mm of board gap left **0.59 mm** between two Ø6 posts. The gap is now derived from boss clearance, not chosen. |
| **A four-hole board off the apex tilts** | Two bosses on one x cannot tilt; four spanning 12.7 mm on the falling shoulder tilt the ToF **10.7°**, aiming its 25° cone into the side of its own vertical pinhole. Boss tips are built coplanar so each board sits flat. |

### …and what the *solid* found, which the drawing could not

Building the real part surfaced a class of error the 2D views are blind to:

| | Constraint |
|---|---|
| **The edge budget is the dome's RIB, not the outline** | The module slides up a groove, so the outer `RIB_W` of its **back face** must stay plain along both flanks and the arc. On the flat, a boss 1 mm inside the outline looks fine; in reality it jams the assembly. Four features were inside the band — a speaker post by 4.35 mm, the spine by the full 5, the speaker ribs by 1.35, the cavity wall by 0.10. |
| **`RIM_MIN` is derived, not an aesthetic choice** | `REVEAL + BOSS_EDGE + DIFF_MARGIN + CAV_WALL` is the smallest rim the shell can carry, because the diffusion cavity wall has to clear that same rib band. The 12 mm "look" minimum only wins when it is larger. |
| **`RIB_W` 5 → 3 paid for itself** | The keep-out is multiplied four times across the width, so 2 mm off the rib gave back 4 mm of body. A 3 mm rib behind a 4 mm plate is ample — the bottom plate already traps the module. |
| **The bottom edge is exempt from all of it** | It is the open end the module slides in through. Treating the keep-out as a plain ring around the outline flagged 2143 mm³ of false positives until the bottom strip was excluded. |
| **The two matrices are not one part** | They are only loosely soldered to each other, so a pocket — which locates the *pair* — is the wrong tool. Each board gets its own locating posts, and six clips on all four sides clamp the pair. |
| **Pads cannot go on the board corners** | The corners are inside the LED field's bounding box; a Ø4 pad there lands on the outermost LEDs. Only the strips above the top row and below the bottom row are genuinely clear, so the pads sit at mid-width. |
| **Clip roots need real estate the tight cluster had spent** | 1 mm below the matrix and 2 mm above it was fine when the cluster set the height. It does not — the speaker seats do, at y=56 — so ~9 mm of slack was sitting unused. Spending 4 mm above and below buys clips on all four sides for free. |
| **After the rotation, no rib fits anywhere** | The nubs are top and bottom, so top/bottom ribs would foul them — and the flanks only have `SPK_FLANK` = 1.0 mm, which butts straight onto the dome's rib keep-out. Two screws on one centreline fix x, y and rotation, so no rib is needed. |
| **The stiffening rib ran through the clock** | Short inboard ribs at `y = SPK_Y` were safe until the matrix was centred on the speakers — then `SPK_Y` *was* the matrix mid-height. Four check failures, one rib. Replaced by a second spine below the matrix. |
| **A check can be wrong while the part is right** | A chord instead of a true ellipse distance; one probe near a feature's tip; pad clearance against pixels but not the ribbon. All three passed a green run. When a check passes, ask what it would have to see to fail. |
| **A split can sever a boss from its own floor** | The lap plane sits at mid-thickness; the mic channel floor is exactly that thick. Any boss standing in the channel lands on one half while its floor lands on the other, and prints as a floating island. The *whole* part stays connected, so only a per-half body count finds it. |
| **250.8 wide does not fit a 220 bed, at any angle** | Rotating a D only grows its footprint; the 45° tilt that fits would put supports across the facade. Best of ~40,000 orientations was still 9.2 mm over. Solved by rotating the speakers and lifting the array, not by splitting — the seam logic survives behind `NEEDS_SPLIT`, currently off. |
| **One file must define a thing once** | `gen_front_plate.py` contained the whole build twice; the second copy reassigned `body` and discarded the first. A fix landed on the dead copy, looked applied, and changed nothing. |

### Sourced vs. still guessed

Sourced from datasheets: speaker **50 × 45 × 22**, mic array **110 mm / 33 mm
pitch**, UPS board **60 × 93**, charger **12.6 V 2 A**.

Measured off the actual parts: **speaker side nub 7 mm behind the front face**;
**Flex core 52 × 70 × 20 deep**, **110 mm** over its jack and mic-ribbon
connectors, holes **45 × 63** pitch (from 42 × 60 inside-edge to inside-edge with
2 mm edge-to-hole-outside, which gives Ø3 on both axes — a consistency check that
passed).

Still marked **(?)** and able to move real geometry: the **speaker nub
projection** (4 mm assumed — worth ±4 mm of body width per mm, see the table
above), the **UPS depth with cells fitted** (~24 assumed), the **mic array board
width**, the **diffuser air gap**, and **where the sensor chip sits on your
VL53L0X breakout**.

---

# Dome, bottom plate, knob

## Two rules everything inside obeys

**Every board lands on a plane — built up, not milled in.** The crown is a
cylinder and the walls curve above the springing line, so a PCB laid on either
rocks on two edges and skews whatever connector pokes through.

The obvious fix is a shallow pocket milled into the **inside** (never the outside,
which stays smooth), and that is what this section used to describe. **It was
tried and abandoned.** A pocket in a curved surface is a *lens* — the sliver
between a plane and a cylinder — with a knife edge everywhere the two meet, and
cutting one severed the very bosses that reach up through it. Three parameter
sweeps could not get a watertight mesh out of it.

What the part does instead: **a board's bosses are all built to the same tip
height** — the lowest of its own four local ceilings, less its standoff — so the
four tips are coplanar and the board sits flat on them. The bosses nearer the apex
simply grow by the arch's sag, which is free. Same result as the flat, with *added*
material rather than removed, so there is no lens and no knife edge.

Only the **knob's seating pad** is still a milled pocket
(`enclosure_geom.flat_depth()`), and that one is in the **outer** skin where there
is no boss to sever.

> This mattered far more than the old note assumed. It argued the flat was
> unnecessary because the sag is "only 0.59 mm across the encoder board" — true,
> and irrelevant, because the encoder is centred on the apex, so all four of its
> bosses are at the same |dx| and it sits flat either way. The **ToF** is the board
> that needed it: off-apex, from dx 16.7 to 30.9, where the ceiling drops 2.6 mm
> across its 12.7 mm hole span. Following the arch there tilts it **10.7°** — and
> its pinhole is a *vertical* bore with a 25° cone, so a 10.7° tilt throws half the
> cone into the side of its own hole. The board that most needed to sit flush was
> the one the arch treated worst, and the argument for skipping the flat had been
> made about the other board.

**No screw enters from outside.** Every boss is blind — it stands proud of the
inner surface and its pilot stops `BOSS_MIN_WALL` short of the skin. Screws go in
from inside, towards the shell. The only fasteners visible on the finished
machine are the six that pull the bottom plate up, and they are counterbored
below the feet so it rests on rubber, not steel.

M2.5 self-tappers into printed bosses for the boards; the bottom plate keeps M3
heat-set inserts, because that is the joint opened over and over.

> ### ⚠️ The RTC went to the floor and came back, on the strength of a stale search
> The DS3231 was first placed on the rear wall at (178, 108), where one of its
> four bosses landed **outside the shell** — the arch curves in to a half-width of
> 73 mm by that height and the boss wanted 87. A search over the whole wall then
> reported **no** viable position, and the RTC was moved to the bottom plate.
>
> That search was run against the **old** vent stacks (18 × 24, two of them) and
> the **old** amp position (depth 50). Both moved afterwards and nobody re-ran it.
> Re-run, the wall offers **67 151** viable positions; the best has 9.0 mm
> clearance. A "no solution" result is only as good as the constants it was run
> against, and it rots silently the moment any of them move — there is nothing in
> a negative result that announces it has expired.
>
> **The floor was never a good home anyway**, and it cost two more moves:
> - **(20, 44)** put two of its four bosses 4.5 mm **on top of** the left-hand
>   fixing screws. The position had been searched against floor items and plate
>   edges, and never against the six screws.
> - **(26.3, 43.7)** then buried the **board** 0.9 mm inside the dome's left wall
>   rail, and 1.0 mm into a rear tab. Nothing on the plate could see it: every
>   check on that part compared Ø6 **boss posts**, and the 25.4 mm board sitting
>   on them was never modelled. `RTC_PCB_W` was imported into `gen_bottom_plate.py`
>   and never once referenced.
>
> Two checks came out of it, both in the shared geometry so neither part can
> drift again: `dome_floor_intrusions()` describes everything the dome reaches
> down into the plate's airspace (rails, rear tabs, seating ledge), and the plate
> now checks **board outlines**, not just bosses, against it. Re-running the old
> position reports −1.00 mm and fails.

> ### ⚠️ Three things the dome got wrong, all caught by the mesh check
> - **Bosses grew the wrong way.** They ran in +z, into the rear wall's own
>   material, so each pilot ended up drilled inside solid plastic — a sealed void
>   with no opening. Eleven of them turned up as eleven extra connected bodies
>   with *negative* volume.
> - **Gussets in the wrong axis.** Printed rear-wall-down the vertical axis is
>   DEPTH, so a lug's unsupported face is the one at larger z. The first version
>   built ramps downward in y, where nothing was unsupported, and pushed them into
>   the bottom plate's space at the same time.
> - **Gussets left the building.** Unclamped, the rear-most pair ran from z=61 out
>   to z=73 — through the rear wall and 8.6 mm into open air. The part's bounding
>   box read 72.6 deep against a 64 mm design depth, which is the only reason it
>   surfaced. There is now a containment guard and a bbox assertion, matching the
>   front module's.

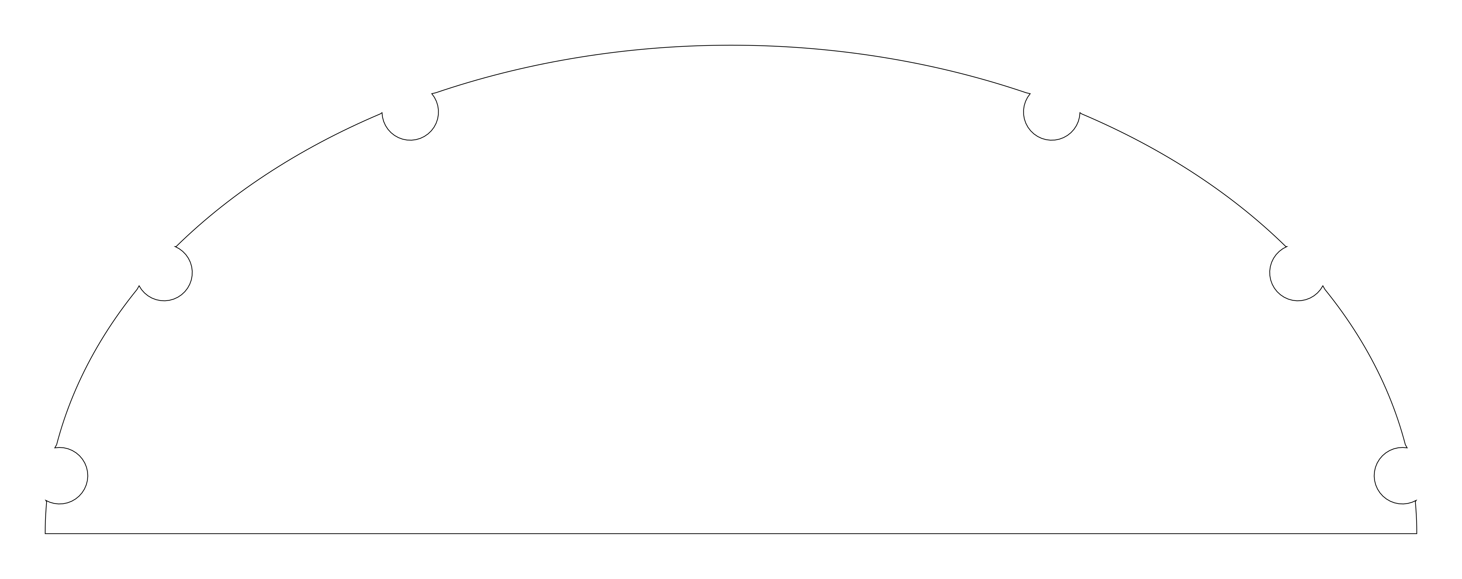
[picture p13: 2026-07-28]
3d-print/diffuser.png

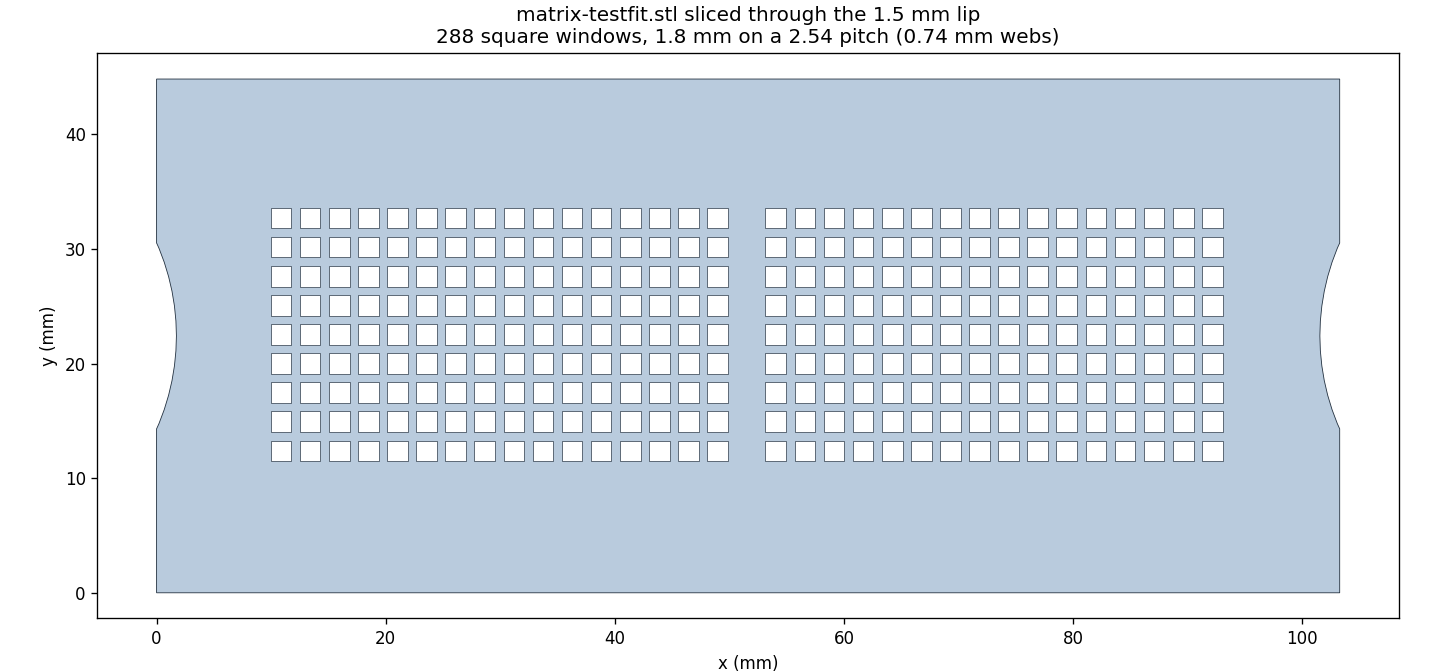
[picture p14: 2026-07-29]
3d-print/models/matrix-windows.png

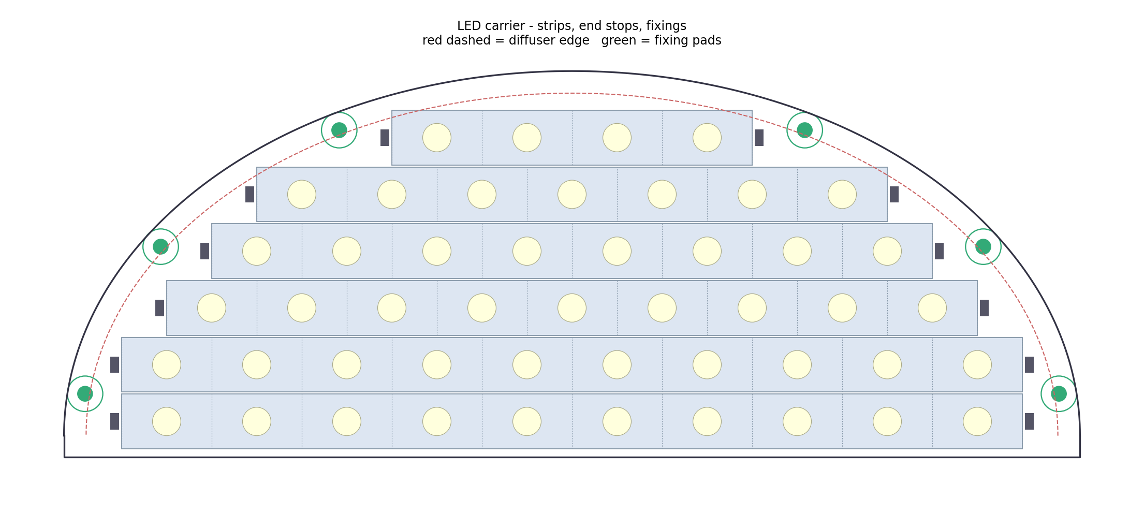
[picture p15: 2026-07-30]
3d-print/led-carrier.png

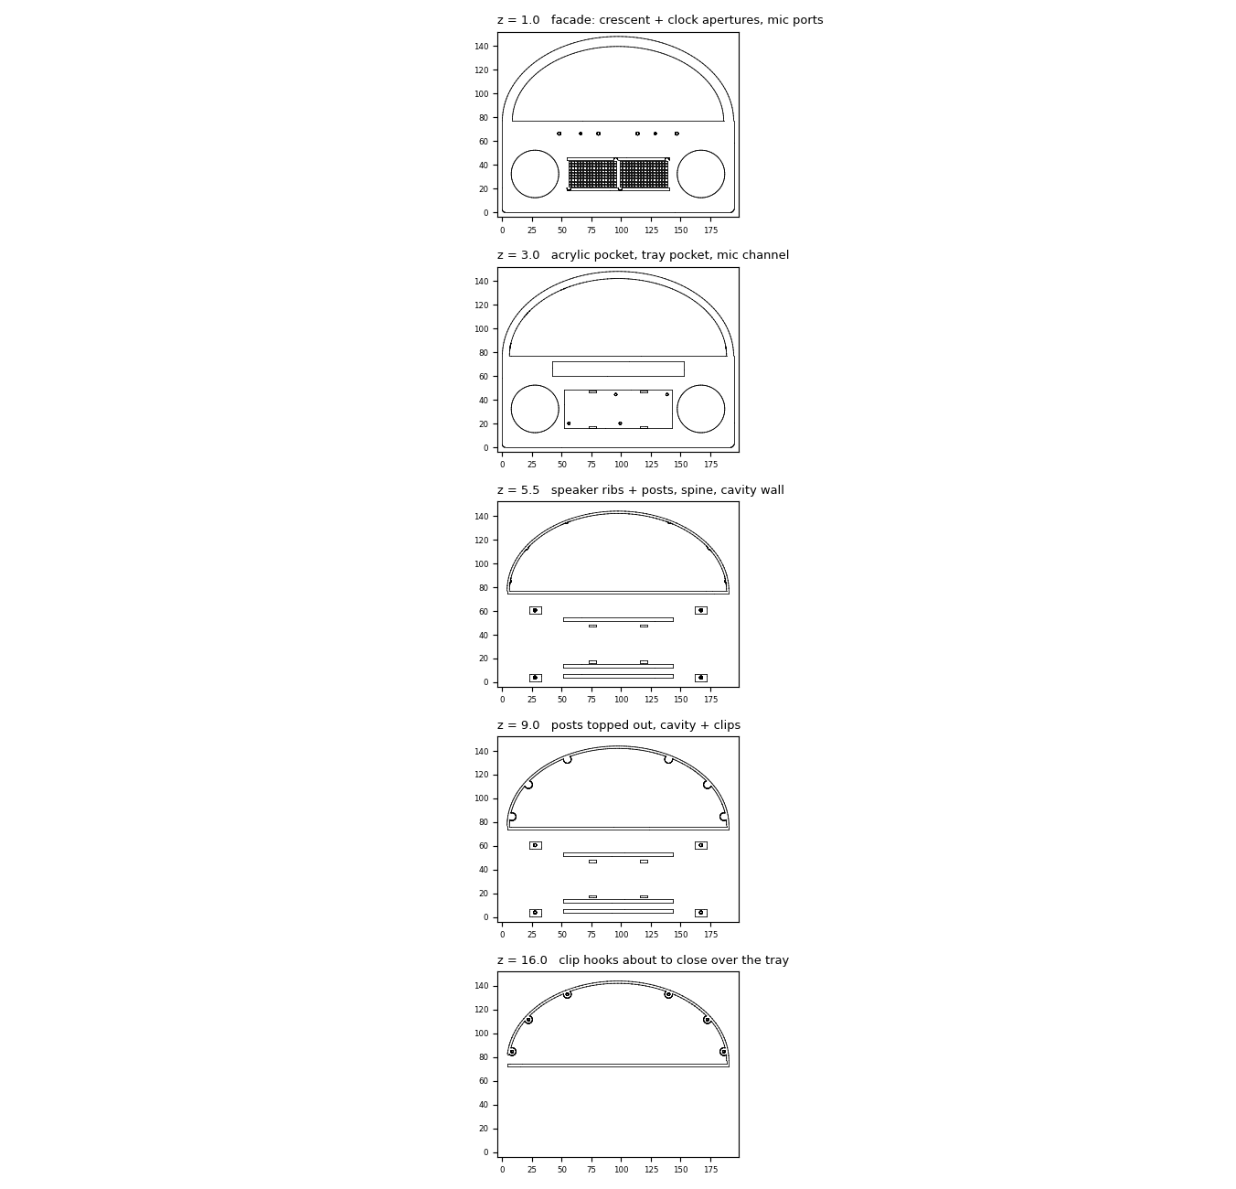
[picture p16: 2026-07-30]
3d-print/models/front-module-sections.png

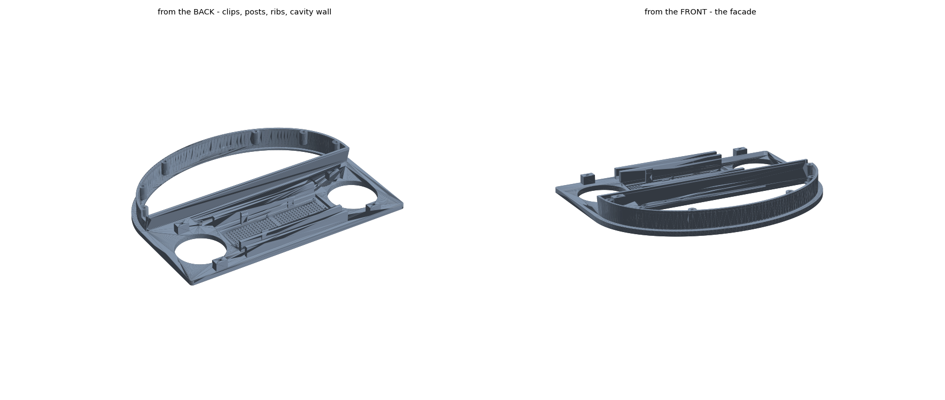
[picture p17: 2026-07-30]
3d-print/models/front-module-3d.png

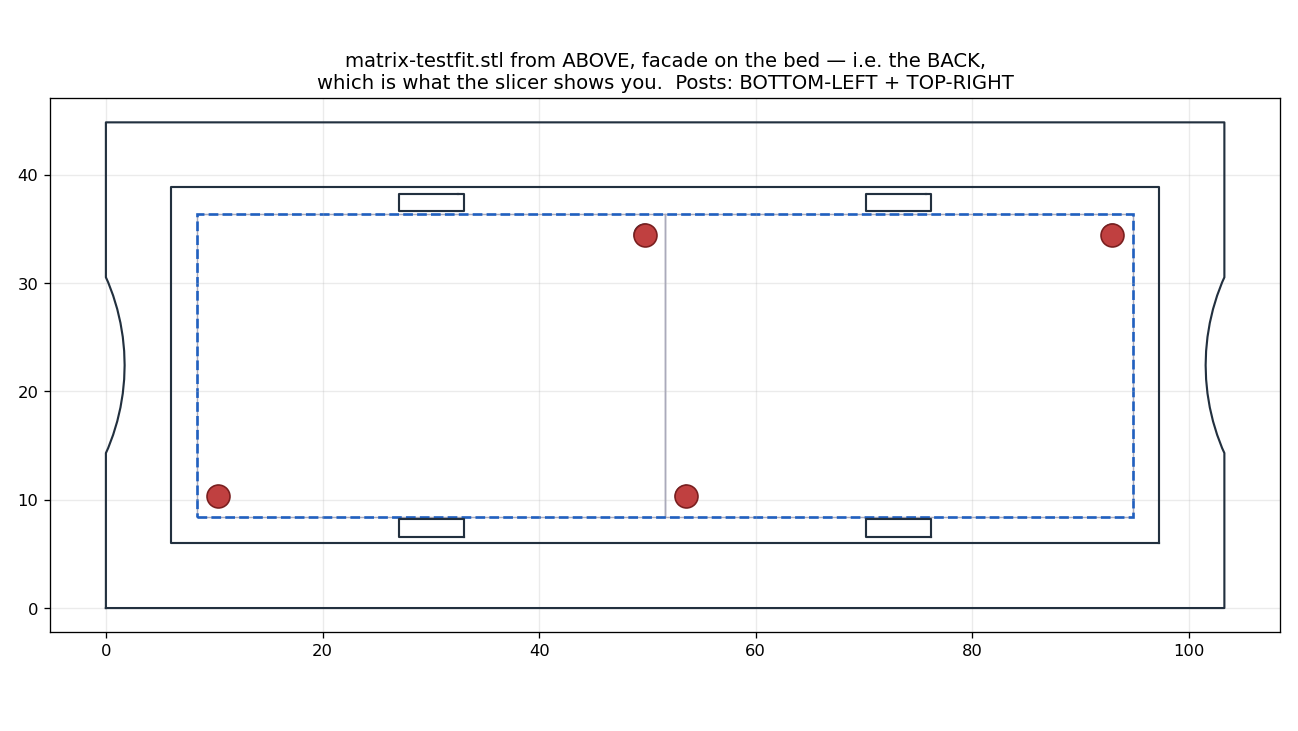
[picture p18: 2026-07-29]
3d-print/models/matrix-posts-backview.png

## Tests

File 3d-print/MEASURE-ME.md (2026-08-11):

# Measure these before you print

> **Prototype 1 was printed with every value below still a guess, and it went
> together.** That is not the same as the guesses being right — it means nothing
> that failed depended on them. Two things follow:
>
> 1. **These are now measurable on the assembled machine**, which is easier than
>    measuring the loose parts this list was written for.
> 2. **They still matter for a reprint or a v2.** A guess that happened to survive
>    one print is not a measurement, and the tolerance it consumed is unknown.
>
> The list stays live and stays enforced: `check_docs.py` asserts it against the
> `(?)` markers in `enclosure_geom.py` in both directions. Tracked as **V3** in
> [`../FUTURE-DEVELOPMENT.md`](../FUTURE-DEVELOPMENT.md).

Every value below is still a **guess** in `enclosure_geom.py`, marked `(?)` at its
declaration. Nothing else is: if a constant is not on this list, it came from a
vendor board file, a datasheet, or something you already measured.

> `check_docs.py` now asserts this list against the code — every `(?)` constant
> must appear here, and nothing here may claim to be unknown once the `(?)` comes
> off. The list drifted badly before that rule existed: it was still asking for
> five hole patterns that Adafruit's own board files had already settled, for
> speaker nubs you had confirmed on a print, and for a socket height belonging to
> a design that was never built.

---

## 1. The one that blocks a print you want to do now

### `MTX_PIN_H` — trimmed header pins on the clock matrix, **assumed 0.8**

How far the pins stand above the board's **LED-side** face after your trim. Sit a
straight edge across them and caliper the standoff, or measure board-face to pin
tip.

It sets the recess depth, because the gutter must swallow the pin and the facade
in front of it must stay ≥ 0.45 mm thick:

| pins measure | gutter | matrix inset |
|---|---|---|
| 0.5 | 0.65 | **1.10** |
| 0.8 *(assumed)* | 0.95 | **1.40** |
| 1.1 | 1.25 | **1.70** |

Shorter trim buys viewing angle directly. The inset is derived, so tell me the
number and everything downstream follows.

**The test coupon checks this for you** — print `matrix-testfit.stl` and see
whether the boards sit flush.

---

## 2. Will not assemble if wrong

### `CLOTH_T` — grille cloth, **one** layer, assumed 0.6

Measure a single layer with calipers, gently: cloth compresses, so don't clamp.
The groove that traps the front module is sized around two thicknesses.

### `INSERT_D` — heat-set insert hole, assumed Ø4.0

For M3 × 5.0 brass inserts. The number that matters is the **hole** the insert
wants, which the insert's own spec gives — usually 0.1–0.2 mm under its knurl.

### `BARREL_NUT_D`, `SW_NUT_D` — across the nuts, both assumed 16.0

**Now load-bearing.** The panel openings were opened up by `PANEL_FIT` (1 mm) after
both came out too tight, so the switch nut has only **1.0 mm** of overlap on its
Ø13 hole at the assumed 16. If it is actually smaller than 15 it pulls through.
Measure this one before you fit the button.

Across the **corners**, not the flats, on the panel nuts for the DC jack and the
UPS button. They set the flat land each one tightens against. The component bodies
are settled (Ø7 and Ø12, from your measurements); the openings cut for them are
those plus `PANEL_FIT`.

### `KNOB_BORE_D` / `KNOB_BORE_F` — encoder shaft, assumed 6.0 with a 4.5 flat

Caliper the D-shaft: full diameter, and across the flat. The bore is only 0.2 mm
over nominal now, so 0.2 mm out here is the difference between a knob that presses
on and one that splits. *(The shaft's LENGTHS are settled — 12 mm above the dome,
top 5 mm D-flatted.)*

---

## 3. Will assemble but won't work properly

### `SPK_BODY_D`, `SPK_GRILLE`, `SPK_BC` — the speaker

Assumed 22.0 deep, 40.0 open cone, 46.0 bolt circle. Depth sets whether the driver
clears the crescent; the bolt circle sets the mounting. *(The nubs themselves are
confirmed — you said they're perfect on a print.)*

### `MIC_PORT_D`, `MIC_PCB_H` — the mic array

Assumed Ø2.5 acoustic port and a 12.0 board width. The board width is not
published anywhere I can find. The port diameter matters for the seal against your
foam tape.

### `DIFF_T` — opal acrylic thickness, assumed 3.0

Whatever you actually buy. The pocket is cut to `DIFF_T + 0.2`.

### `UPS_D` — pack depth with cells in, assumed 24.0

Width and height (60 × 93) are from the DXF and are right. Only the depth is a
guess, and it drives how far the pack stands off the rear wall.

---

## 4. Tune on a test print — don't measure

### `DIFF_GAP` — air gap behind the diffuser, currently 12.0

How far the LEDs sit behind the acrylic. Too close and you see 48 dots; too far and
the crescent goes dim and muddy. This is a *look* you judge by eye, not a
dimension, and it is the biggest single lever on how the crescent reads.

### `SPK_PILOT_D`, `LED_BODY` — 2.5 and 1.6

Pilot for an M3 self-tapper, and the 0603 LED package's long axis. Both only matter
if a fit comes out tight.

---

## 5. Assembly steps the model can't do for you

- **Mic port gaskets.** Thin foam tape between the array and the facade, holes cut
  for the ports. The screw bosses are deliberately short so the board can be pulled
  down onto it.
- **The encoder board goes in one way round.** Four holes on a square pitch and a
  central shaft mean it drops in happily at 180° out. Fit it with the **NeoPixel
  edge toward the FRONT** — the edge with the pixel in line with the two mounting
  holes. Backwards puts the crown's light window at the back of the knob.
- **The matrix pair.** Both boards drop onto their own posts; the clips hook the
  whole stack. If a board won't go on, stop — don't force it.

---

## Settled — do not re-measure

Kept short on purpose. The full reasoning for each lives at its constant.

| | source |
|---|---|
| All five breakout hole patterns (encoder, ToF, lux, RTC, matrix + driver) | Adafruit board files |
| TPA2016 outline **and** its two M2.5 holes at (19.05, 2.54 / 25.40) | `Adafruit TPA2016D2.brd` |
| UPS 3S: 60 × 93, four Ø3.1 on 46 × 86 | your DXF |
| Flex core: 52 × 70 × 20, four Ø3.0 on 63 × 45 | you measured |
| Matrix stack height 7.0, mic hole edges at 22.0 | you measured |
| Panel holes: barrel Ø7, rotary Ø7, button Ø12 | you measured |
| Speaker nubs — projection, width, height, screw | confirmed on your print |
| NeoPixel at board (12.7, 22.86) — in line with the top screw holes | #4991 fab print |

---

## When you have the numbers

Give them to me in any form — a list, a photo of your notes, whatever. I'll update
`enclosure_geom.py`, take the `(?)` off, re-run everything, and tell you which
clearances moved.

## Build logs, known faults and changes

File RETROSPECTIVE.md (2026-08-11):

# RETROSPECTIVE — building v1

**Prototype 1 is built.** Designed, printed, wired, assembled, in service on the
bedside table. This document is what building it taught, distilled from the
session journals and design notes that were kept during development.

It is **history, not current state.** For what the machine is, read
[`HARDWARE.md`](HARDWARE.md); for how the firmware is arranged,
[`CLAUDE.md`](CLAUDE.md); for what is still to do,
[`FUTURE-DEVELOPMENT.md`](FUTURE-DEVELOPMENT.md).

> The full session-by-session build journal (~1400 lines) and the superseded
> pre-print checklists are **not** on `main`. They live on the **v1 release
> branch**, which is the point of that branch — the raw material is preserved in
> git, and `main` carries only the conclusions.

---

# 1. The one lesson

Almost every bug recorded during the enclosure build was **a check that passed
for the wrong reason.** Not a missing check — a passing one. The geometry was
covered by hundreds of assertions and the parts were still wrong, because *an
assertion written around the answer you expect will confirm that answer
regardless of what the part does.*

The failure modes below all instance it. They are worth reading as a list because
they recur, and because almost none of them are specific to CAD.

### The check measured a quantity that could not fail

`chk("ToF hole pitch fits its own board", TOF_PCB_D - TOF_HOLE_P)` — with a corner
inset, that comparison is *arithmetically incapable* of going negative. Same
shape: `(MTX_INSET - MTX_GUTTER_D) - MTX_FACADE_MIN` reported `ok 0.00` from the
moment `MTX_INSET` was defined as the sum of those two terms. It was subtracting a
number from itself.

> **Tell:** a check reporting exactly `0.00`, or the same round margin, every run.
> Derive a value and then assert on it and you have written a tautology.
>
> **Fix:** assert against the *built artifact*, not the formula. Walk the solid
> and find where material actually stops.

### The check measured the right thing on the wrong axis

Every clearance table worked **in plan** (x against y), because that is where
crowding usually is. This is a shallow box with parts hung off both faces —
speakers off the front, battery off the back. They overlapped in x *and* in y;
**depth was the only thing keeping them apart, and nothing looked at depth.** The
model claimed 11.5 mm of clear air while the speakers were 3 mm inside the
battery. Found by hand, on the bench, by fitting it.

Same class: the crescent solver measured horizontally (chord) and vertically
(apex) on an **ellipse**, where the binding case is diagonal — so a pixel 0.58 mm
outside the diffuser read as clear on every check.

### The tolerance absorbed the defect

`check_assembly` reported 27.2 mm³ of dome-inside-plate and **passed**, because the
threshold was `overlap < 50.0 mm³`. That tolerance existed for a real reason: two
touching parts produce many zero-volume coplanar fragments, and a raw "any
intersection" test screams on every run.

> **Narrower than "tolerances are bad":** a tolerance sized to absorb one
> phenomenon will absorb anything else the same size. Apply it to a quantity only
> that phenomenon can produce. Contact is flat — many pieces, none with volume. A
> collision is one lump *with* volume. Judge the largest piece.

### The check read the wrong variable, or the wrong frame

A gutter probe read `body` instead of `part_body`. Those differ by the STL export
shift `(-3.6, -4.0)`, so it measured sideways into solid lip and cheerfully
reported full clearance — while a probe three lines above, using the right one,
said the gutter was open. **Two measurements of the same point disagreeing is the
only reason it was noticed.**

### A default masqueraded as a measurement

`check_stability.py` reported a scary 85 gf to lift the front feet by pressing
"the front-panel button at z = 100". There is no front-panel button. The height
came from `getattr(g, "SW_Y", 100.0)` firing its fallback silently, because the
real constant is `SW_WALL_Y`. The script had invented its own load case.

> `getattr(obj, name, default)` on a constant you believe exists is a silent
> rename detector that never fires.

### The check was never running at all

The dome's entire mesh validation — watertightness, connected-body count, board
envelopes — sat inside `except ImportError: say("validate skipped: no trimesh")`
wrapped around ~180 lines. trimesh was installed and fine. **scipy** was missing,
which `trimesh.split()` needs. Every run printed "no trimesh" and skipped
everything; removing the blanket handler immediately surfaced a *second* missing
dependency, rtree.

> **A blanket `except ImportError` around a large block does not just report the
> wrong cause — it silently skips work nobody chose to skip.** A missing
> dependency is a failure, not a shrug.

### The check validated something that never reached disk

`gen_front_plate.py` kept its own `base` pointing at the script directory. When
solids moved to `models/`, every other generator followed and that one did not. It
wrote `front-module.stl` beside the code while `models/front-module.stl` sat three
hours stale. **Every check passed the whole time** — all validating a solid in
memory that was never the file anyone would print. `verify_exports.py` exists
because of this: it re-runs each generator, reads back what was written, compares.

> Checks existed for geometry, for prose, and for drawings. The last link — model
> to file — was the one nobody watched, and the only one where being wrong means
> printing the wrong part.

### The check encoded a decision that later turned out wrong

An assertion demanded "exactly 2 separate tabs per side wall". Printed rear-wall
down, two separate shelves leave an unsupportable island between them; one
continuous rail is strictly better and needs no support at all. The check had to
be rewritten to assert the opposite.

> A check is not automatically right because it is automated. It is an opinion
> with a test attached.

---

# 2. Lessons that outlived the part

**Interference lives in the gap between parts.** The dome checked its own
features. The front module checked its own. Nothing put two parts in the same
space, so a mirrored bottom plate went unnoticed for weeks and the front module
reached 19 mm into the dome's interior unchallenged.

**Comparing coordinates from two frames is not a comparison — and take the
determinant.** The bottom plate was a mirror image, defended twice with a table of
"evidence" showing matching coordinates. The table read 45.0 from one part and
45.0 from the other without noticing **one was a depth and the other a height**.
The implied mapping `(x,y,z) → (x,z,y)` has determinant −1: a reflection, not
something you can do to a printed part. An axis swap looks exactly like a rotation
until you take the determinant.

**A negative result carries no expiry date.** "No viable position on the rear
wall" was believed for weeks. The search had run against the *old* vent stacks and
the *old* amp depth and was never re-run after either moved. Re-run, it found
67,151 positions. Nothing about a cached negative announces that its inputs moved.

**Stop checking one pair at a time.** Three separate bugs on the bottom plate had
the identical shape: A was checked against B and C, and nobody compared it to D.
The plate now enumerates every feature with a footprint — 22 features, 165 pairs —
so a new feature is checked against everything else for free. (It also has to know
about z: a planar check on a part with features on both faces reports collisions
that do not exist, and **a check that cries wolf is worse than no check, because
you start ignoring it.**)

**Look for the vendor's board file before reaching for the calipers.** Three times
a published number beat a measured or inferred one. The encoder, ToF and BH1750
each carried an invented *two*-hole pitch marked `(?) MEASURE`; all three have
**four** holes and all three vendors publish the Eagle file saying so. Fixing it
exposed two collisions the old model could not see — bosses 0.59 mm apart, and a
10.7° tilt on the ToF.

**The bosses are the binding constraint, not the board.** 0.59 mm between two Ø6
posts is not an intersection, so the "bosses do not intersect" check passed it —
and 0.59 mm of filament between two posts prints as one blob.

**Prose has no checks.** Every rework left documents describing a machine that no
longer existed; the 258-wide split enclosure was still documented as current three
revisions after it stopped being built. `3d-print/check_docs.py` exists for this
and is still live — it allows history explicitly, so a stale-value rule only fires
outside a line that marks itself historical ("used to", "no longer", …). Keep
using those markers.

**Measure the thing that has to fit, not the thing you are thinking about.** Every
early crescent layout measured the **LED body**. What has to fit the cavity is the
**ribbon** — a cut segment of n pixels is `n × pitch`, not `(n−1) ×`, because the
cut lines sit half a pitch outboard of the end LEDs. That cost three pixels
(48 → 45) until the rows were allowed to butt at 10.4 mm pitch, which recovered
them without the 6 mm of extra height raising `CROWN_K` would have cost.

**An argument for skipping something is only as good as the case it was made
about.** The note arguing the crown flat was unnecessary had measured the
**encoder** — centred on the apex, flat either way. The ToF is off the apex and
without the flat would have tilted 10.7°, aiming half its FoV cone into the side
of its own pinhole.

---

# 3. Physical facts worth not rediscovering

- **A snap-fit's free length is squared.** Peak strain is `1.5·t·y/L²`. The matrix
  clip was 2.2 thick, had to move 1.2, and was rooted 2.2 mm below its hook:
  **82 % strain against ~2 % for PLA.** It would have shattered, not flexed — and
  every check in that file was about *clearance*, which a clip that cannot bend
  passes perfectly. Rerooted to grip the whole stack: 9.3 mm beam, 1.39 %.
- **The component size is not the hole size.** Calipered dimensions were being cut
  as the openings themselves. A printed hole comes out under size anyway
  (elephant's foot, first-layer squish, perimeter compensation), so nominal is the
  worst case, not the average. `PANEL_FIT = 1.0` separates measurement from
  opening.
- **Mesh degeneracy has three reliable causes**, each producing a valid solid and
  a broken exported surface: unioning parts that share a face exactly; tangency (a
  buttress exactly as wide as the boss it meets); and coplanar caps. The fix is
  always the same — overlap into material by a fraction of a millimetre rather
  than meeting it exactly. **Union order decides which side of a coincident plane
  a fragment lands on**, so adding unrelated geometry elsewhere can make a latent
  one appear.
- **`connected bodies == 1` does not catch a floating tip** — a cone tapering to a
  point in mid-air is still joined to the shaft above it.
- **Print orientation reassigns the axes.** Printed rear-wall-down, the vertical
  axis is *depth* and +z is *down*. Gussets ramped in the wrong axis, cylinders
  extruded along the wrong axis, and a stability script reading raw z as depth all
  trace to this.
- **Transient current is not average current.** The brownout that still constrains
  this machine happens at ~3.7 A of a 5 A budget. Headroom on paper says nothing
  about the step. See [`FUTURE-DEVELOPMENT.md`](FUTURE-DEVELOPMENT.md) H1.

---

# 4. What changed from the original design, and why

Design-phase notes and early conversation memory disagreed with the code often
enough that the drift was tracked deliberately. Every row here is **settled** —
this table exists so a dead idea can be recognised if it resurfaces.

| Topic | Originally | Built as | Why |
|---|---|---|---|
| **Depth** | 64 mm | **79 mm** | The speakers were inside the battery. Nothing checked the depth axis. |
| **Body width** | 258 mm, front module split for the bed | **202 mm, both parts whole** | Fits a 220 bed without splitting. |
| **Crescent shape** | half **circle**, diffuser R117 over an R96 LED field with a 21 mm unlit fade band | half **ellipse** 89 × 62.7 (`CROWN_K` 0.74), **the LED field IS the diffuser** | No fade band needed once the field and the diffuser coincide. |
| **Crescent pixels** | 45 | **48**, rows `{10,10,9,8,7,4}` | Rows butt at 10.4 mm pitch instead of a 1 mm gap — recovers 3 px without +6 mm of height. |
| **LED strip** | SK6812 **144/m** via an **XL6009 boost converter** | SK6812 **60/m, 6 cut segments**, straight off the UPS 5 V rail | No boost converter required. |
| **Battery** | open — LiPo + USB-C candidate, Qi2 already dropped | **Waveshare UPS 3S** (3× 18650), INA219 monitoring | Also made the machine *harder* to tip: mass low down buys more restoring moment than its rearward COM shift costs. |
| **Charge input** | USB-C | **DC barrel jack, 12.6 V 2 A** | The only USB-C on the build is the XIAO's internal flashing port. |
| **Printed parts** | 4 (dome, front module, bottom plate, knob) | **7** — plus an LED carrier and a laser-cut notched acrylic diffuser | The strip needed a controlled standoff across a 185 mm span. |
| **MCU** | XIAO ESP32-S3 **Plus** | Either; standard **XIAO ESP32-S3 confirmed drop-in** | `board: esp32-s3-devkitc-1`, 8 MB flash. |
| **ToF sensor** | part of the sensor stack, for a touchless *wake* gesture | **kept, smaller role** — pre-lights the knob NeoPixel only | Touchless wake was never implemented. See FUTURE F5. |
| **SHT40 temp/hum** | in the planned sensor stack | **removed** | Dropped from the design entirely. |
| **Front ends** | HA + web server + a standalone PWA | **HA + embedded web server** | The PWA was removed. |
| **Media storage** | SD card | **flashed to ESP or streamed from HA** | ESPHome's speaker/mixer pipeline has no SD media source. |
| **Matrix mounting** | press-in backpack scheme | **clips gripping the whole stack** | The press-in scheme was never built; the first clip design was unbuildable in PLA (see §3). |

**Working principles from that era that held up:** search project history before
reasoning from memory on this hardware; the **tested D4/D5 audio-I2C mapping is
the source of truth**, not schematic-derived guesses; bench-first before
soldering.

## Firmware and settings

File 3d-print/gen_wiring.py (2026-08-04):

#!/usr/bin/env python3
"""SHEET 3 of 3 -- sensor chain, power and wire routing.

Everything on this sheet comes from HARDWARE.md: the I2C address map, the pin
map, the bus tuning, and the amplifier cautions. It is a WIRING sheet, not a
schematic -- it says what connects to what, in what physical order, and where
each board actually sits inside the enclosure.

Three blocks:
  * I2C DAISY CHAIN  -- one shared bus, in the order the STEMMA QT cables run
  * DIRECT GPIO      -- the four I2S lines, the LED data line, the touch pad
  * POWER            -- barrel jack -> UPS 3S -> 5 V rail -> loads

    python3 gen_wiring.py
    rsvg-convert -b white -z 2 enclosure-wiring.svg -o enclosure-wiring.png
"""
import os

from drawlib import *
from enclosure_geom import *

SHEET_W, SHEET_H = 1189.0, 650.0
MARGIN = 15.0

BW, BH_, GAPX, GAPY = 96.0, 30.0, 122.0, 56.0     # device box grid

# The chain, in PHYSICAL routing order -- start at the Flex (floor, right
# rear), across the floor, up the rear wall, over the crown, down into the
# front module. Keeping it in this order is what keeps the cable short.
#   (label, address, where it lives, status)
# >>> THE TWO THAT MOVE ARE DERIVED, NOT RETYPED. This table had the RTC on the
# >>> rear wall while it was on the bottom plate, and STILL has to be told the amp
# >>> is on the floor -- it said "rear wall, above the UPS" long after the amp
# >>> moved down. A hand-typed location is a copy of a fact, and copies rot: the
# >>> RTC's said-vs-actual disagreed for the whole time it was on the plate, which
# >>> is precisely why its standoffs were unrecognisable.
_RTC_WHERE = (f"bottom plate ({RTC_X:g},{RTC_DEPTH:g})" if RTC_ON_FLOOR
              else f"rear wall ({RTC_WALL_X:g},{RTC_WALL_Y:g}), above the Flex")
_AMP_WHERE = f"bottom plate, floor (x={AMP_X:g}, depth={AMP_DEPTH:g})"
CHAIN = [
    ("DS3231 RTC",      "0x68", _RTC_WHERE,                 "live"),
    ("INA219",          "0x41?", "on the UPS 3S board",     "addr unconfirmed"),
    ("TPA2016 amp",     "0x58", _AMP_WHERE,                 "live"),
    ("BH1750 lux",      "0x23", "rear wall, light pipe",    "live"),
    ("seesaw encoder",  "0x36", "crown, under the knob",    "live"),
    ("VL53L0X ToF",     "0x29", "crown, right of the knob", "live"),
    ("IS31FL3731 #1",   "0x74", "front module, left panel", "live"),
    ("IS31FL3731 #2",   "0x75", "front module, right panel", "ADDR jumper moved"),
]

GPIO = [
    ("GPIO5  / D4", "I2C SDA", "shared bus - every device below"),
    ("GPIO6  / D5", "I2C SCL", "shared bus - 100 kHz, 1 ms timeout"),
    ("GPIO1  / D0", "SK6812 data", f"{CRES_PX} px crescent, front module"),
    ("GPIO4  / D3", "touch L + R", "TOUCH4 - BOTH shoulder pads, one net"),
    ("GPIO2  / D1", "(reserved)", "TOUCH2 - free, to split the pads later"),
    ("GPIO7  / D8", "I2S WS", "ReSpeaker Flex (fixed)"),
    ("GPIO8  / D9", "I2S BCLK", "ReSpeaker Flex (fixed)"),
    ("GPIO43 / D6", "I2S mic DIN", "ReSpeaker Flex (fixed)"),
    ("GPIO44 / D7", "I2S spk DOUT", "ReSpeaker Flex (fixed)"),
]


def box(x, y, w, h, title, sub="", note="", cls="obj"):
    o = [rect(x, y, w, h, cls, 1.5), txt(x + 4, y + 8.5, title, "lbl")]
    if sub:
        o.append(txt(x + w - 4, y + 8.5, sub, "dtx", "end"))
    if note:
        o.append(txt(x + 4, y + 16.5, note, "note"))
    return o


def hlink(x0, x1, y, label=""):
    o = [f'<line class="dim" x1="{n(x0)}" y1="{n(y)}" x2="{n(x1)}" y2="{n(y)}" '
         f'marker-end="url(#arw)"/>']
    if label:
        o.append(txt((x0 + x1)/2, y - 2, label, "dtx", "middle"))
    return o


def vlink(x, y0, y1, label=""):
    o = [f'<line class="dim" x1="{n(x)}" y1="{n(y0)}" x2="{n(x)}" y2="{n(y1)}" '
         f'marker-end="url(#arw)"/>']
    if label:
        o.append(txt(x + 2, (y0 + y1)/2, label, "dtx"))
    return o


# ------------------------------------------------------------ I2C chain
def i2c_block():
    o = [txt(0, -26, "I2C DAISY CHAIN", "blk"),
         txt(0, -16, "one shared bus on GPIO5/6 - STEMMA QT, in physical "
                     "routing order", "lbl")]
    # source: XIAO -> Flex
    o += box(0, 0, BW, BH_, "XIAO ESP32-S3", "", "D4 SDA / D5 SCL")
    o += hlink(BW, BW + 26, BH_/2, "hdrs")
    o += box(BW + 26, 0, BW, BH_ + 10, "ReSpeaker Flex", "",
             "AIC3104  0x18")
    o.append(txt(BW + 30, 34.5, "XVF3800  0x2C", "note"))
    o.append(txt(BW + 30, BH_ + 18, "timing-sensitive - see note b", "dtx"))
    o += hlink(2*BW + 26, 2*BW + 52, BH_/2, "QT")

    # the chain snakes: 3 across, then down, then 3 back, etc.
    per_row = 3
    x0 = 2*BW + 52
    for i, (name, addr, loc, status) in enumerate(CHAIN):
        row, col = divmod(i, per_row)
        col = col if row % 2 == 0 else (per_row - 1 - col)
        x = x0 + col * GAPX
        y = row * GAPY
        cls = "hid" if "PLANNED" in status else "obj"
        o += box(x, y, BW, BH_, name, addr, loc, cls)
        if status not in ("live",):
            o.append(txt(x + 4, y + 24, status, "dtx"))
        # link to the next
        if i < len(CHAIN) - 1:
            nrow, ncol = divmod(i + 1, per_row)
            ncol = ncol if nrow % 2 == 0 else (per_row - 1 - ncol)
            nx = x0 + ncol * GAPX
            ny = nrow * GAPY
            if nrow == row:
                if nx > x:
                    o += hlink(x + BW, nx, y + BH_/2)
                else:
                    o += hlink(x, nx + BW, y + BH_/2)
            else:
                o += vlink(x + BW/2, y + BH_, ny)
    return o


# ---------------------------------------------------------- direct GPIO
def gpio_block():
    o = [txt(0, -26, "DIRECT GPIO", "blk"),
         txt(0, -16, "everything that is not on the I2C bus", "lbl")]
    for i, (pin, fn, dest) in enumerate(GPIO):
        y = i * 11
        o.append(txt(0, y, pin, "lbl"))
        o.append(txt(58, y, fn, "note"))
        o.append(txt(130, y, dest, "note"))
        o.append(line(0, y + 2.4, 300, y + 2.4, "ext"))
    return o


# --------------------------------------------------------------- power
def power_block():
    o = [txt(0, -26, "POWER", "blk"),
         txt(0, -16, "one 5 V / 5 A rail off the UPS", "lbl")]
    o += box(0, 0, 84, 24, "DC barrel jack", "", "rear wall, centred")
    o += hlink(84, 110, 12)
    o += box(110, 0, 84, 24, "UPS 3S", "", "3x 18650, upright")
    o += hlink(194, 220, 12, "5V")
    o += box(220, 0, 84, 24, "5 V / 5 A rail", "", "")
    loads = [("SK6812 crescent", "~1.9 A capped"),
             ("TPA2016 + 2x 4R", "~1.3 A"),
             ("Flex + XIAO + sensors", "~0.5 A")]
    for i, (name, amps) in enumerate(loads):
        y = 44 + i * 26
        o += vlink(262, 24 if i == 0 else y - 26 + 24, y) if i == 0 else []
        o += box(220, y, 128, 22, name, amps, "")
        o.append(line(262, 24 + (i * 26), 262, y, "dim"))
    o.append(txt(0, 130, f"budget  ~3.7 A of 5 A  (crescent hard-capped at 65% "
                         "white in firmware)", "note"))
    return o


# ------------------------------------------------- where each board sits
def location_block():
    """Front outline + side outline with the chain numbers on them."""
    o = [txt(0, -26, "WHERE THEY SIT", "blk"),
         txt(0, -16, "numbers match the chain above", "lbl")]
    sc = 0.62
    fo = [path(d_profile(0, R_BOT), "obj"),
          # semi_e, NOT semi: the crown is a flattened half-ELLIPSE (CROWN_K).
          # This drew a true semicircle of radius CRES_R, which made the
          # crescent on this sheet 26 mm taller than the one on sheets 1 and 2.
          semi_e(W/2, fy(CRES_Y), CRES_R, CRES_RY, "hid"),
          rect(W/2-CLK_W/2, fy(CLK_Y+CLK_H/2), CLK_W, CLK_H, "hid", 1)]
    for sx in (SPK_X, W-SPK_X):
        fo.append(rect(sx-SPK_BODY_W/2, fy(SPK_Y1), SPK_BODY_W, SPK_BODY_H, "hid", 2))
    for mx in mic_x():
        fo.append(circ(mx, fy(MIC_Y), MIC_PORT_D, "hid"))
    # balloons: matrices on the front module
    fo.append(balloon(W/2 - 30, fy(CLK_Y), 7, W/2 - 74, fy(CLK_Y) - 30))
    fo.append(balloon(W/2 + 30, fy(CLK_Y), 8, W/2 + 74, fy(CLK_Y) - 30))
    o.append(f'<g transform="scale({n(sc)})">' + "\n".join(fo) + '</g>')
    o.append(txt(W*sc/2, H*sc + 12, "FRONT (front module)", "lbl", "middle"))

    xs = W*sc + 40
    so = [path(rrect(0, 0, D, H, R_SIDE, R_SIDE, R_SIDE_B, R_SIDE_B), "obj"),
          rect(D - WALL - UPS_D, fy(BP_T + UPS_H), UPS_D, UPS_H, "hid"),
          rect(LIP_T, fy(H - REVEAL), FP_T, H - REVEAL - BP_T, "hid")]
    so.append(balloon(D - WALL, fy(AMP_WALL_Y), 3, D + 34, fy(AMP_WALL_Y) - 16))
    so.append(balloon(D - WALL, fy(LP_Y), 4, D + 34, fy(LP_Y) + 14))
    so.append(balloon(D - ENC_Y, fy(H) + 3, 5, D + 34, fy(H) - 22))
    so.append(balloon(D - TOF_Y, fy(H) + 3, 6, -30, fy(H) - 22))
    so.append(balloon(D - WALL - UPS_D/2, fy(BP_T + UPS_H/2), 2,
                      -30, fy(BP_T + UPS_H/2)))
    so.append(balloon(D - 14, fy(BP_T + 6), 1, -30, fy(BP_T + 20)))
    o.append(f'<g transform="translate({n(xs)},0) scale({n(sc)})">'
             + "\n".join(so) + '</g>')
    o.append(txt(xs + D*sc/2, H*sc + 12, "RIGHT SIDE", "lbl", "middle"))
    return o


# ------------------------------------------------------- sheet assembly
def build():
    o = [svg_header(SHEET_W, SHEET_H), sheet_frame(SHEET_W, SHEET_H, MARGIN)]
    o.append(g("I2C-CHAIN", i2c_block(), 60.0, 70.0))
    o.append(g("DIRECT-GPIO", gpio_block(), 60.0, 300.0))
    o.append(g("POWER", power_block(), 420.0, 300.0))
    o.append(g("LOCATIONS", location_block(), 790.0, 300.0))

    o.append(g("CHAIN-LEGEND", legend(
        [(i + 1, f"{name}   {addr}   {loc}") for i, (name, addr, loc, st)
         in enumerate(CHAIN)],
        "CHAIN KEY  -  balloons on WHERE THEY SIT"), 790.0, 130.0))

    L, ln = [], [0.0]

    def nl(s, cls="note", step=4.7):
        L.append(txt(0, ln[0], s, cls))
        ln[0] += step

    nl("NOTES  (all from HARDWARE.md - that file is authoritative)", "lbl", 6.6)
    nl("a   ONE shared I2C bus on GPIO5/D4 (SDA) and GPIO6/D5 (SCL). D4/D5 is "
       "the tested mapping - do NOT 'correct' it from the schematic.")
    nl("b   BUS RUNS AT 100 kHz WITH A 1 ms TIMEOUT, deliberately. The STEMMA "
       "chain's cable capacitance and pull-ups were starving the")
    nl("    timing-sensitive XVF3800; the slow edges tolerate it and the "
       "timeout lets the XVF3800 clock-stretch while its firmware boots.")
    nl("    Chain order on this sheet is chosen to keep the cable SHORT for "
       "that reason. If it is still flaky, drop toward 10 kHz.")
    nl("c   BRIDGE-TIED AMP OUTPUTS. Every TPA2016 output terminal swings; "
       "there is no output ground. Do NOT common the two speakers'")
    nl("    negative leads and do NOT tie any output to GND - either shorts "
       "half a bridge and can kill the amp.")
    nl("d   The TPA2016's AGC is deliberately OFF (compression 1:1). An active "
       "compressor downstream of the DAC makes the echo path")
    nl("    time-varying and breaks the XVF3800's AEC. It has no NVM, so the "
       "custom component rewrites its config at every boot.")
    nl("e   The second matrix needs its ADDR jumper moved off 0x74 (0x75 / "
       "0x76 / 0x77) and matrix_address_2 set to match.")
    nl("f   VL53L0X is drawn hidden: it is on the bus plan and in the address "
       "map but has NO ESPHome entity yet.")
    nl("g   INA219 address 0x41 is a PLACEHOLDER. Waveshare boards usually sit "
       "at 0x40-0x43; confirm against the boot I2C scan, and if the")
    nl("    readings are nonsense the part may be an INA226 (swap the platform "
       "in packages/hw/power.yaml).")
    nl("h   BOTH TOUCH PADS SHARE GPIO4/D3. Self-capacitance sensing measures "
       "the whole electrode net, so two pads on one net behave as")
    nl("    one electrode split in two - touching either half gives the same "
       "delta. One binary sensor, one threshold, no OR logic.")
    nl("    JOIN THE LEADS AT THE MCU, NOT ACROSS THE CROWN. Each lead drops "
       "down the inside of its own flank to the floor and they meet")
    nl("    at the XIAO. Same wire count either way, and it keeps a ~200 mm "
       "antenna out of the crown, where the SK6812 data line, the")
    nl("    I2S lines and the STEMMA chain all run. A wire taken straight "
       "across the crown would pick that up straight into the sensor.")
    nl("    Cost of sharing: baseline capacitance roughly doubles while the "
       "finger delta does not, so relative sensitivity drops (still")
    nl("    usable), and a side-to-side mismatch cannot be trimmed with "
       "per-pad thresholds. GPIO2/D1 (TOUCH2) is kept free as the escape")
    nl("    hatch - splitting to two channels is one wire at the MCU plus a "
       "few lines of YAML. Calibrate with esp32_touch: setup_mode: true.")
    nl("i   Matrix is TWO IS31FL3731 panels on the STEMMA chain, 0x74 and "
       "0x75 - move the second board's ADDR jumper off 0x74. Bring")
    nl("    one panel up first (matrix_panels: 1); the second address is "
       "never touched until then, so an unwired board is harmless.")
    o.append(g("NOTES", L, 60.0, 430.0))

    o.append(title_block(
        936.0, 520.0, 238.0, 90.0,
        "SOUND MACHINE - WIRING", "sensor chain / power / routing",
        [("SOURCE HARDWARE.md", "BUS"),
         ("UNITS mm   locations NTS", "one I2C bus, 100 kHz, 1 ms timeout"),
         ("GENERATED BY 3d-print/gen_wiring.py", "SHEET 3 of 3"),
         ("REFERENCE ONLY - not a released drawing", "REV A")], 3))

    o.append("</svg>")
    return "\n".join(o)


if __name__ == "__main__":
    base = os.path.dirname(os.path.abspath(__file__))
    out = os.path.join(base, "enclosure-wiring.svg")
    open(out, "w").write(build())
    print(f"wrote {out}")
    print(f"\nI2C chain ({len(CHAIN)} devices after the Flex), routing order:")
    print("  XIAO -> ReSpeaker Flex [AIC3104 0x18, XVF3800 0x2C]")
    for i, (name, addr, loc, status) in enumerate(CHAIN):
        print(f"  {i+1}. {name:<18} {addr:<6} {loc:<26} {status}")
    addrs = ["0x18", "0x2C"] + [c[1].rstrip("?") for c in CHAIN]
    dupes = {a for a in addrs if addrs.count(a) > 1}
    print(f"\n{len(addrs)} addresses, "
          + ("no collisions" if not dupes else f"COLLISION: {dupes}"))

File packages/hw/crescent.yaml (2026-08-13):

# =====================================================================
# HARDWARE: SK6812 crescent LED strip (RMT, GRBW)  [layer: hw]
#
# The strip itself, its geometry, and the effects that need to know that
# geometry. Nothing here decides when the light should be on - that is
# behavior/light.yaml, working through api/light.yaml.
#
# >>> THE PIXEL COUNT AND ROW LAYOUT ARE NOT SETTINGS. They are DERIVED from the
# >>> enclosure: 3d-print/enclosure_geom.py is the source of truth and this file
# >>> carries a copy of its output. Change the crescent, re-run gen_drawing.py,
# >>> re-sync BOTH values here, and run 3d-print/check_docs.py - which fails the
# >>> build if they drift. Get this wrong and the firmware addresses pixels that
# >>> are not physically there.
#
# The three custom effects live here, because two of them paint by POSITION and
# so are inseparable from the row layout above them - Circadian Sunrise per row,
# Rainbow Arch per pixel-radius. (Colour Cycle needs no geometry; it is here
# only because effects must be declared on the light they run on.) Which effect
# a preset uses, and when, is behavior/light.yaml's business, not this file's.
#
# The sunrise's auto-off is NOT here: it raises sunrise_done and api/light.yaml
# acts on it, because turning the light off is a write and writes belong to the
# api layer (also: calling turn_off from inside a running effect is asking for
# trouble).
#
# DEFINES  the crescent_* geometry substitutions below, crescent (light) and its
#          effects, sunrise_duration + sunrise_hold (numbers), sunrise_done +
#          sunrise_start_ms + cycle_start_ms (globals).
# CONSUMES the led_*, sunrise_*, cycle_*, rainbow_* and pin_crescent_data
#          settings.
# WRITTEN BY api/light.yaml ONLY.
# =====================================================================

# ---------------------------------------------------------------------
# THE GEOMETRY, DEFINED ONCE. These are substitutions rather than settings, and
# they live HERE rather than in settings.yaml, because they are not tunable -
# they are a copy of what 3d-print/enclosure_geom.py computes from the enclosure,
# and 3d-print/check_docs.py fails the build if they drift from it.
#
# THEY ARE SUBSTITUTIONS RATHER THAN C++ LITERALS FOR ONE REASON: two effects
# below need them, and until this block existed each effect carried its OWN copy
# of the row array. check_docs.py used re.search, so it asked only "is the right
# array in this file somewhere" - which one correct copy satisfied while the
# other sat next to it being wrong. That is the same trap the row-pitch note
# further down records falling into. One definition cannot half-drift.
#
# ============================ THE ROW LAYOUT ============================
# LEDs per row, DATA-LINE order, BOTTOM row first. Sum == num_leds.
# FLATTENED half-ellipse crescent, 89 x 62.7 semi-axes. The flat side is down,
# so the widest row is row 0. Row counts are limited by whichever binds first:
# the LED body staying inside the diffuser, or the RIBBON (n x 16.5mm) fitting
# the cavity. On rows 0, 2 and 4 it is the ribbon.
#   row 0: 177.8mm -> 10   row 3: 150.0mm -> 8
#   row 1: 174.1mm -> 10   row 4: 126.3mm -> 7
#   row 2: 165.2mm ->  9   row 5:  87.7mm -> 4   total 48
#
# >>> ROWS ARE ONLY 10.4mm APART -- they BUTT, ribbon edge to ribbon edge --
# >>> against 16.5mm between pixels along a row. THE ROW PITCH IS 10.4, NOT 16.5.
# >>> Vertical gradients therefore have well under half the physical travel a
# >>> square grid would give, so any effect that sweeps up the crescent will look
# >>> much faster vertically than horizontally unless it compensates, and any
# >>> effect that uses row/column INDICES rather than these pitches will squash
# >>> its bands vertically.
#
# If the strip is laid serpentine, every ODD row runs right-to-left. The sunrise
# only fills whole rows so that does not matter to it, but it will for any effect
# with horizontal structure. Rainbow Arch sidesteps it by using x^2.
# ------------------------------------------------------------------------
substitutions:
  crescent_rows: "10, 10, 9, 8, 7, 4"
  crescent_pitch_x: "16.5"     # mm between pixels along a row
  crescent_pitch_y: "10.4"     # mm between rows
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

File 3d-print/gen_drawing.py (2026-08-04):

#!/usr/bin/env python3
"""SHEET 1 of 3 -- the shell. Third-angle: TOP / FRONT / RIGHT SIDE / REAR,
assembled and exploded.

Geometry and dimensions live in enclosure_geom.py; SVG helpers in drawlib.py.
Companion sheets: gen_internals.py (sheet 2), gen_wiring.py (sheet 3).

Render a preview with:
    rsvg-convert -b white -z 2 enclosure-drawing.svg -o enclosure-drawing.png
"""
import math
import os

from drawlib import *
from enclosure_geom import *


def qt_note(bw, bh):
    """Mounting-hole callout for an Adafruit STEMMA QT breakout.

    >>> THE PITCH, NOT THE INSET, AND NOT THROUGH dt(). Written as "4x M2.5
    >>> {dt(QT_HOLE_INSET)} in from each edge" it renders as "4x M2.5 2.5 in from
    >>> each edge" -- dt() gives one decimal, so the 2.54 inset comes out as a
    >>> second 2.5 and the callout has two different 2.5s in six words. The pitch
    >>> is also the thing you can actually put a caliper on to check a board
    >>> against the part; the inset is a derivation of it.
    """
    return (f"4x {chr(216)}{QT_HOLE_D} on {bw - 2*QT_HOLE_INSET:.2f} x "
            f"{bh - 2*QT_HOLE_INSET:.2f}")


# ============================================================== FRONT VIEW






def front_dome():
    """Outer skin, then the LIP inner edge -- that is the visible aperture.
    The front module sits BEHIND the lip, so its own outline is hidden."""
    o = [path(d_profile(0, R_BOT), "obj")]
    o.append(path(d_profile(WALL + LIP_W, max(R_BOT - WALL - LIP_W, 1)), "obj"))
    return o


def front_knob():
    return ([path(knob_profile(W/2, fy(H)), "obj"),
             line(W/2 - KNOB_BOSS_D/2, fy(H), W/2 + KNOB_BOSS_D/2, fy(H), "hid")]
            + knob_bore(W/2, fy(H)))



def front_touch():
    """The shoulder pads, seen head-on. Foreshortened: they wrap the crown."""
    o = []
    for tx in touch_x():
        o.append(rect(tx - TOUCH_PAD_W*0.36, fy(TOUCH_Y) - TOUCH_PAD_W*0.5,
                      TOUCH_PAD_W*0.72, TOUCH_PAD_W, "hid", 3))
    return o


def front_plate(cutouts=True):
    o = [path(d_profile(REVEAL, R_BOT - REVEAL), "hid")]
    if not cutouts:
        return o
    o.append(semi_e(W/2, fy(CRES_Y), CRES_R, CRES_RY))            # crescent diffuser
    o.append(rect(W/2-CLK_W/2, fy(CLK_Y+CLK_H/2), CLK_W, CLK_H, "obj", 2.0))
    for sx in (SPK_X, W-SPK_X):                                   # speaker grilles
        o.append(circ(sx, fy(SPK_Y), SPK_GRILLE))
    for mx in mic_x():                                            # 4x mic ports
        o.append(circ(mx, fy(MIC_Y), MIC_PORT_D))
    return o


def front_bottom_plate(dy=0.0):
    y = fy(0) - BP_T + dy
    return [rect((W-BP_W)/2, y, BP_W, BP_T, "obj", 1.5)]


def front_internals():
    o = []
    o.append(rect(W/2-TRAY_W/2, fy(CLK_Y+TRAY_H/2), TRAY_W, TRAY_H, "hid", 1))
    for sx in (SPK_X, W-SPK_X):
        o.append(rect(sx-SPK_BODY_W/2, fy(SPK_Y1), SPK_BODY_W, SPK_BODY_H, "hid", 2))
    o.append(rect(W/2-MIC_PCB_W/2, fy(MIC_Y+MIC_PCB_H/2), MIC_PCB_W, MIC_PCB_H, "hid"))
    # the UPS stands RIGHT of centre, not on the centreline
    o.append(rect(UPS_WALL_X-UPS_W/2, fy(BP_T+UPS_H), UPS_W, UPS_H, "hid"))
    return o


def front_dims():
    """Dimension columns: left  x=-11 / -19 / -28 / -38   right x=W+12 .. W+48
                          dims below  y=H+10 / H+22 / H+34
                          callouts    y=ROW1 / ROW2 / ROW3."""
    ROW1, ROW2, ROW3 = H + 46, H + 55, H + 64
    o = []
    o.append(cl_v(W/2, -8, H + 8))
    o.append(cl_h(-8, W + 8, fy(SPK_Y)))
    # envelope + plate outline
    o.append(dim_h(0, W, H + 34, ext=H))
    o.append(dim_h(REVEAL, W-REVEAL, H + 22, ext=H-REVEAL))
    o.append(dim_v(0, H, -28, ext=0))
    o.append(dim_v(REVEAL, H-REVEAL, -19, ext=REVEAL))
    # the concentric pair: shell arc R92 and crescent R80 share one centre
    o.append(f'<circle class="ctr" cx="{n(W/2)}" cy="{n(fy(ARCH_Y))}" r="1.6"/>')
    o.append(cl_h(W/2 - CRES_R - 14, W/2 + CRES_R + 14, fy(ARCH_Y)))
    o.append(leader(W/2 + ARCH_R*0.707, fy(ARCH_Y + ARCH_RY*0.707), 30, -44,
                    f"shell arch {dt(ARCH_R)} x {dt(ARCH_RY)} - FLATTENED "
                    f"(k={CROWN_K}), not a semicircle"))
    o.append(leader(W/2 + CRES_R*0.5, fy(ARCH_Y + CRES_RY*0.866), 54, -30,
                    f"diffuser {dt(CRES_R)} x {dt(CRES_RY)}, {dt(CRES_RIM)} rim"))
    # LED_RY, not LED_R, for the vertical offset -- the field is an ellipse, and
    # using the horizontal semi-axis put this leader 26 mm above the arc it
    # points at. There is also no fade band any more (CRES_FADE = 0): the field
    # IS the diffuser, and what matters instead is the clearance to its edge.
    o.append(leader(W/2 - LED_R*0.5, fy(ARCH_Y + LED_RY*0.866), -30, -44,
                    f"{dt(LED_R)} x {dt(LED_RY)} LED field = the diffuser, no "
                    f"fade band - {CRES_PX} px, tightest body-to-edge "
                    f"{dt(crescent_clearance())}", "end"))
    # (no 2xR dimension across the baseline -- it would run straight through the
    #  bottom LED row, and R + concentric + centre height already fix the arc)
    o.append(dim_v(fy(ARCH_Y), fy(0), W + 12, dt(ARCH_Y), ext=W/2+CRES_R))
    o.append(dim_v(fy(CRES_Y + CRES_RY), fy(0), W + 24, dt(CRES_Y+CRES_RY), ext=W/2))
    # clock aperture + matrix pair
    o.append(dim_h(W/2-CLK_W/2, W/2+CLK_W/2, H + 10, dt(CLK_W), ext=H))
    o.append(leader(W/2+CLK_W/2, fy(CLK_Y) - CLK_H/2, 78, -56,
                    f"clock aperture {dt(CLK_W)} x {dt(CLK_H)}"))
    o.append(leader(W/2+TRAY_W/2, fy(CLK_Y)+TRAY_H/2, 76, 20,
                    f"2x matrix {dt(MTX_BOARD_W)} x {dt(TRAY_H)} butted = "
                    f"{dt(TRAY_W)} - posts + clips, no tray"))
    o.append(dim_v(fy(CLK_Y), fy(0), -11, dt(CLK_Y), ext=W/2-CLK_W/2))
    # mic array band, above the clock
    o.append(cl_h(W/2 - MIC_PCB_W/2 - 8, W/2 + MIC_PCB_W/2 + 8, fy(MIC_Y)))
    o.append(dim_h(mic_x()[0], mic_x()[1], fy(MIC_Y) - 8, dt(MIC_PITCH), ext=fy(MIC_Y)))
    o.append(leader(mic_x()[0], fy(MIC_Y), -6, ROW2 - fy(MIC_Y),
                    f"{MIC_N}x {chr(216)}{dt(MIC_PORT_D)} mic port @ {dt(MIC_PITCH)} "
                    "- ReSpeaker Flex linear array (?)"))
    o.append(dim_v(fy(MIC_Y1), fy(MIC_Y0), W + 36, f"{dt(MIC_PCB_H)} mic band",
                   ext=W/2 + MIC_PCB_W/2))
    o.append(dim_v_out(fy(SPK_Y1), fy(MIC_Y0), W + 48, dt(GAP_MIC),
                       ext=W/2 + MIC_PCB_W/2))
    # speakers
    o.append(dim_h(0, SPK_X, H + 10, dt(SPK_X), ext=H))
    _gy = fy(SPK_Y) + SPK_GRILLE*0.354
    o.append(leader(SPK_X - SPK_GRILLE*0.354, _gy, -6, ROW3 - _gy,
                    f"2x grille {chr(216)}{dt(SPK_GRILLE)}  (driver {chr(216)}{dt(SPK_BODY_W)} ?)"))
    o.append(dim_h_out(SPK_X + SPK_BODY_W/2, W/2 - TRAY_W/2, fy(SPK_Y1) - 6,
                       f"{dt(CLR_SPK_TRAY)} clr", ext=fy(SPK_Y)))
    # knob
    o.append(cl_v(W/2, fy(H) - KNOB_H - 8, fy(H) + 6))
    _a, _b, _yc, _w0 = knob_ellipse()
    o.append(leader(W/2 + KNOB_D/2, fy(H) - _yc, 40, -18,
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

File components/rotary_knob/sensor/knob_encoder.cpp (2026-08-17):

#include "knob_encoder.h"
#include "esphome/core/log.h"

namespace esphome {
namespace rotary_knob {

static const char *const TAG = "rotary_knob.encoder";

void KnobEncoder::setup() {
  ESP_LOGCONFIG(TAG, "Setting up KnobHub rotary encoder...");
  this->parent_->enable_encoder(this->number_);
  this->publish_state(0);
}

void KnobEncoder::loop() {
  int32_t new_value;
  // A dropped read is silence, not movement: keep the last position and try
  // again next iteration. The hub's absolute count means nothing is lost.
  if (!this->parent_->get_encoder_position(this->number_, new_value))
    return;
  if (new_value < this->min_value_)
    new_value = this->min_value_;
  if (new_value > this->max_value_)
    new_value = this->max_value_;
  if (new_value == this->value_)
    return;
  this->value_ = new_value;
  this->publish_state(new_value);
}

}  // namespace rotary_knob
}  // namespace esphome

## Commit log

2026-07-24 fixes for high pass
    [faux-hatch.yaml]
2026-07-24 updates for github
    [soundmachine.min.yaml]
2026-07-24 Renamed a bit
    [soundmachine.min.yaml, soundmachine.yaml]
2026-07-24 Initial markdown references
    [soundmachine.yaml]
2026-07-24 charlieplexed matrix
    [soundmachine.yaml]
2026-07-24 Added dual matrix mode to test
    [soundmachine.yaml]
2026-07-25 update matrix usage
    [soundmachine.yaml]
2026-07-25 Use matrix more
    [soundmachine.yaml]
2026-07-26 audio increase and switching
2026-07-27 3d printing
    [matrix-front-plate.stl]
2026-07-27 Generating front tray
    [Matrix Front Plate.3mf, matrix-front-plate.stl, matrix-tray.stl]
2026-07-27 updated prints, still need to fix leds
    [enclosure_geom.py, gen_drawing.py, gen_internals.py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]
2026-07-27 Fix crescent LED distribution to fit within diffuser box; sync firmware array
    [enclosure_geom.py, lighting.yaml]
2026-07-28 added module stl
    [front-module.stl]
2026-07-28 Trying to split the front
    [Matrix Front Plate Left.3mf, front-module-L.stl, front-module-R.stl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]
2026-07-28 WIP for fitting 3d plates
    [Matrix Front Plate Left.3mf, front-module-L.stl, front-module-R.stl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]
2026-07-28 Resized WIP
    [front-module.stl]
2026-07-28 Working on LED plate
    [front-module.stl, led-carrier.stl, soundmachine.yaml]
2026-07-28 Improving front plate
    [Front Module.3mf, front-module.stl, led-carrier.stl]
2026-07-28 Dome fixes
    [bottom-plate.stl, dome.stl, front-module.stl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]
2026-07-28 Improvements for dome
    [Bottom Plate.3mf, Dome.3mf, LED Carrier.3mf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]
2026-07-29 fixing matrix mounts
    [Front Module.3mf, front-module.stl, matrix-testfit.stl]
2026-07-29 Using two matrix
    [soundmachine.yaml]
2026-07-29 Fixed battery logic
    [soundmachine.yaml]
2026-07-29 iterations on models
    [Bottom Plate.3mf, dome.stl, front-module.stl]
2026-07-29 updated subsitutions
    [soundmachine.yaml]
2026-07-29 matrix render button
2026-07-29 matrix version
    [Bottom Plate.3mf, Dome.3mf, Front Module.3mf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]
2026-07-29 work on dome and bottom plate
    [Bottom Plate.3mf, Dome.3mf, LED Carrier.3mf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]
2026-07-29 bottom plate improvements
    [Bottom Plate.3mf, bottom-plate.stl]
2026-07-30 Working on matrix fixes
    [Matrix Testfit.3mf, bottom-plate.stl, front-module.stl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]
2026-07-30 include gutter
    [front-module.stl, matrix-testfit.stl]
2026-07-30 Fixing a few front plate parts
    [Dome.3mf, Front Module.3mf, LED Carrier.3mf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]
2026-07-30 Updates to knob neopixel
    [soundmachine.yaml]
2026-07-30 Updated models with correct screw holes
    [Bottom Plate.3mf, Dome.3mf, Knob.3mf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]
2026-07-31 dome and baffle fixes
    [Dome.3mf, Front Module.3mf, Knob.3mf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]
2026-08-04 package updates for battery charging
    [soundmachine.yaml]
2026-08-04 Model updates
    [Dome.3mf, dome.stl]
2026-08-04 Dome update
    [Dome.3mf]
2026-08-04 more ToF flapping fixes
    [settings.yaml]
2026-08-05 modeling fixes
    [Bottom Plate.3mf, Dome.3mf, Knob.3mf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]
2026-08-06 Fixed dome
    [Dome.3mf, dome.stl]
2026-08-10 touch fixes
    [Knob.3mf]
2026-08-10 Updated battery
2026-08-12 some sound and tof sensors
2026-08-12 Trying to fix audio
    [audio_chain.yaml, settings.yaml]
2026-08-12 Trying to fix the crescent
    [crescent.yaml]
2026-08-12 power battery display
2026-08-12 Audio refactors
    [soundmachine.yaml]
